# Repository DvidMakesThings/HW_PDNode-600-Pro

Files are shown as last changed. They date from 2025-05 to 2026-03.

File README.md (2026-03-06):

# PDNode-600 Pro  
## High-Performance USB PD Power Distribution Unit – 10" Rackmount



## Description  
[ENERGIS](https://github.com/DvidMakesThings/HW_10-In-Rack_PDU) is the 230V managed PDU project. PDNode-600 Pro is the modular DC/USB-C sibling for setups
where mains switching is not desired, but controllable, rack-friendly power output is still needed.

The PDNode-600 is a professional-grade, 600W USB Power Delivery Unit designed specifically for compact 10-inch rack systems, targeting embedded developers, homelab enthusiasts, test benches, and smart infrastructure. It delivers regulated, high-current power across 8x independent USB-C PD outputs and 4x fixed 5V USB-A outputs.

At the core of the PDNode platform is a centralized industrial-grade 24V/25A power supply, distributing regulated DC to dedicated per-port buck or buck-boost converters. Each USB-C port is managed by an MPQ4242-AEC1 PD controller, enabling clean, autonomous negotiation of power profiles up to 20V @ 3A or 5A with eMarker cable support. All power conversion, protection, and monitoring are designed to meet high reliability and safety standards.

The PDNode-600 Pro, by contrast, is built for remote-managed racks and headless environments, featuring Ethernet connectivity, a clean web-based UI, SNMP integration, and firmware updates via USB-C. Doing this by using [BladeCore-M54E](https://github.com/DvidMakesThings/HW_BladeCore-M54E)

## Web UI sneak peek

Interactive playground (dummy UI):
- https://dvidmakesthings.github.io/HW_PDNode-600-Pro/playground/

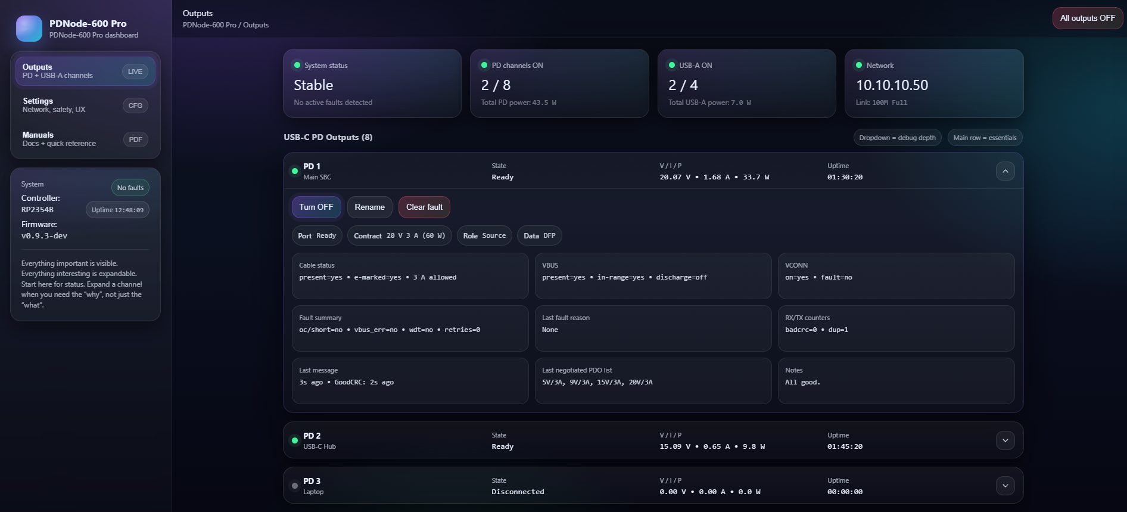
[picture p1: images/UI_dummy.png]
Try out the UI


## Project timeline estimation

Status legend: ✅ Completed · 🟠 Ongoing · 🔵 Planned

| #  | Milestone | Planned Start | Planned End | Status | Notes |
|:--:|---|---|---|---|---|
| 1  | Architecture definition | 12-2025 | 01-2026 | ✅ Completed | |
| 2  | Baseboard PCB design | 15-02-2026 | TBD | ✅ Completed | |
| 3  | PD card PCB design | 25-02-2026 | TBD | ✅ Completed | |
| 4  | Documentation | 12-2025 | 2026.12 | 🟠 Ongoing | |
| 5  | PCB ordering | 01-03-2026 | 31-03-2026  | ✅ Completed | Waiting for arrival |
| 6  | Prototyping and hardware bring-up | 03-2026 | 30-04-2026  | 🟠 Ongoing | |
| 7  | Firmware bring-up (slot scan, mux, PD iface) | 06-2026 | 11-2026 | 🔵 Planned | |
| 8  | Telemetry and status reporting | 06-2026 | 11-2026 | 🔵 Planned | |
| 9  | Validation (load, thermal, long-run) | 06-2026 | 11-2026 | 🔵 Planned | |
| 10 | Integration and polishing | 06-2026 | 11-2026 | 🔵 Planned | |
| 11 | Release package and final docs | 11-2026 | 12-2026 | 🔵 Planned | |

## Specifications 

### Input
- **Input voltage:** 230 VAC, max 4A 
- **System topology:** 24V distribution on the baseboard, per-slot conversion on PD cards

### Output (per PD card / per slot)
- **8x independent USB-C PD source**:
  - 5V 3A (5A only with 5A e-marked cable)
  - 9V 3A (5A only with 5A e-marked cable)
  - 12V 3A (5A only with 5A e-marked cable)
  - 15V 3A (5A only with 5A e-marked cable)
  - 20V 3A (5A only with 5A e-marked cable)
  - (Total power output cannot exceed 600W)
- **4x USB-A source** up to **5V / 1A** per port (depending on configuration and limits)

---

## Features
- **8x independent USB-C PD source ports** (modular PD cards, one port per slot)
- **Per-port PD profiles**
- **Total system capability: up to 600W** (shared input power budget)
- **4x USB-A auxiliary outputs** (5V, 1A per port) for low-power devices
- **Ethernet connectivity** for control / monitoring
- **USB service interface** (debug, configuration, firmware update, or log access depending on implementation)
- **Per-port power monitoring** (current/voltage telemetry via onboard sensing)
- **Per-port status reporting** (PGOOD / fault indication, and software-readable status)
- **Hot-swappable slot concept** (cards can be replaced without redesigning the baseboard)

---

## Hardware architecture

### Baseboard
- 24V DC input from industrial power supply
- Power distribution to all slots (high-current bus)
- Slot connectors + slot management (card detect, enable, status aggregation)
- I2C fanout per slot (mux) for monitoring and controlling devices
- Ethernet interface for user interaction
- USB/service interface for debug/config/updates
- 4x USB-A outputs
- 8x USB-C PD outputs

### [BladeCore-M54E](https://github.com/DvidMakesThings/HW_BladeCore-M54E)
- RP2354B microcontroller
- External QSPI flash memory
- External I²C EEPROM
- 100BASE Ethernet via W5500
- Dual‑path USB connectivity with automatic source selection
- Onboard power regulation and defined power‑up sequencing
- Compact M.2 M-key form factor

### PD Card
- 1x USB-C PD source port (one card = one port)
- Local power conversion to generate VBUS from the 24V bus
- PD controller + USB-C port control signals (enable, reset, IRQ)
- Per-port current/voltage measurement
- Per-port power good / fault status output
- Optional ID EEPROM footprint (DNI) for traceability/calibration

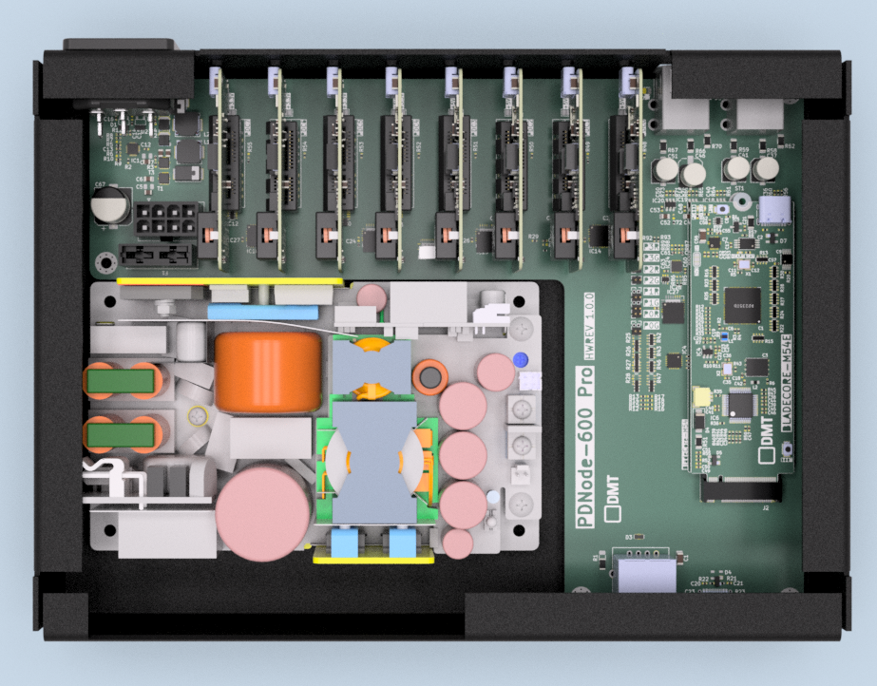
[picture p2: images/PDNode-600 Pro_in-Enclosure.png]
PDNode-600 Pro in Enclosure

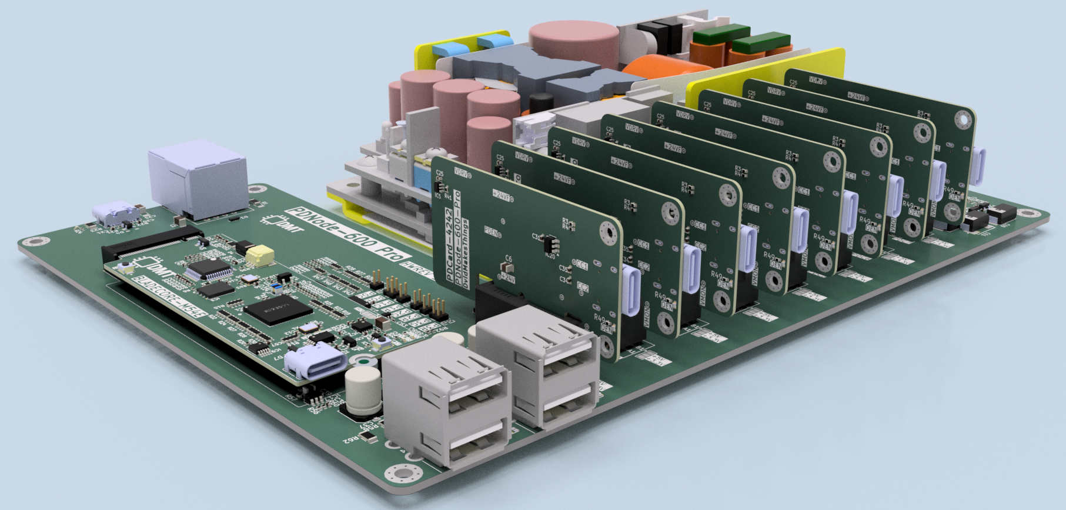
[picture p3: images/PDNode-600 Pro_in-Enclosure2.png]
PDNode-600 Pro in Enclosure


## Schematics
The full schematics are available:
- **[Baseboard Schematics](src/PDF/SCH_PDNode_Baseboard_100.pdf)** 
- **[PDCard-4242 Schematics](src/PDF/SCH_PDCard-4242_100.pdf)**
- **[BladeCore-M54E Schematics](src/PDF/SCH_BladeCore-M54_100.pdf)**

PCB Documentation:
- **[Baseboard PCB](src/PDF/PCB_PDNode_Baseboard_100.pdf)** 
- **[PDCard-4242 PCB](src/PDF/PCB_PDCard-4242_100.pdf)**
 **[]()**

---

## Development Phases (Hardware + Firmware)

| Hardware Phase | Status | Firmware Phase | Status |
| --- | --- | --- | --- |
| Architecture definition | ✅ Completed | Slot scan concept (TCA9548A) | 🔵 Planned |
| Baseboard PCB Design | ✅ Completed | I2C driver + mux control | 🔵 Planned |
| PD Card PCB Design | ✅ Completed | INA219 monitoring | 🔵 Planned |
| Documentation | 🟠 Ongoing | PD controller interface (SPI + GPIO) | 🔵 Planned |
| PCB ordering | ✅ Completed | Telemetry + status reporting | 🔵 Planned |
| Prototyping and Hardware Bring-up | 🟠 Ongoing | Bring-up scripts / debug tooling | 🔵 Planned |
| Validation (load, thermal, long-run) | 🔵 Planned | Error handling + fault reporting | 🔵 Planned |
| Production optimization | 🔵 Planned | Integration and polishing | 🔵 Planned |

---

## Changelog 
#### Rev0.1.0:
- Initial design
- STUSB4710 controller + TPS552882

#### Rev1.0.0:
- Full redesign. STUSB4710 became EOL, need to use different PD controller
- New concept: modular Baseboard + PDCard architecture
- PDCard power stage (MPQ4242-AEC1)
- Baseboard: Per-slot I2C muxing (TCA9548A)
- Optional per-card EEPROM (not used, but capable)

<table>
  <tr>
    <td align="center">
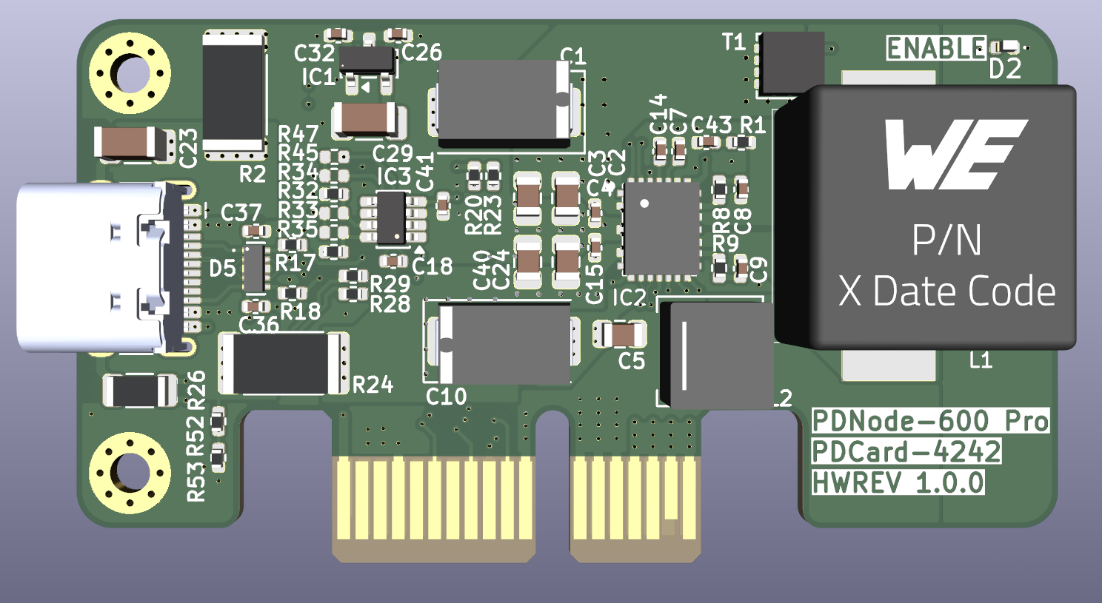
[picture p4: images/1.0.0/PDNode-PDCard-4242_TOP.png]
PDCard 3D Top View
      
      <br><b>PDCard Top</b>
    </td>
    <td align="center">
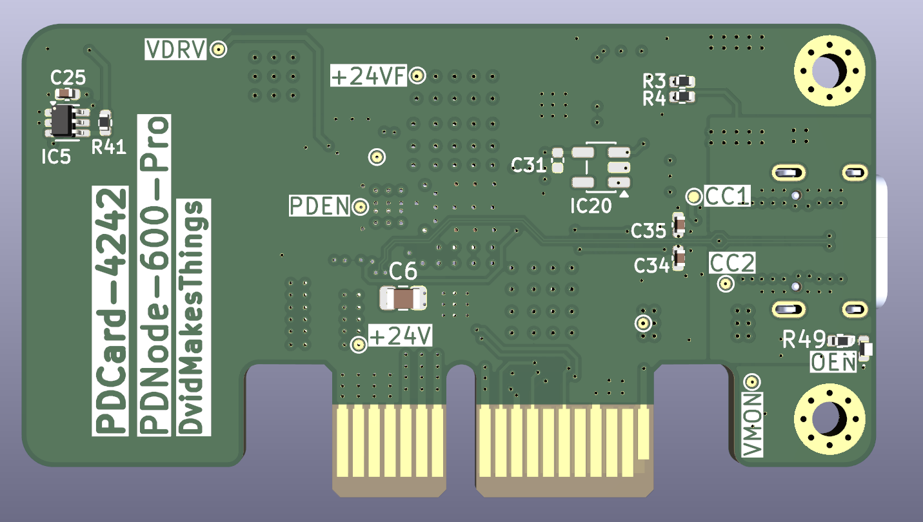
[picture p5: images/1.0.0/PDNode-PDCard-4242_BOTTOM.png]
PDCard 3D Bottom View
      
      <br><b>PDCard Bottom</b>
    </td>
  </tr>
  <tr>
    <td align="center" width="50%">
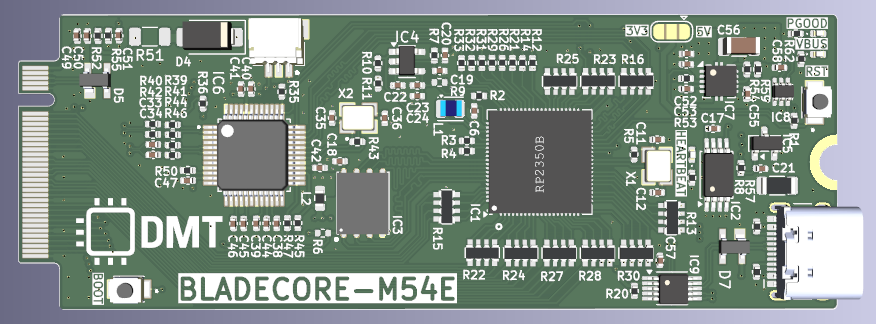
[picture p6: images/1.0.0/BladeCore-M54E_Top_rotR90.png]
BladeCore-M54E Top View
      
      <br><b>BladeCore-M54E Top</b>
    </td>
    <td align="center" width="50%">
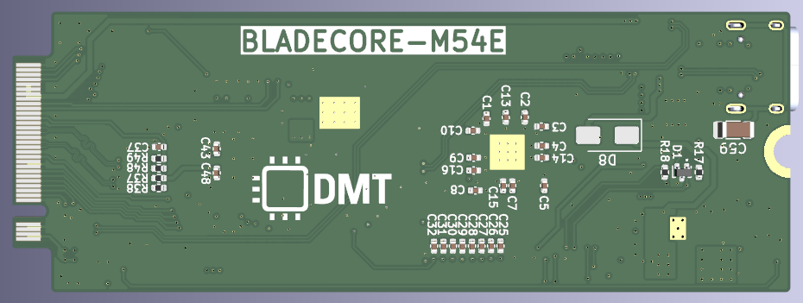
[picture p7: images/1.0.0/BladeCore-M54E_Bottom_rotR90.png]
BladeCore-M54E Bottom View
      
      <br><b>BladeCore-M54E Bottom</b>
    </td>
  </tr>
  <tr>
    <td align="center">
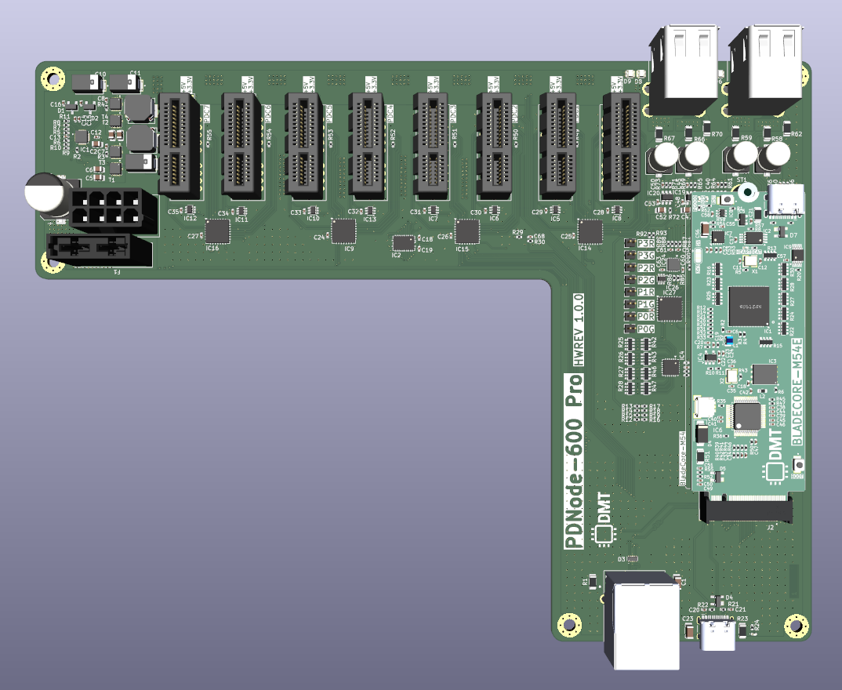
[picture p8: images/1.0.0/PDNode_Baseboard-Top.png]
BaseBoard 3D Top View
      
      <br><b>BladeCore-M54E Top</b>
    </td>
    <td align="center">
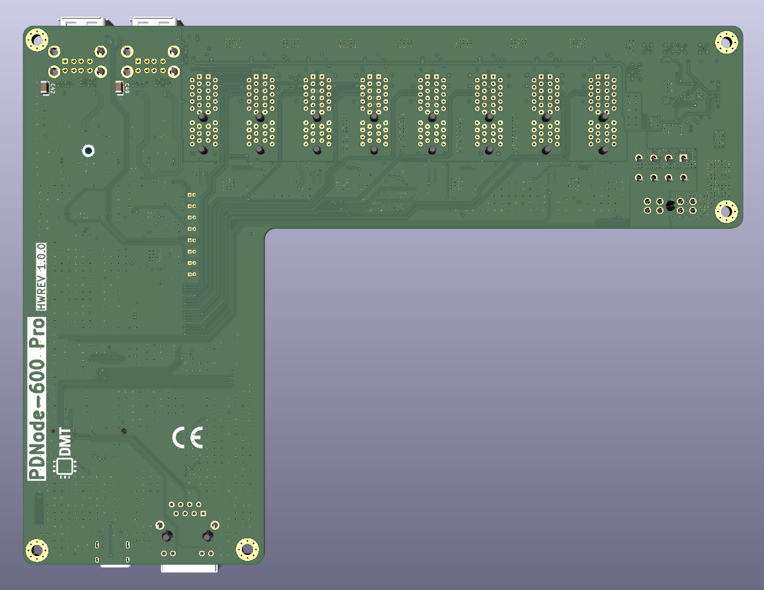
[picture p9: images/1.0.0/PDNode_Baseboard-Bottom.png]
BaseBoard 3D Bottom View
      
      <br><b>BladeCore-M54E Bottom</b>
    </td>
  </tr>
</table>

## License
### Software Components
This project's software is licensed under the **GNU Affero General Public License v3.0 (AGPL-3.0)**.
See the [Software License](LICENSE-AGPL) file for details.

#### What AGPL-3.0 means:

- ✅ **You can** freely use, modify, and distribute this software
- ✅ **You can** use this project for personal, educational, or internal purposes
- ✅ **You can** contribute improvements back to this project

- ⚠️ **You must** share any modifications you make if you distribute the software
- ⚠️ **You must** release the source code if you run a modified version on a server that others interact with
- ⚠️ **You must** keep all copyright notices intact

- ❌ **You cannot** incorporate this code into proprietary software without sharing your source code
- ❌ **You cannot** use this project in a commercial product without either complying with AGPL or obtaining a different license

### Hardware Components
Hardware designs, schematics, and related documentation are licensed under the **Creative Commons Attribution-NonCommercial-ShareAlike 4.0 International License (CC BY-NC-SA 4.0 International License)**. See the [Hardware License](LICENSE-CC-BY-NC-SA) file for details.

#### What CC BY-NC-SA 4.0 means:

- ✅ **You can** study, modify, and distribute the hardware designs
- ✅ **You can** create derivative works for personal, educational, or non-commercial use
- ✅ **You can** build this project for your own personal use

- ⚠️ **You must** give appropriate credit and indicate if changes were made
- ⚠️ **You must** share any modifications under the same license terms
- ⚠️ **You must** include the original license and copyright notices

- ❌ **You cannot** use the designs for commercial purposes without explicit permission
- ❌ **You cannot** manufacture and sell products based on these designs without a commercial license
- ❌ **You cannot** create closed-source derivatives for commercial purposes
- ❌ **You cannot** use the designer's trademarks without permission

### Commercial & Enterprise Use

Commercial use of this project is prohibited without obtaining a separate commercial license. If you are interested in:

- Manufacturing and selling products based on these designs
- Incorporating these designs into commercial products
- Any other commercial applications

Please contact me through any of the channels listed in the [Contact](#contact) section to discuss commercial licensing arrangements. Commercial licenses are available with reasonable terms to support ongoing development.

## Contact

For questions or feedback:
- **Email:** [dvidmakesthings@gmail.com](mailto:dvidmakesthings@gmail.com)
- **GitHub:** [DvidMakesThings](https://github.com/DvidMakesThings)

## Contributing

Contributions are welcome! As this is an early-stage project, please reach out before 
making substantial changes:

1. Fork the repository
2. Create a feature branch (`git checkout -b feature/concept`)
3. Commit your changes (`git commit -m 'Add concept'`)
4. Push to the branch (`git push origin feature/concept`)
5. Open a Pull Request with a detailed description

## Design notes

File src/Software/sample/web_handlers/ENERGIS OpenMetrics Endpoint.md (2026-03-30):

# ENERGIS OpenMetrics Endpoint

## Overview

The ENERGIS PDU exposes a `/metrics` HTTP endpoint that provides runtime telemetry in OpenMetrics/Prometheus text format (version 0.0.4). This plugs directly into Prometheus, Grafana, and similar tools.

## Configuration

### Accessing the Endpoint

```bash
curl.exe http://<pdu-ip-address>/metrics
```

### Example response

```
# HELP energis_up 1 if the metrics handler is healthy.
# TYPE energis_up gauge
energis_up 1
# HELP energis_build_info Build and device identifiers.
# TYPE energis_build_info gauge
energis_build_info{version="1.0.0",serial="SN-0167663"} 1
# HELP energis_uptime_seconds_total System uptime in seconds.
# TYPE energis_uptime_seconds_total counter
energis_uptime_seconds_total 27
# HELP energis_internal_temperature_celsius Internal temperature (calibrated).
# TYPE energis_internal_temperature_celsius gauge
energis_internal_temperature_celsius 30.668
# HELP energis_temp_calibrated 1 if temperature calibration is applied.
# TYPE energis_temp_calibrated gauge
energis_temp_calibrated 1
# HELP energis_temp_calibration_mode Calibration mode: 0=none, 1=1pt, 2=2pt.
# TYPE energis_temp_calibration_mode gauge
energis_temp_calibration_mode 1
# HELP energis_vusb_volts USB rail voltage.
# TYPE energis_vusb_volts gauge
energis_vusb_volts 5.332
# HELP energis_vsupply_volts 12V supply rail voltage.
# TYPE energis_vsupply_volts gauge
energis_vsupply_volts 12.093
# HELP energis_http_requests_total Total HTTP requests served.
# TYPE energis_http_requests_total counter
energis_http_requests_total 17
# HELP energis_channel_state Relay state (1=ON, 0=OFF).
# TYPE energis_channel_state gauge
energis_channel_state{ch="1"} 1
# HELP energis_channel_telemetry_valid 1 if cached telemetry for channel is fresh.
# TYPE energis_channel_telemetry_valid gauge
energis_channel_telemetry_valid{ch="1"} 1
# HELP energis_channel_voltage_volts Channel voltage.
# TYPE energis_channel_voltage_volts gauge
energis_channel_voltage_volts{ch="1"} 0.000
# HELP energis_channel_current_amps Channel current.
# TYPE energis_channel_current_amps gauge
energis_channel_current_amps{ch="1"} 0.000
# HELP energis_channel_power_watts Active power per channel.
# TYPE energis_channel_power_watts gauge
energis_channel_power_watts{ch="1"} 0.000
# HELP energis_channel_energy_watt_hours_total Accumulated energy per channel.
# TYPE energis_channel_energy_watt_hours_total counter
energis_channel_energy_watt_hours_total{ch="1"} 0.000
...
```

## Prometheus Integration

Add to `prometheus.yml`:

```yaml
scrape_configs:
  - job_name: 'energis-pdu'
    scrape_interval: 15s
    scrape_timeout: 10s
    metrics_path: /metrics
    static_configs:
      - targets: ['192.168.0.22:80']
        labels:
          location: 'rack-1'
          device: 'pdu-main'
```

## Available Metrics

### System

* `energis_up` - Health indicator (gauge; 1 if handler responds)
* `energis_build_info{version,serial}` - Build and device info (gauge; always 1)
* `energis_uptime_seconds_total` - Uptime since boot in seconds (counter)
* `energis_internal_temperature_celsius` - Internal MCU temperature, calibrated (gauge)
* `energis_temp_calibrated` - 1 if temperature calibration is applied (gauge)
* `energis_temp_calibration_mode` - Calibration mode (0=none, 1=1pt, 2=2pt) (gauge)
* `energis_vusb_volts` - USB rail voltage (gauge)
* `energis_vsupply_volts` - 12 V rail voltage (gauge)
* `energis_http_requests_total` - Total HTTP requests served (counter)

### Per-Channel (ch = "1" ... "8")

* `energis_channel_state{ch}` - Relay state: 1=ON, 0=OFF (gauge)
* `energis_channel_telemetry_valid{ch}` - 1 if cached telemetry for channel is fresh (gauge)
* `energis_channel_voltage_volts{ch}` - Channel voltage [V] (gauge)
* `energis_channel_current_amps{ch}` - Channel current [A] (gauge)
* `energis_channel_power_watts{ch}` - Active power [W] (gauge)
* `energis_channel_energy_watt_hours_total{ch}` - Accumulated energy in watt-hours (counter)

## Notes and Behavior

* Values are served from cached snapshots owned by `MeterTask`. No direct sensor I/O in the handler.
* Temperature uses the active calibration. If no calibration is stored, defaults are used.

## Handy PromQL

* MCU temperature:
  `energis_internal_temperature_celsius`
* Rails:
  `energis_vusb_volts`, `energis_vsupply_volts`
* Total active power across all channels:
  `sum(energis_channel_power_watts)`
* Telemetry freshness check:
  `sum(energis_channel_telemetry_valid) == 8`

## Example Alerts

```yaml
groups:
- name: energis
  rules:
  - alert: EnergisHighTemp
    expr: energis_internal_temperature_celsius > 70
    for: 2m
    labels: {severity: warning}
    annotations:
      summary: "ENERGIS MCU hot >70C"

  - alert: EnergisVsupplyLow
    expr: energis_vsupply_volts < 10.8
    for: 1m
    labels: {severity: critical}
    annotations:
      summary: "ENERGIS 12V rail low"

  - alert: EnergisNoTelemetry
    expr: sum(energis_channel_telemetry_valid) < 8
    for: 2m
    labels: {severity: warning}
    annotations:
      summary: "ENERGIS channel telemetry not fully valid"
```

## Performance

* Static buffer ~4 KB. No heap allocations.
* Non-blocking, minimal CPU load.
* Typical response time < 50 ms.
* If the output would overflow the buffer, the handler returns **503** to encourage a retry instead of serving a partial payload.

## Implementation Notes

* Reads from `MeterTask_GetTelemetry()` and `MeterTask_GetSystemTelemetry()`.
* Uses atomic counters for request accounting.
* OpenMetrics text format compatible with Prometheus 0.0.4.

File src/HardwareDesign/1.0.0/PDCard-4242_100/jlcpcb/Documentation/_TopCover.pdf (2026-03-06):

## PDCard-4242 Schematic Documentation

| Top Preview | Bottom Preview |

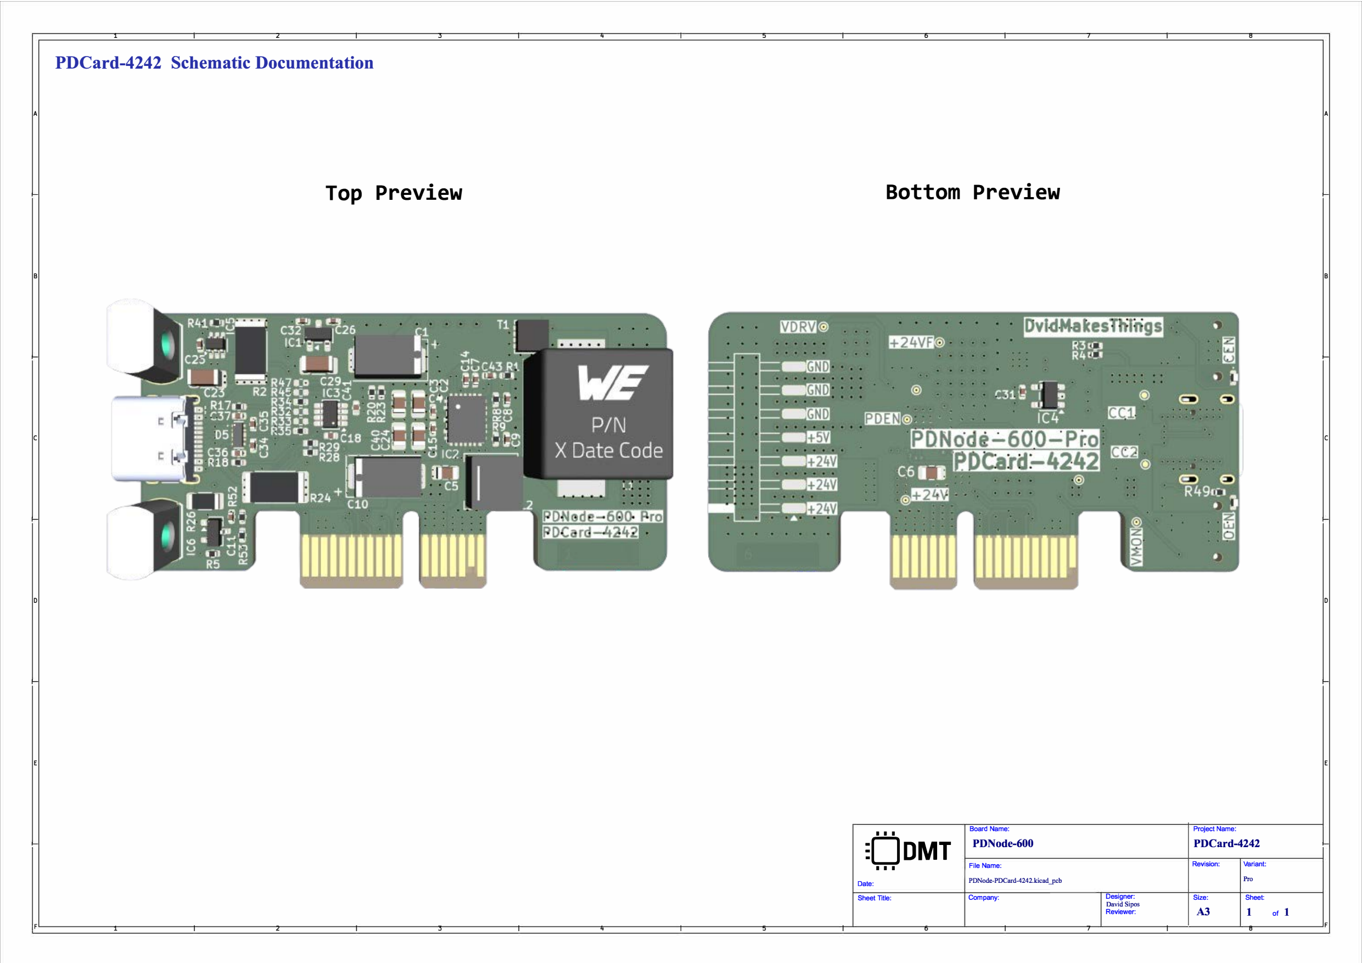
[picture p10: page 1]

1 | I | 2 | I | 3 | I | 4 | I | 5 | I | 6 | I | 7 | I | B
A | A
B | B
C | C
>- | >-
D | D
>- | >-
E | E
I I I | Board Name: | Project Name:
| :ODMT PDNode-600 | PDCard-4242 |
File Name: | Revision: | Variant:

I I I
Date: | PDNode-PDCard-4242.kicad_pcb | Pro
Sheet Title: | Company: | Designer: | Size: | Sheet:
David Sipos
Reviewer: | A3 | 1 | of 1
1 | I | 2 | I | 3 | I | 4 | I | 5 | I | 6 | I | 7 | I | B

F

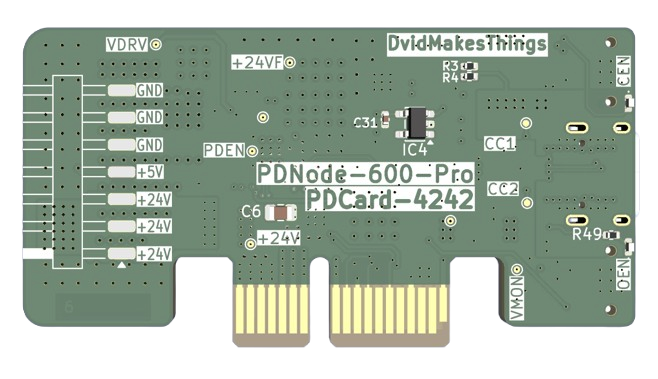
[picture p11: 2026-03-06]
src/HardwareDesign/1.0.0/PDCard-4242_100/Images/PDNode-PDCard-4242_BOTTOM-removebg-preview.png

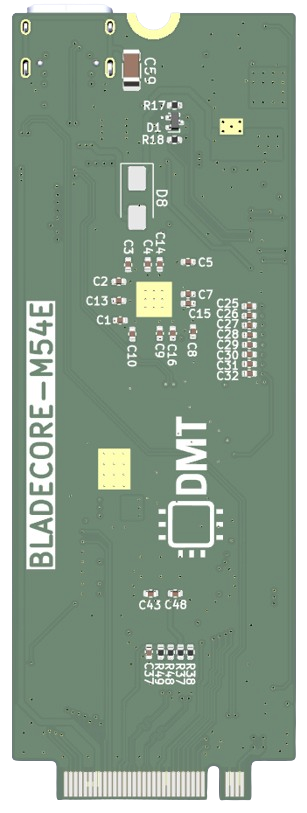
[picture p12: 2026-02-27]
src/HardwareDesign/1.0.0/BladeCore-M54_100/Images/BladeCore-M54E_Bottom-removebg.png

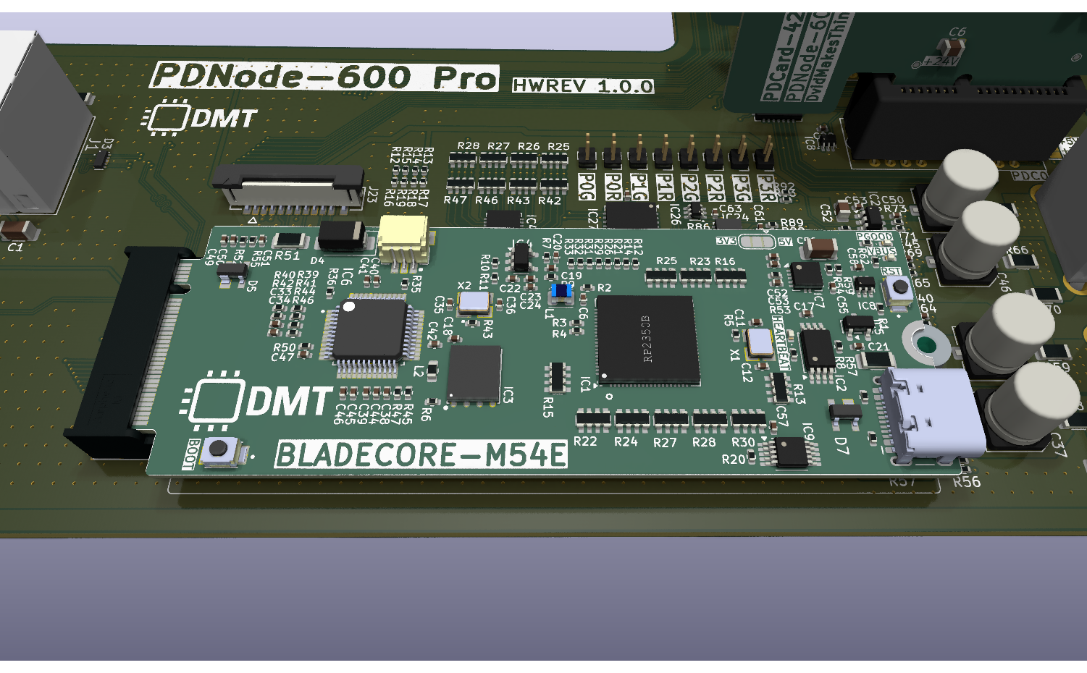
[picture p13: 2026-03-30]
src/HardwareDesign/1.0.0/PDNode-600_Pro_Baseboard_100/Images/PDNode_Baseboard2.png

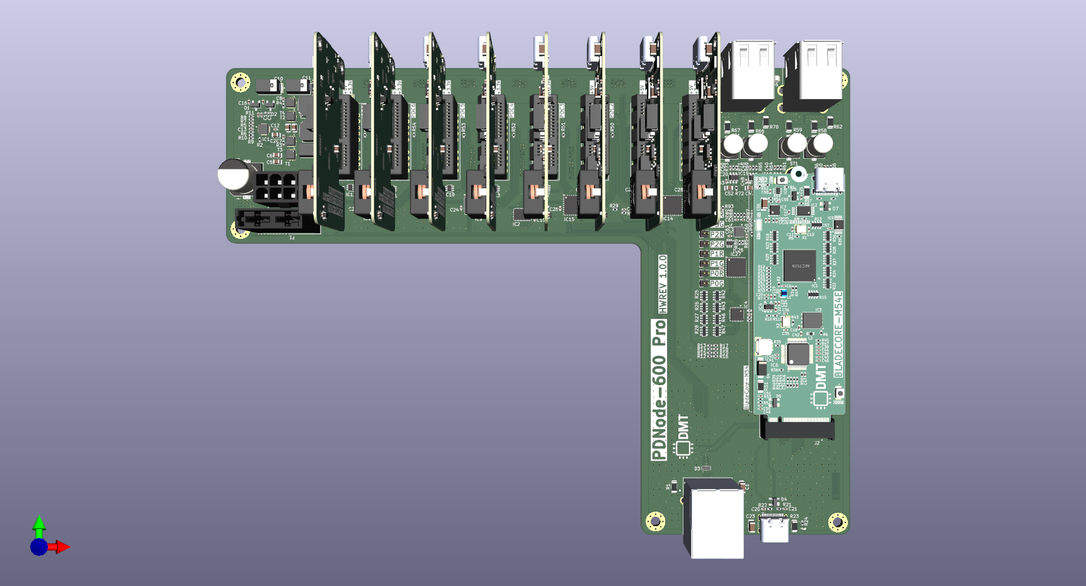
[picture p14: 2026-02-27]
src/HardwareDesign/1.0.0/PDNode-600_Pro_Baseboard_100/Images/PDNode_Baseboard-With_PDCard.png

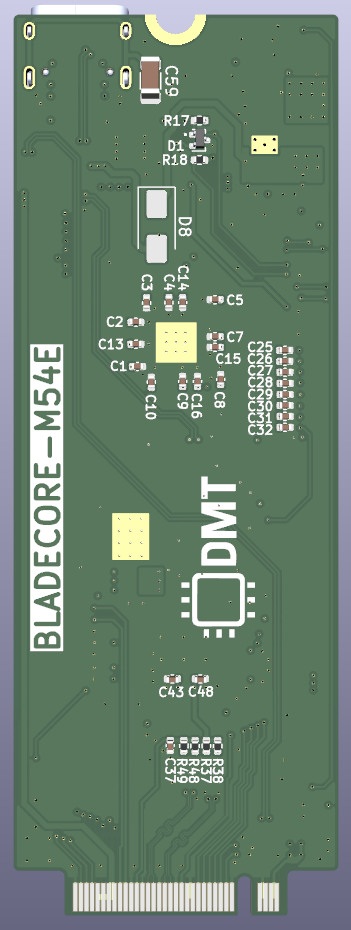
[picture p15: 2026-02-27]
src/HardwareDesign/1.0.0/BladeCore-M54_100/Images/BladeCore-M54E_Bottom.png

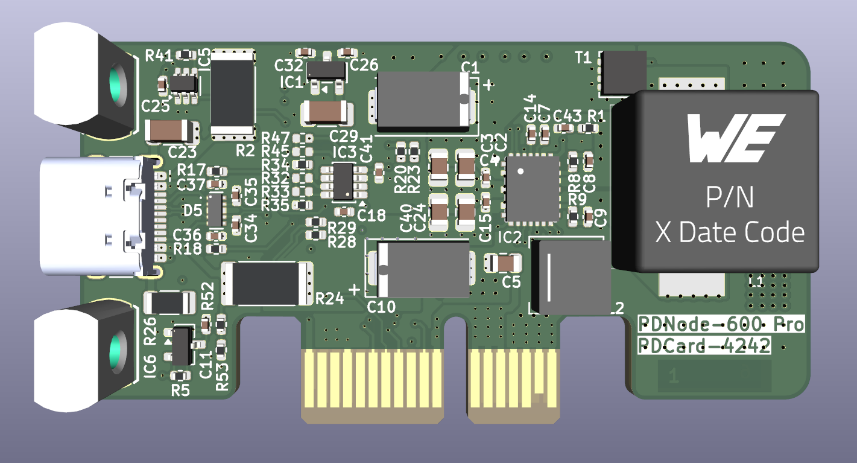
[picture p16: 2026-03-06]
src/HardwareDesign/1.0.0/PDCard-4242_100/Images/PDNode-PDCard-4242_TOP.png

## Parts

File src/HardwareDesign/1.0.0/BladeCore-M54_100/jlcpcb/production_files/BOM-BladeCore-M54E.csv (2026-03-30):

Comment | Designator | Footprint | LCSC | Quantity
0R 1% | R40,R42 | R_0402_1005Metric | C17168 | 2
0R 1% | R51 | R_1206_3216Metric | C205296 | 1
1.5K/100MHz 0.5R | L2 | R_0603_1608Metric | C82155 | 1
100R 1% | R13,R15,R16,R22,R23,R24,R25,R27,R28,R30 | R_Array_Convex_4x0603 | C136838 | 10
100R 1% | R12,R14,R21,R26,R29,R31,R32,R33 | R_0402_1005Metric | C25076 | 8
100nF 50V | C1,C10,C13,C14,C15,C17,C18,C19,C2,C21,C23,C3,C37,C38,C4,C40,C41,C42,C43,C44,C45,C46,C47,C48,C5,C51,C52,C57,C58,C60,C7,C8,C9 | C_0402_1005Metric | C307331 | 33
10K 1% | R10,R11,R53 | R_0402_1005Metric | C25744 | 3
10pF 50V | C11,C12 | C_0402_1005Metric | C466222 | 2
10uF 50V | C56 | C_1206_3216Metric | C13585 | 1
12.4K 1% | R50 | R_0402_1005Metric | C490814 | 1
12MHz 10pF | X1 | X3225 | C20625731 | 1
15pF 50V | C35,C36 | C_0402_1005Metric | C1548 | 2
1K 1% | R34,R5,R58,R60,R61 | R_0402_1005Metric | C11702 | 5
1M 1% | R57 | R_1206_3216Metric | C17927 | 1
1M 1% | R43 | R_0402_1005Metric | C26083 | 1
1nF 2kV | C59 | C_1206_3216Metric | C173242 | 1
1nF 50V | C25,C26,C27,C28,C29,C30,C31,C32 | C_0402_1005Metric | C14442 | 8
1uF 50V | C53 | C_0402_1005Metric | C1518208 | 1
2.2K 1% | R17,R18 | R_0402_1005Metric | C25879 | 2
2.2nF 50V | C55 | C_0402_1005Metric | C106861 | 1
2.4K 1% | R59 | R_0402_1005Metric | C25882 | 1
25MHz 12pF | X2 | X3225 | C9006 | 1
27R 1% | R7 | R_0402_1005Metric | C138021 | 1
3.3R 1% | R39,R41,R44,R46 | R_0402_1005Metric | C270612 | 4
3.3uH 2.8A | L1 | 0805 | C42411119 | 1
33R 1% | R2,R3,R4 | R_0402_1005Metric | C25105 | 3
4.7K 1% | R1,R35,R8 | R_0402_1005Metric | C25900 | 3
4.7uF 10V | C20,C22,C24 | C_0402_1005Metric | C368809 | 3
4.7uF 25V | C16,C39,C49,C50,C54,C6 | C_0402_1005Metric | C22367824 | 6
470R 1% | R36,R45,R47 | R_0402_1005Metric | C25117 | 3
49.9R 1% | R37,R38,R48,R49 | R_0402_1005Metric | C25120 | 4
5.1K 1% | R19,R20,R52,R55,R56 | R_0402_1005Metric | C25905 | 5
6.8nF 50V | C33,C34 | C_0402_1005Metric | C1542 | 2
7.5K 1% | R54 | R_0402_1005Metric | C25918 | 1
AT24C256C-XHL-T | IC2 | TSSOP-8 | C33035 | 1
B3U-1000P | SW1,SW2 | SW_B3U-1000P | C231329 | 2
Blue | D3 | LED_0402_1005Metric | C22355736 | 1
FSUSB42MUX | IC9 | MSOP-10_3x3mm_P0.5mm | C11355 | 1
Green | D10,D11,D6 | LED_0402_1005Metric | C965793 | 3
LM4040B30FTA | IC5 | SOT-23 | C460604 | 1
MCP6001RT | IC4 | SOT-23-5 | C154973 | 1
RCLAMP0582BQTCT | D1 | SOT-416 | C841193 | 1
RP2354B | IC1 | QFN80_10x10 | C39843328 | 1
SM03B-SRSS-TB | J2 | JST_SM03B-SRSS-TB_LF__SN_ | C160403 | 1
SN74LVC1G97QDCKRQ1 | IC10,IC8 | SOT-363_SC-70-6 | C179911 | 2
SP0503BAHTG | D5,D7 | SOT143 | C3040626 | 2
TPS74801DRCT | IC7 | VSON-10-1EP_3x3mm_P0.5mm_EP1.65x2.4mm_ThermalVias | C882845 | 1
USB-TYPE-C-018 | J3 | USB_C_Receptacle_HCTL_HC-TYPE-C-16P-01A | C2927038 | 1
W25Q128JVPIQ | IC3 | WSON8_6x5 | C190862 | 1
W5500 | IC6 | LQFP48_7x7 | C32843 | 1

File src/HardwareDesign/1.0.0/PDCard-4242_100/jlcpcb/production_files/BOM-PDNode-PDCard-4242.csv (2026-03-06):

Comment | Designator | Footprint | LCSC | Quantity
0.005R 1% 2W | R24 | R_2512_6332Metric | C108931 | 1
0.010R 1% | R2 | R_2512_6332Metric | C127692 | 1
0R 1% | R8,R9 | R_0402_1005Metric | C17168 | 2
100K 1% | R20,R23 | R_0402_1005Metric | C25741 | 2
100nF 50V | C11,C15,C18,C25,C31,C32,C4,C41 | C_0402_1005Metric | C307331 | 8
100uF 25V | C1,C10 | CP_EIA-7343-30_AVX-N | C696814 | 2
10K 1% | R34,R35,R5,R53 | R_0402_1005Metric | C25744 | 4
10uF 50V | C29 | C_1206_3216Metric | C13585 | 1
10uF 50V | C24,C40 | C_0805_2012Metric | C440198 | 2
1K 1% | R41,R49 | R_0402_1005Metric | C11702 | 2
1M 1% | R26 | R_1206_3216Metric | C17927 | 1
1R 1% | R1,R28,R29,R3,R4 | R_0402_1005Metric | C185446 | 5
1nF 2kV | C23 | C_1206_3216Metric | C173242 | 1
1nF 50V | C34,C35,C43 | C_0402_1005Metric | C14442 | 3
1uF 50V | C26 | C_0402_1005Metric | C1518208 | 1
2.2R 1% | R17,R18 | R_0402_1005Metric | C2909330 | 2
2.2uF 25V | C7 | C_0402_1005Metric | C385032 | 1
2.2uH 9.7A | L2 | 5.5x5.3mm_XAL5030-222MEC | C920280 | 1
220nF 50V | C8,C9 | C_0402_1005Metric | C5159775 | 2
390pF 50V | C36,C37 | C_0402_1005Metric | C107050 | 2
4.7uF 50V | C2,C3,C5,C6 | C_0805_2012Metric | C98192 | 4
4.7uH 13A | L1 | 7443551470 | C1331156 | 1
470pF 50V | C14 | C_0402_1005Metric | C106207 | 1
90.9K 1% | R52 | R_0402_1005Metric | C163452 | 1
Blue | D2 | LED_0402_1005Metric | C22355736 | 1
DMN4008LFG-7 | T1 | Diodes_PowerDI3333-8 | C6601822 | 1
Green | D1 | LED_0402_1005Metric | C965793 | 1
INA219BIDCNT | IC3 | SOT-23-8 | C2653868 | 1
M3 | ST1,ST2 | WP-SMRA_7466313 | C6467859 | 2
MCP1702T-3302E/CB | IC1 | SOT-23 | C33844 | 1
MPQ4242GVE-0001-AEC1-P | IC2 | QFN-22_4X5mm | C37449370 | 1
SN74LVC1G97QDCKRQ1 | IC5 | SOT-363_SC-70-6 | C179911 | 1
STM809TWX6F | IC6 | SOT-23 | C118271 | 1
TPD4EUSB30DQAR | D5 | USON10_2.5x1 | C5199222 | 1
USB-TYPE-C-018 | J1 | USB_C_Receptacle_HCTL_HC-TYPE-C-16P-01A | C2927038 | 1

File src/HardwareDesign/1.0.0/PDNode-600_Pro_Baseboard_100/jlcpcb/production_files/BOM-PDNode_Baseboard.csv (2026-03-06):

Comment | Designator | Footprint | LCSC | Quantity
0.02R 1% | R58,R59,R66,R67 | R_1206_3216Metric | C844895 | 4
0525592052 | J23 | CON_525592052_MOL | C588204 | 1
0ATO030.VP | F1 | 178.6165.0001-Littelfuse | C207060 | 1
10018784-10200TLF | J10,J11,J4,J5,J6,J7,J8,J9 | AMPHENOL_10018784-10210TLF | C5437695 | 8
100R 1% | R42,R43,R46,R47 | R_Array_Convex_4x0603 | C136838 | 4
100R 1% | R75,R79,R80,R81,R84,R87,R88,R89 | R_0402_1005Metric | C25076 | 8
100nF 50V | C14,C15,C16,C17,C19,C24,C25,C26,C27,C28,C29,C30,C31,C32,C33,C34,C35,C36,C39,C40,C44,C45,C48,C50,C53,C55,C56,C58,C60,C62,C63,C64,C65,C68,C7,C8 | C_0402_1005Metric | C307331 | 36
100uF 25V | C37,C41,C46,C51 | C_Elec_6.3x7.7 | C72477 | 4
10K 1% | R10,R11,R12,R13,R14,R15,R16,R17,R18,R19,R2,R48,R49,R50,R51,R52,R53,R54,R55,R7 | R_0402_1005Metric | C25744 | 20
10nF 50V | C54,C57,C59,C61 | C_0402_1005Metric | C60133 | 4
10uF 50V | C2,C3,C38,C4,C43,C47,C5,C52,C6 | C_0805_2012Metric | C440198 | 9
15.4K 1% | R5 | R_0402_1005Metric | C22369478 | 1
1724470208 | J22 | MOLEX_1724470208 | C17445611 | 1
1K 1% | R24,R74,R77,R82,R83,R90,R91,R92,R93 | R_0402_1005Metric | C11702 | 9
1M 1% | R1,R23,R62,R70 | R_1206_3216Metric | C17927 | 4
1nF 2kV | C1,C23,C42,C49 | C_1206_3216Metric | C173242 | 4
1nF 50V | C12,C13 | C_0402_1005Metric | C14442 | 2
2.2K 5% | R25,R26,R27,R28 | R_Array_Convex_4x0603 | C12001 | 4
2.2R 1% | R3,R4 | R_0402_1005Metric | C2909330 | 2
2.2uH 9.5A | L1 | 7x6.6mm | C167218 | 1
3.3uH 13A | L2 | 7x6.6mm | C41413136 | 1
33.2K 1% | R60,R64,R69,R73 | R_0402_1005Metric | C324836 | 4
330uF 50V | C67 | CP_Elec_10x10.5 | C178596 | 1
330uF 6.3V | C10,C11 | 2917 | C134173 | 2
33R 1% | R44,R45,R76,R78,R85,R86 | R_0402_1005Metric | C25105 | 6
4.7K 1% | R56,R57,R61,R63,R65,R68,R71,R72 | R_0402_1005Metric | C25900 | 8
4.7uF 25V | C18,C20,C21 | C_0402_1005Metric | C22367824 | 3
470uF 4V | C9 | 2917 | C542275 | 1
47K 1% | R9 | R_0402_1005Metric | C25792 | 1
5.1K 1% | R21,R22,R30 | R_0402_1005Metric | C25905 | 3
51K 1% | R29,R8 | R_0402_1005Metric | C25794 | 2
6.57K 0.1% | R6 | R_0402_1005Metric | C852899 | 1
AF SS-JB17.6 | J12,J13 | USB_A_Horizontal_Stacked | C456021 | 2
AP22653W6-7 | IC17,IC18,IC19,IC20 | SOT-23-6 | C2158037 | 4
BAT54S | D1,D2 | SOT23-3 | C7420333 | 2
Blue | D5 | LED_0402_1005Metric | C22355736 | 1
CD74HC4067QRGYRQ1 | IC2 | Texas_RGY_R-PVQFN-N24_EP2.05x3.1mm_ThermalVias | C48731605 | 1
FDMC7672 | T3,T4 | DFN8_3x3 | C890946 | 2
FDMC7692 | T1,T2 | DFN8_3x3 | C241798 | 2
J1B1211CCD | J1 | J1B1211CCD | C910371 | 1
M2.5 | ST1 | Round Standoff Threaded M2.5 Steel | C7435234 | 1
MCP23017T-E/ML | IC14,IC15,IC16,IC27,IC9 | QFN-28-1EP_6x6mm_P0.65mm_EP4.25x4.25mm_ThermalVias | C629439 | 5
MDT580M01001 | J2 | BladeCore-M54E-5.8mm | C5177196 | 1
PAC1720-1-AIA-TR | IC22,IC24 | DFN-10-1EP_3x3mm_P0.5mm_EP1.58x2.35mm_ThermalVias | C622574 | 2
Red-Green | D6,D7,D8,D9 | LED_0605-1613 | C965839 | 4
SN74LVC1G97QDCKRQ1 | IC10,IC11,IC12,IC13,IC21,IC23,IC25,IC26,IC5,IC6,IC7,IC8 | SOT-363_SC-70-6 | C179911 | 12
SP0503BAHTG | D4 | SOT143 | C3040626 | 1
TCA9548ARGER | IC4 | Texas_RGE0024C_VQFN-24-1EP_4x4mm_P0.5mm_EP2.1x2.1mm | C555456 | 1
TPD4EUSB30DQAR | D3 | USON10_2.5x1 | C5199222 | 1
TPS51225CRUKR | IC1 | QFN20-3x3 | C131684 | 1
USB-TYPE-C-018 | J3 | USB_C_Receptacle_HCTL_HC-TYPE-C-16P-01A | C2927038 | 1

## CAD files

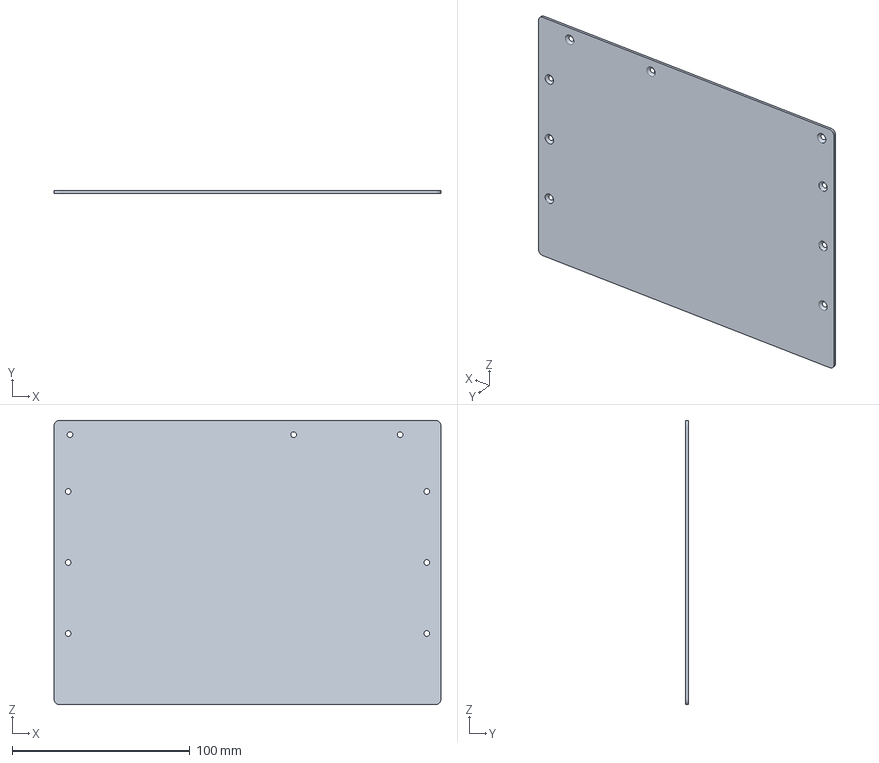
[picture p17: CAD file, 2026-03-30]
images/Top Lid.3mf
218.0 x 1.50 x 160.0 mm

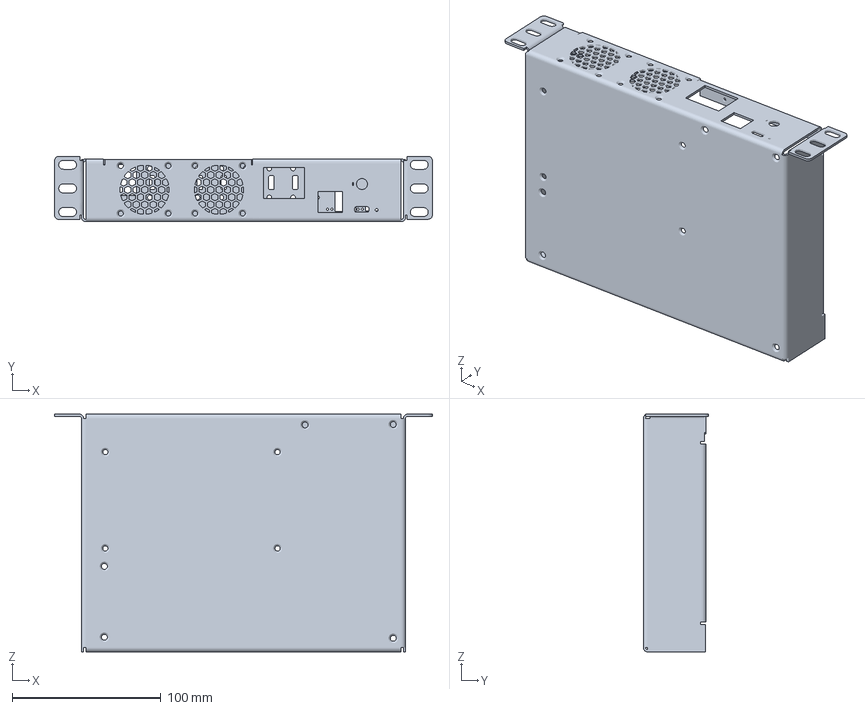
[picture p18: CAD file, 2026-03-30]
images/Enclosure.3mf
254.2 x 44.0 x 160.0 mm

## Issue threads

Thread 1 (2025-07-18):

Possible to add higher voltages to support other equipment?

techrivertree, 2025-07-18:
I ask because the 0.5U network POE network switch I have for my mini rack has a gigantic power brick. The listed output is 48v at 2 amps (96 watts).

I asked Anker and their USB C chargers only go up to 20v.

techrivertree, 2025-07-19:
Yesterday I found a large USB C charger (500w) from UGreen and in the specs it listed "48.0V=5.0A 240W Max". Cold link: https://www.ugreen.com/products/ugreen-500w-usbc-desktop-charger.

If they can do it I guess it is possible.

CZEMacLeod, 2025-07-19:
The Framework 16 laptop uses some shenanigans to support 180W and 240W USB PD, one of which is 36V and I think the 240W is 48V x 5A.
https://frame.work/gb/en/blog/framework-laptop-16-deep-dive---180w-power-adapter
There are some PD chips mentioned here which might shed some light on the matter.
I agree though - there won't be a magic cable with a 48V requester like https://www.adafruit.com/product/5450
What I'd really like to see is a UPS in 10" rack format with USB-C PD and a POE injector that could be used to power a POE network switch (like the mikrotik routers https://mikrotik.com/product/rb5009upr_s_in).
There are some devices available on aliexpress which meet some of the requirements (although none that are rack mountable).
I have been considering if I could build something myself, but like you, there are financial limits on what I could prototype.

CZEMacLeod, 2025-07-19:
While this is going off topic - a device I am looking at is this: https://www.aliexpress.com/item/1005006750121581.html
It is a LiFePo 5000mAh device with 48V POE output, but also available in 12V, 9V, and 5V. There are other similar devices with a USB-A and/or USB-C port but none of them in a 1U 10" form factor, although I guess I could 3D Print something.
There is also the Eaton 3S Mini UPS - https://www.amazon.co.uk/gp/aw/d/B092TG9M7C - again not the right form factor but not far off in terms of physical volume/size.
I agree that this is a different problem than the one you are trying to solve here - but for my minirack, supplying my router, vdsl modem, and some rpis with UPS (and hopefully some kind of serial monitor compatible with NUT) would be my ultimate device.

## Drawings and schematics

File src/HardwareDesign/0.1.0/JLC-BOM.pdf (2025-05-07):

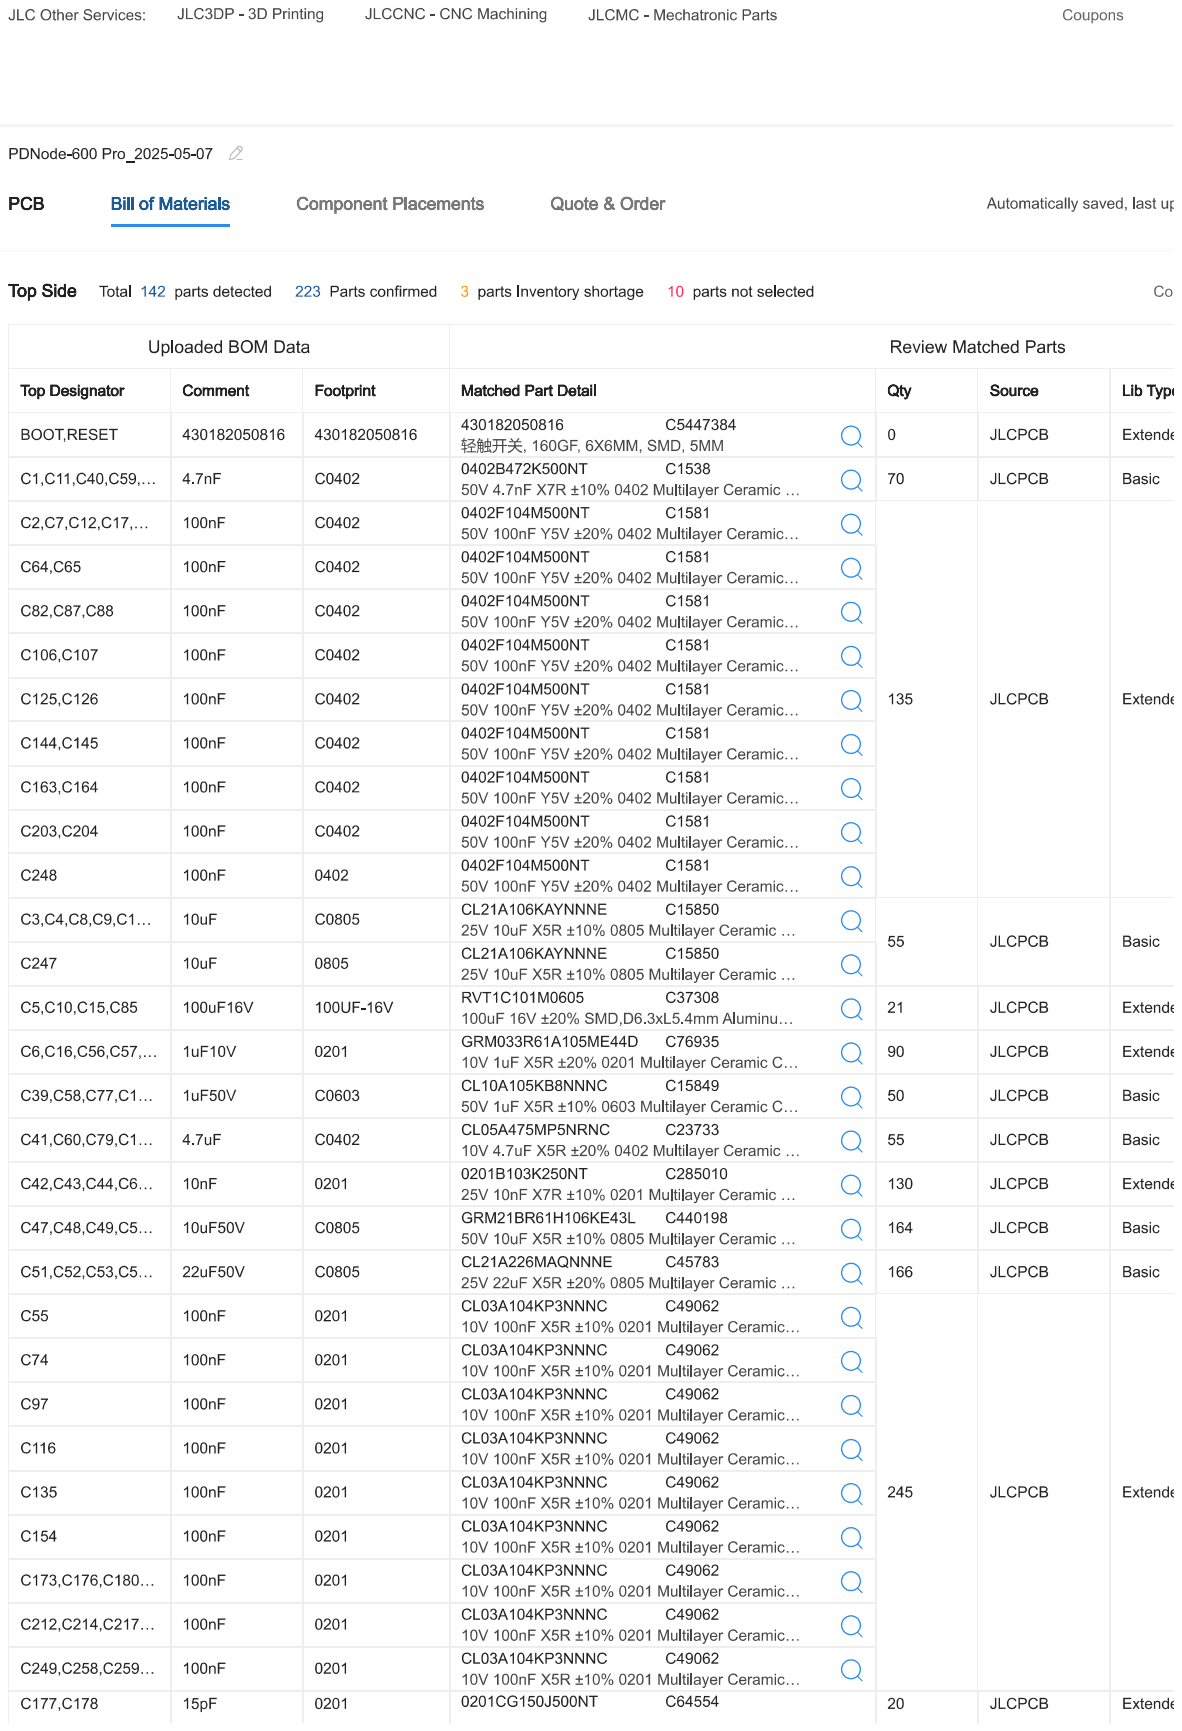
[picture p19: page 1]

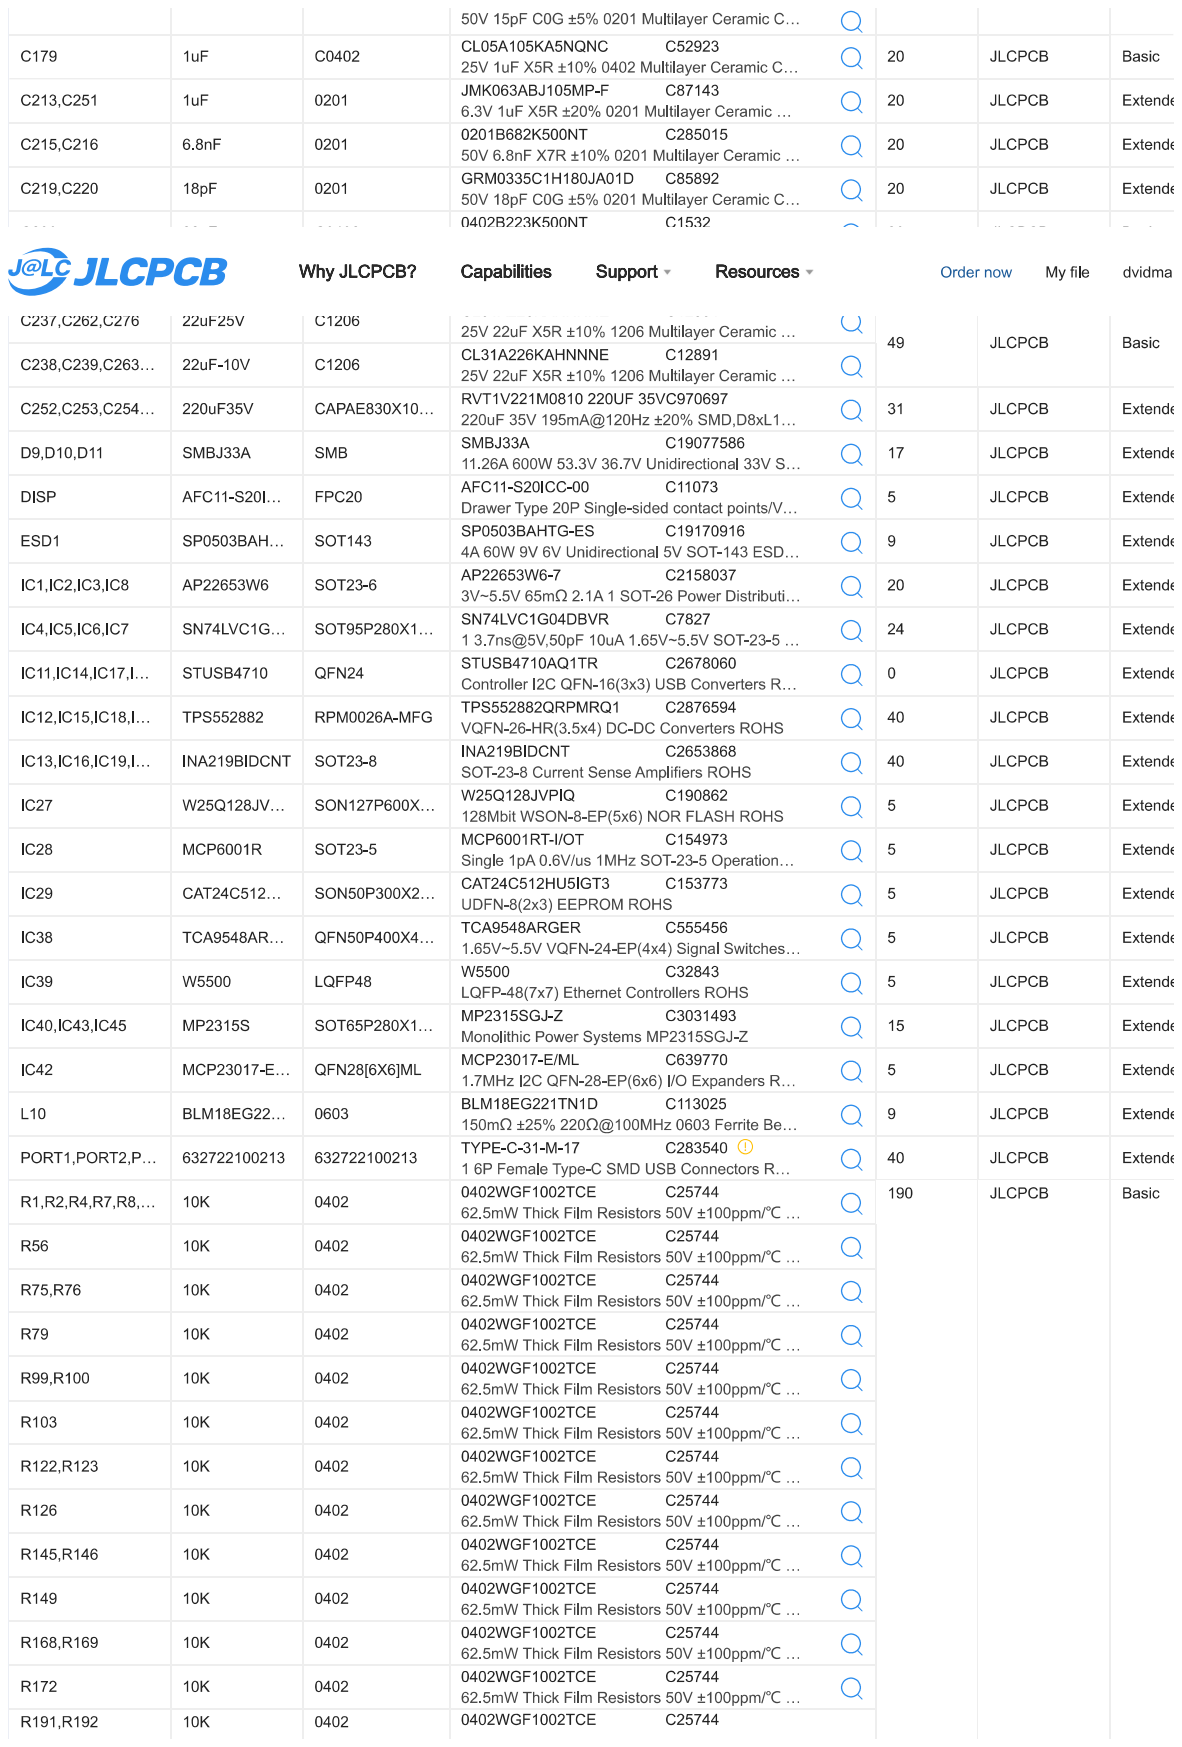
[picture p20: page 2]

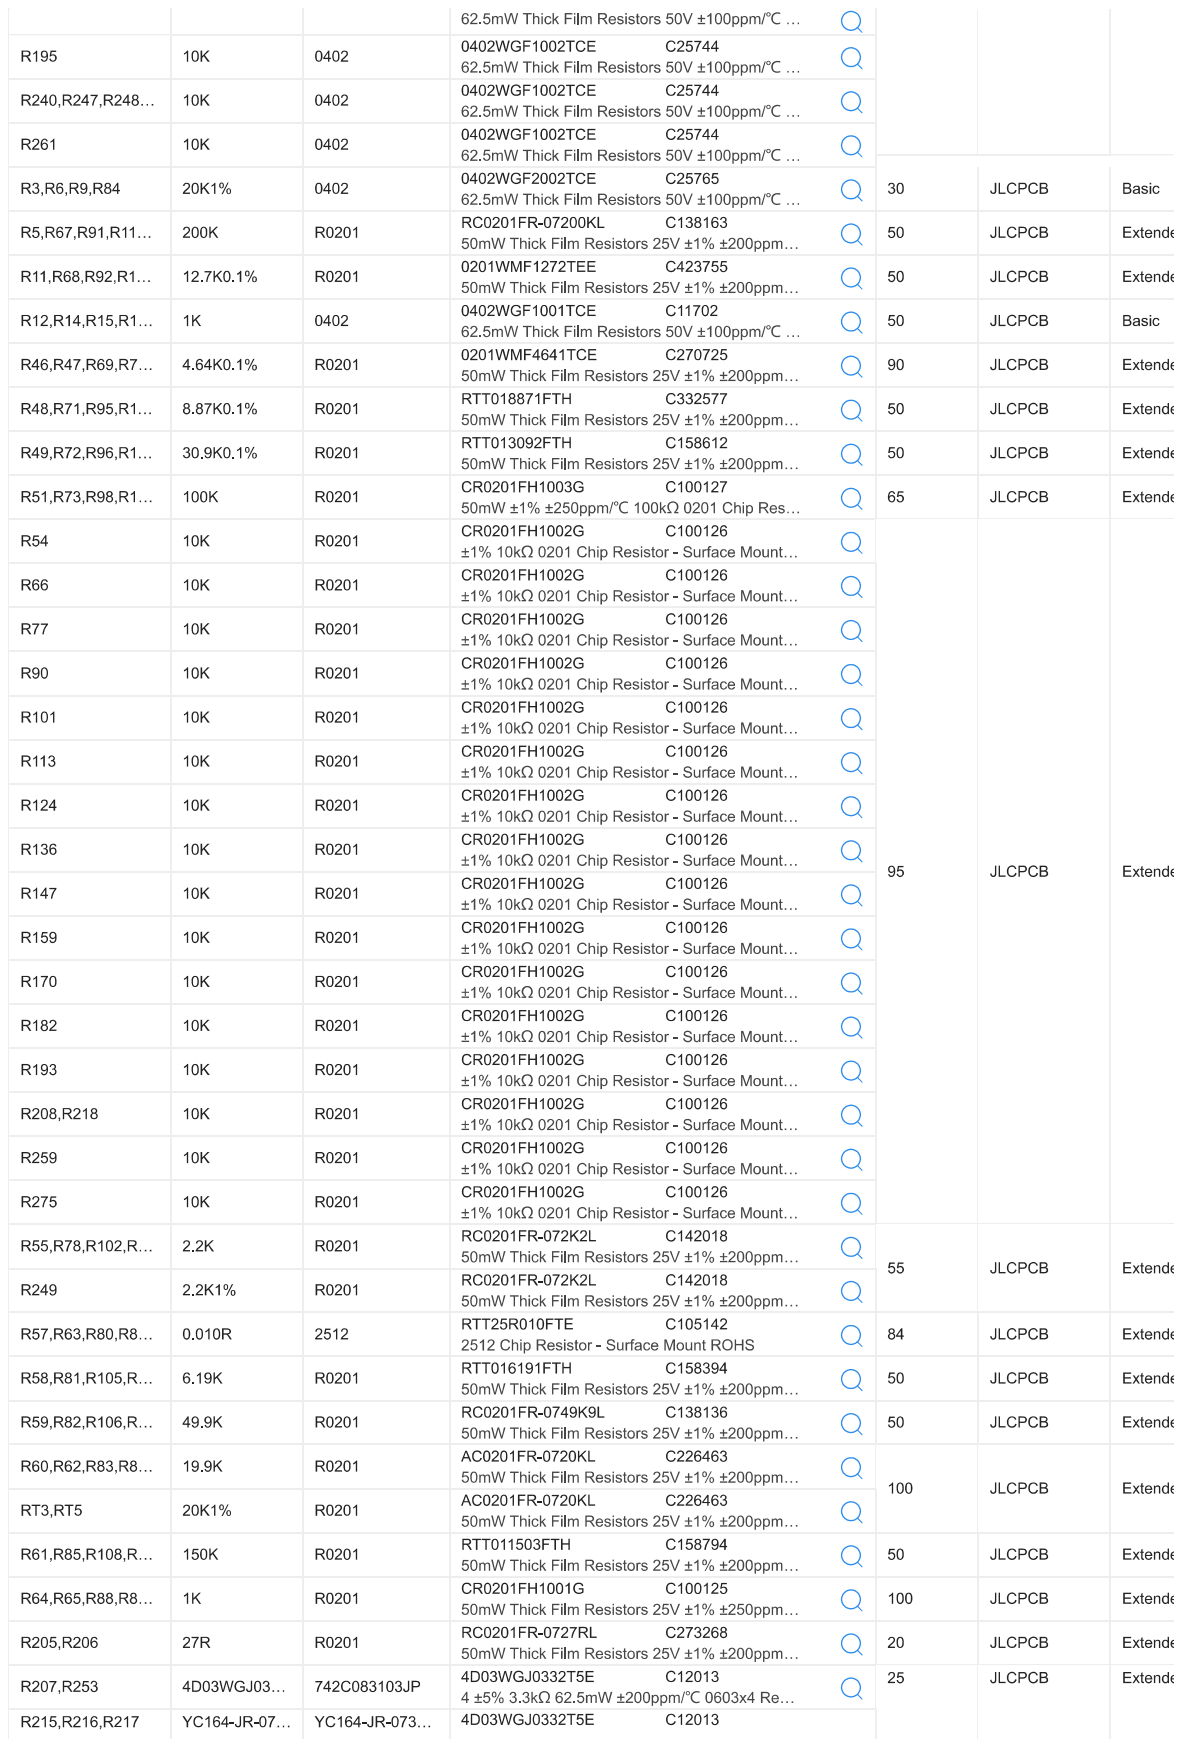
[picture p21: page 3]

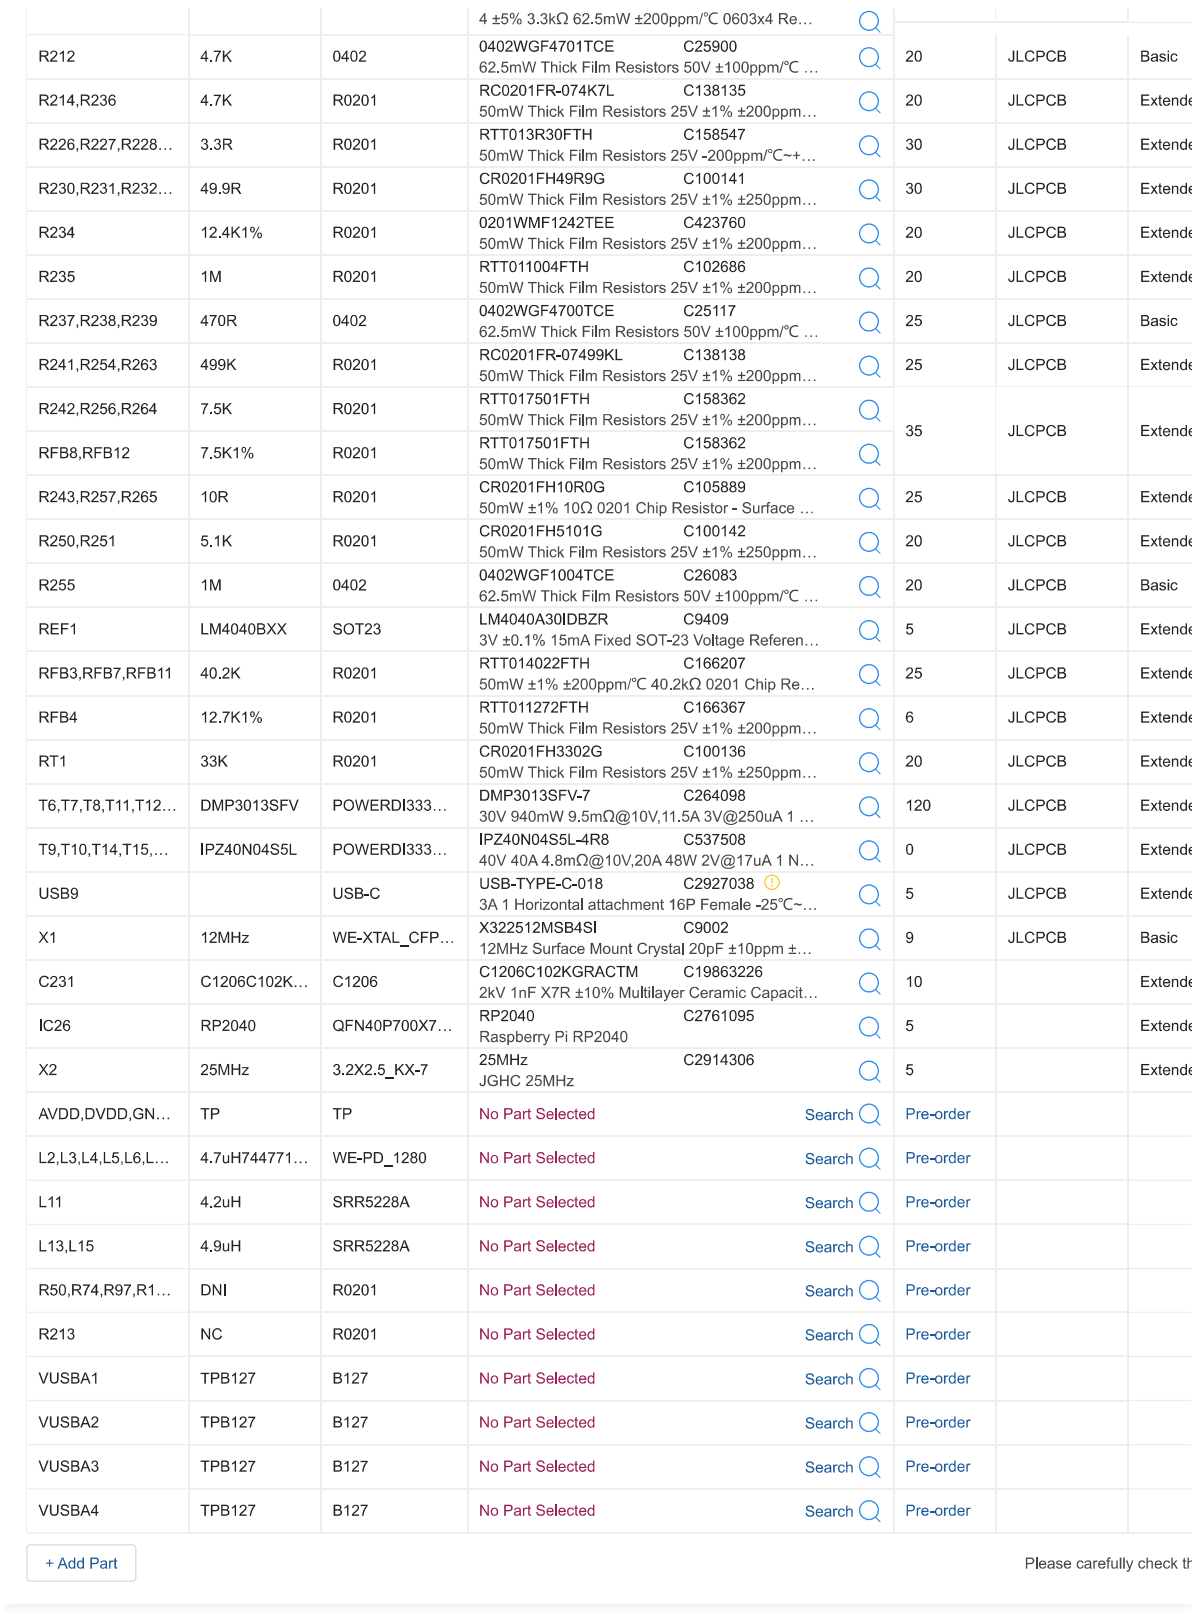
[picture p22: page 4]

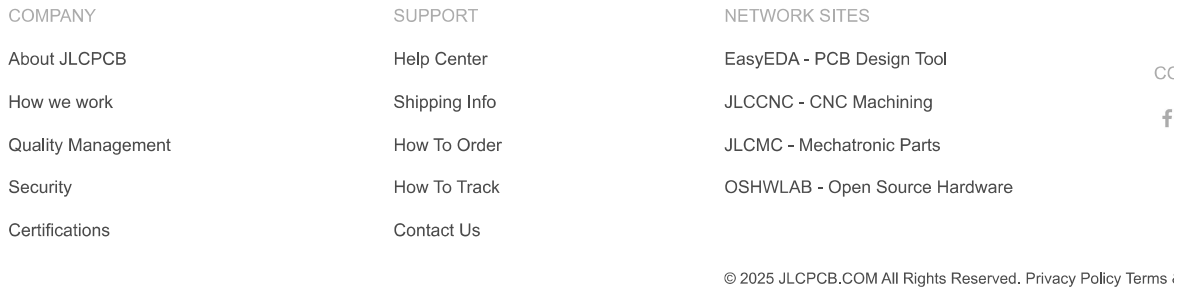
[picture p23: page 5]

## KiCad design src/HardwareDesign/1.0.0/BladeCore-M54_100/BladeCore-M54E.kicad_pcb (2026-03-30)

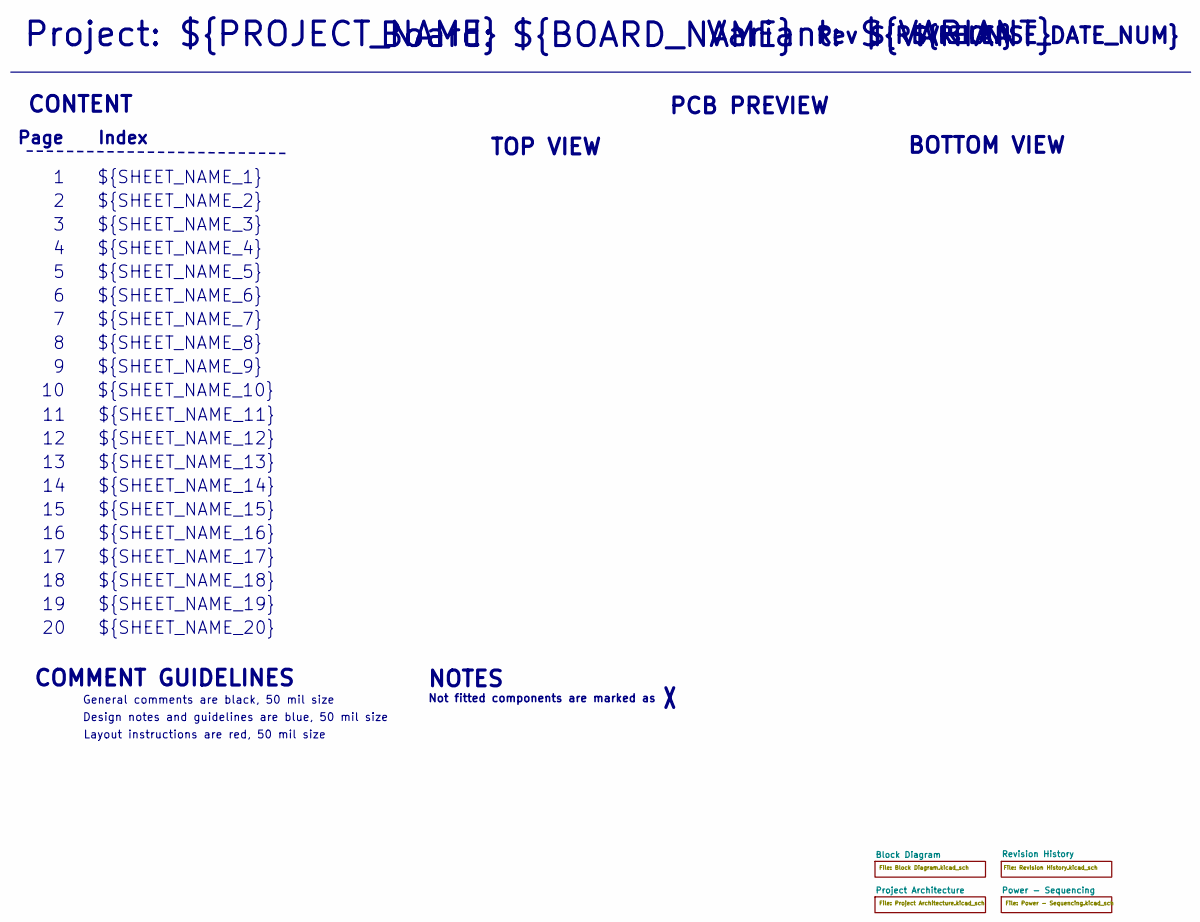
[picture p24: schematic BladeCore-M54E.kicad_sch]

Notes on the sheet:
${SHEET_NAME_12}
${SHEET_NAME_8}
${SHEET_NAME_2}
${SHEET_NAME_5}
${SHEET_NAME_20}
Page
PCB PREVIEW
${RELEASE_DATE_NUM}
CONTENT
${SHEET_NAME_11}
${SHEET_NAME_6}
Rev ${REVISION}
${SHEET_NAME_15}
BOTTOM VIEW
${SHEET_NAME_14}
${SHEET_NAME_17}
${SHEET_NAME_18}
${SHEET_NAME_7}
Not fitted components are marked as
Project: ${PROJECT_NAME}
NOTES
Design notes and guidelines are blue, 50 mil size
${SHEET_NAME_1}
${SHEET_NAME_9}
Board: ${BOARD_NAME}
General comments are black, 50 mil size
${SHEET_NAME_16}
${SHEET_NAME_3}
Variant: ${VARIANT}
${SHEET_NAME_19}
TOP VIEW
${SHEET_NAME_10}
Index
${SHEET_NAME_13}
${SHEET_NAME_4}
COMMENT GUIDELINES
Layout instructions are red, 50 mil size

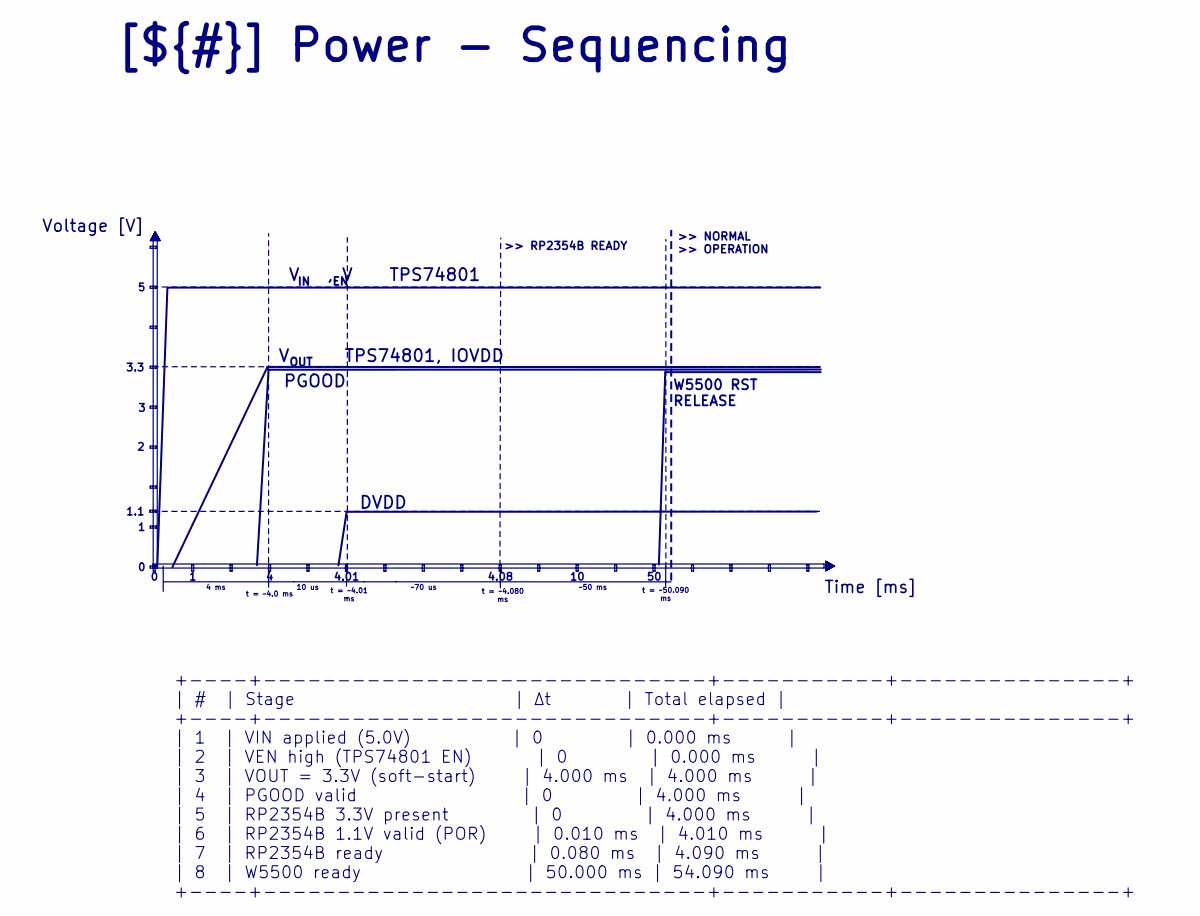
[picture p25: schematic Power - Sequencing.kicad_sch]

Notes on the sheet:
>> RP2354B READY
Voltage [V]
+----+------------------------------+-----------+---------------+ | # | Stage | Δt | Total elapsed | +----+------------------------------+-----------+---------------+ | 1 | VIN applied (5.0V) | 0 | 0.000 ms | | 2 | VEN high (TPS74801 EN) | 0 | 0.000 ms | | 3 | VOUT = 3.3V (soft-start) | 4.000 ms | 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
>> NORMAL >> OPERATION
Time [ms]
10 us
4.08
~70 us
4.01
DVDD
t = ~4.01 ms
3.3
W5500 RST RELEASE
~50 ms
t = ~50.090 ms
t = ~4.080 ms
V , V TPS74801
t = ~4.0 ms
PGOOD
1.1
4 ms
OUT
V TPS74801, IOVDD
[${#}] ${TITLE}

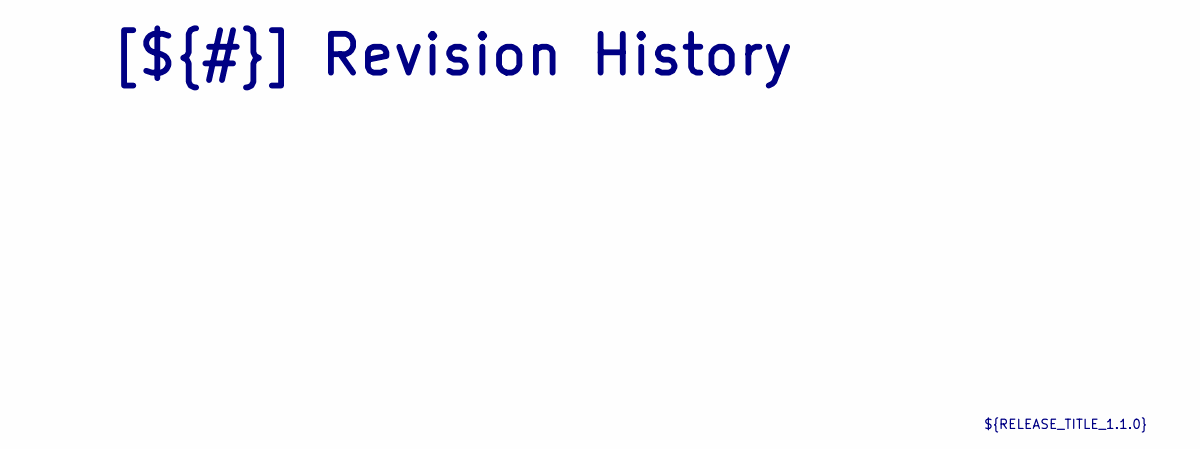
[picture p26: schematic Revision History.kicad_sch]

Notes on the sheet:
[${#}] ${TITLE}
${RELEASE_TITLE_1.1.0}

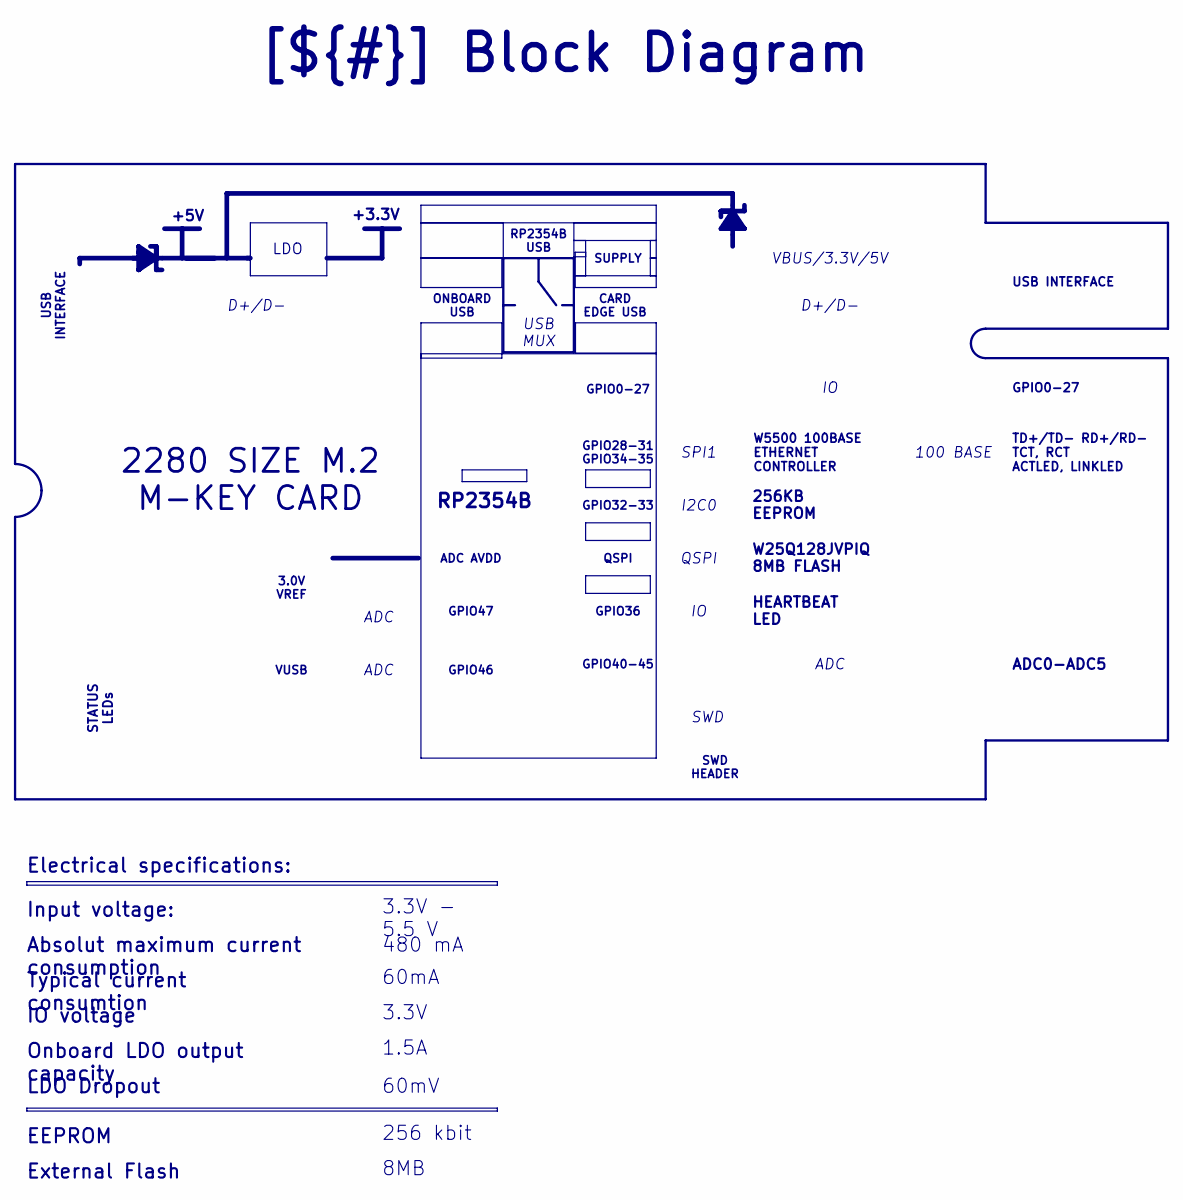
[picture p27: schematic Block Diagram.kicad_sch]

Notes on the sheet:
+3.3V
RP2354B
2280 SIZE M.2 M-KEY CARD
+5V
USB INTERFACE
LDO Dropout
IO voltage
256KB EEPROM
VBUS/3.3V/5V
1.5A
CARD EDGE USB
W25Q128JVPIQ 8MB FLASH
3.3V - 5.5 V
ADC0-ADC5
SWD HEADER
LDO
3.3V
GPIO0-27
TD+/TD- RD+/RD- TCT, RCT ACTLED, LINKLED
SPI1
W5500 100BASE ETHERNET CONTROLLER
GPIO40-45
ADC
QSPI
3.0V VREF
RP2354B USB
GPIO32-33
[${#}] ${TITLE}
480 mA
Input voltage:
STATUS LEDs
EEPROM
GPIO46
256 kbit
Electrical specifications:
SWD
GPIO47
GPIO36
GPIO28-31 GPIO34-35
ONBOARD USB

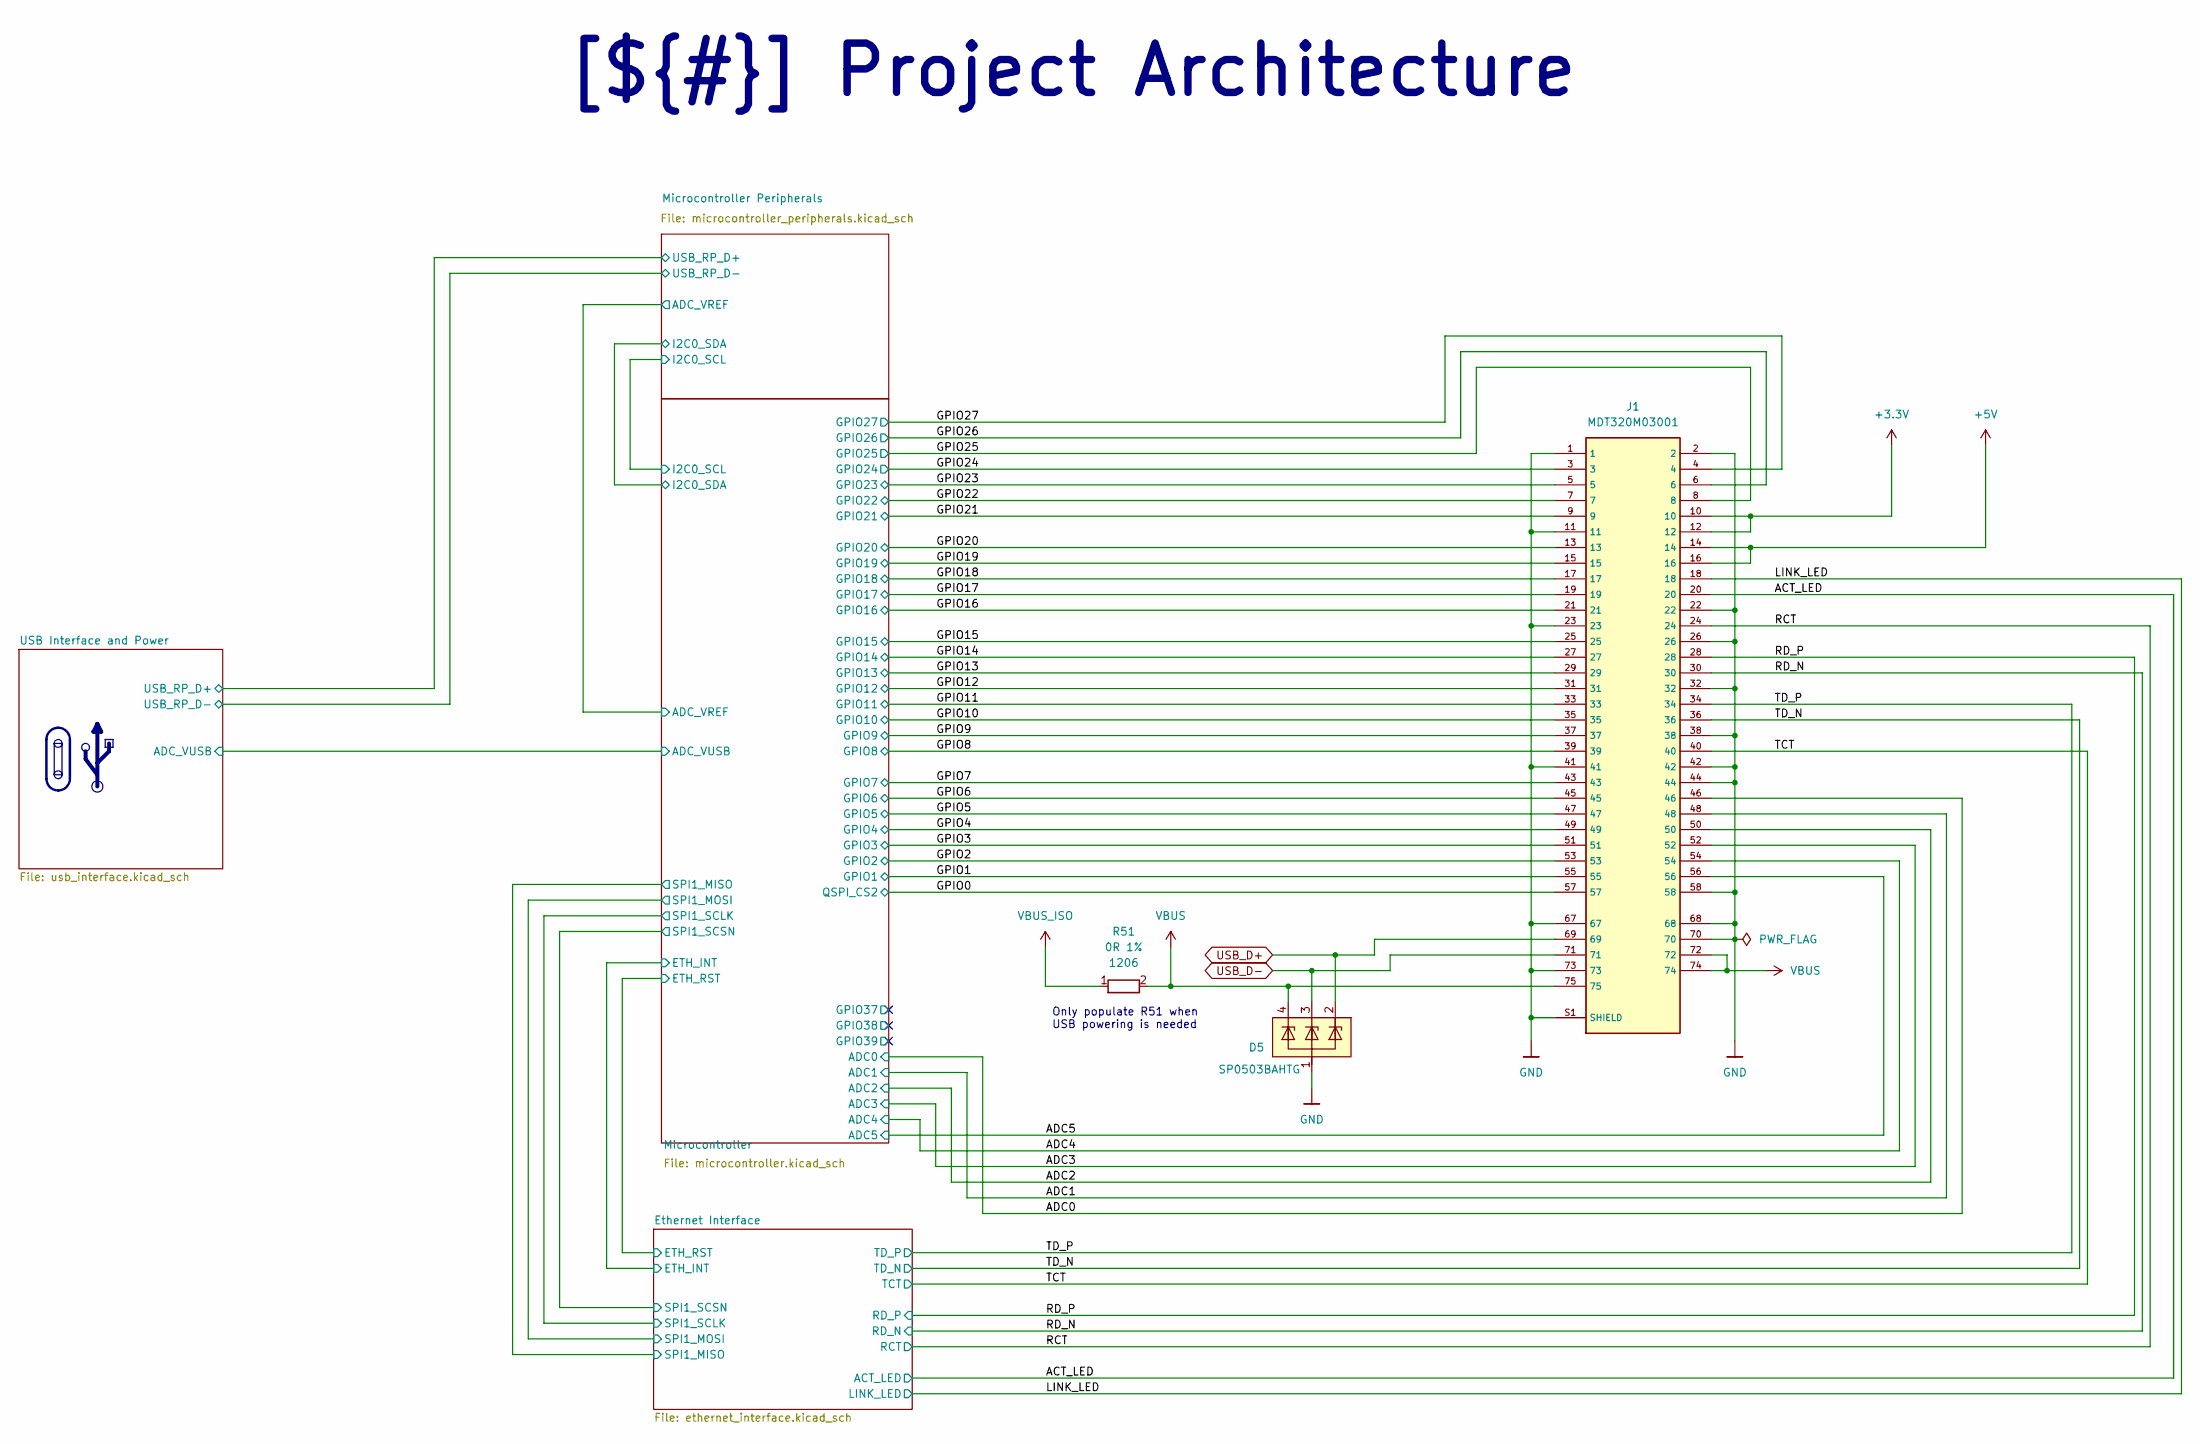
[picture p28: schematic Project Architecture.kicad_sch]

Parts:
D5: SP0503BAHTG; SOT143; MPN SP0503BAHTG; LCSC_PART C3040626
J1: MDT320M03001; M.2-M-KEY_Card_2280
R51: 0R 1%; R_1206_3216Metric; LCSC_PART C205296

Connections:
+3.3V: J1.10, J1.12; also elsewhere on the board
+5V: J1.14, J1.16; also elsewhere on the board
/Project Architecture/ACT_LED: J1.20; also elsewhere on the board
/Project Architecture/ADC0: J1.46; also elsewhere on the board
/Project Architecture/ADC1: J1.48; also elsewhere on the board
/Project Architecture/ADC2: J1.50; also elsewhere on the board
/Project Architecture/ADC3: J1.52; also elsewhere on the board
/Project Architecture/ADC4: J1.54; also elsewhere on the board
/Project Architecture/ADC5: J1.56; also elsewhere on the board
/Project Architecture/GPIO0: J1.57; also elsewhere on the board
/Project Architecture/GPIO1: J1.55; also elsewhere on the board
/Project Architecture/GPIO2: J1.53; also elsewhere on the board
/Project Architecture/GPIO3: J1.51; also elsewhere on the board
/Project Architecture/GPIO4: J1.49; also elsewhere on the board
/Project Architecture/GPIO5: J1.47; also elsewhere on the board
/Project Architecture/GPIO6: J1.45; also elsewhere on the board
/Project Architecture/GPIO7: J1.43; also elsewhere on the board
/Project Architecture/GPIO8: J1.39; also elsewhere on the board
/Project Architecture/GPIO9: J1.37; also elsewhere on the board
/Project Architecture/GPIO10: J1.35; also elsewhere on the board
/Project Architecture/GPIO11: J1.33; also elsewhere on the board
/Project Architecture/GPIO12: J1.31; also elsewhere on the board
/Project Architecture/GPIO13: J1.29; also elsewhere on the board
/Project Architecture/GPIO14: J1.27; also elsewhere on the board
/Project Architecture/GPIO15: J1.25; also elsewhere on the board
/Project Architecture/GPIO16: J1.21; also elsewhere on the board
/Project Architecture/GPIO17: J1.19; also elsewhere on the board
/Project Architecture/GPIO18: J1.17; also elsewhere on the board
/Project Architecture/GPIO19: J1.15; also elsewhere on the board
/Project Architecture/GPIO20: J1.13; also elsewhere on the board
/Project Architecture/GPIO21: J1.9; also elsewhere on the board
/Project Architecture/GPIO22: J1.7; also elsewhere on the board
/Project Architecture/GPIO23: J1.5; also elsewhere on the board
/Project Architecture/GPIO24: J1.3; also elsewhere on the board
/Project Architecture/GPIO25: J1.8; also elsewhere on the board
/Project Architecture/GPIO26: J1.6; also elsewhere on the board
/Project Architecture/GPIO27: J1.4; also elsewhere on the board
/Project Architecture/LINK_LED: J1.18; also elsewhere on the board
/Project Architecture/RCT: J1.24; also elsewhere on the board
/Project Architecture/RD_N: J1.30; also elsewhere on the board
/Project Architecture/RD_P: J1.28; also elsewhere on the board
/Project Architecture/TCT: J1.40; also elsewhere on the board
/Project Architecture/TD_N: J1.36; also elsewhere on the board
/Project Architecture/TD_P: J1.34; also elsewhere on the board
GND: D5.1, J1.1, J1.2, J1.11, J1.22, J1.23, J1.26, J1.32, J1.38, J1.41, J1.42, J1.44, J1.58, J1.67, J1.68, J1.70, J1.73, J1.S1 (SHIELD), J1.S2 (SHIELD); also elsewhere on the board
USB_D+: D5.2, J1.69; also elsewhere on the board
USB_D-: D5.3, J1.71; also elsewhere on the board
VBUS: D5.4, J1.72, J1.74, J1.75, R51.2; also elsewhere on the board
VBUS_ISO: R51.1; also elsewhere on the board

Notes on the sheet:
Only populate R51 when USB powering is needed
[${#}] ${TITLE}

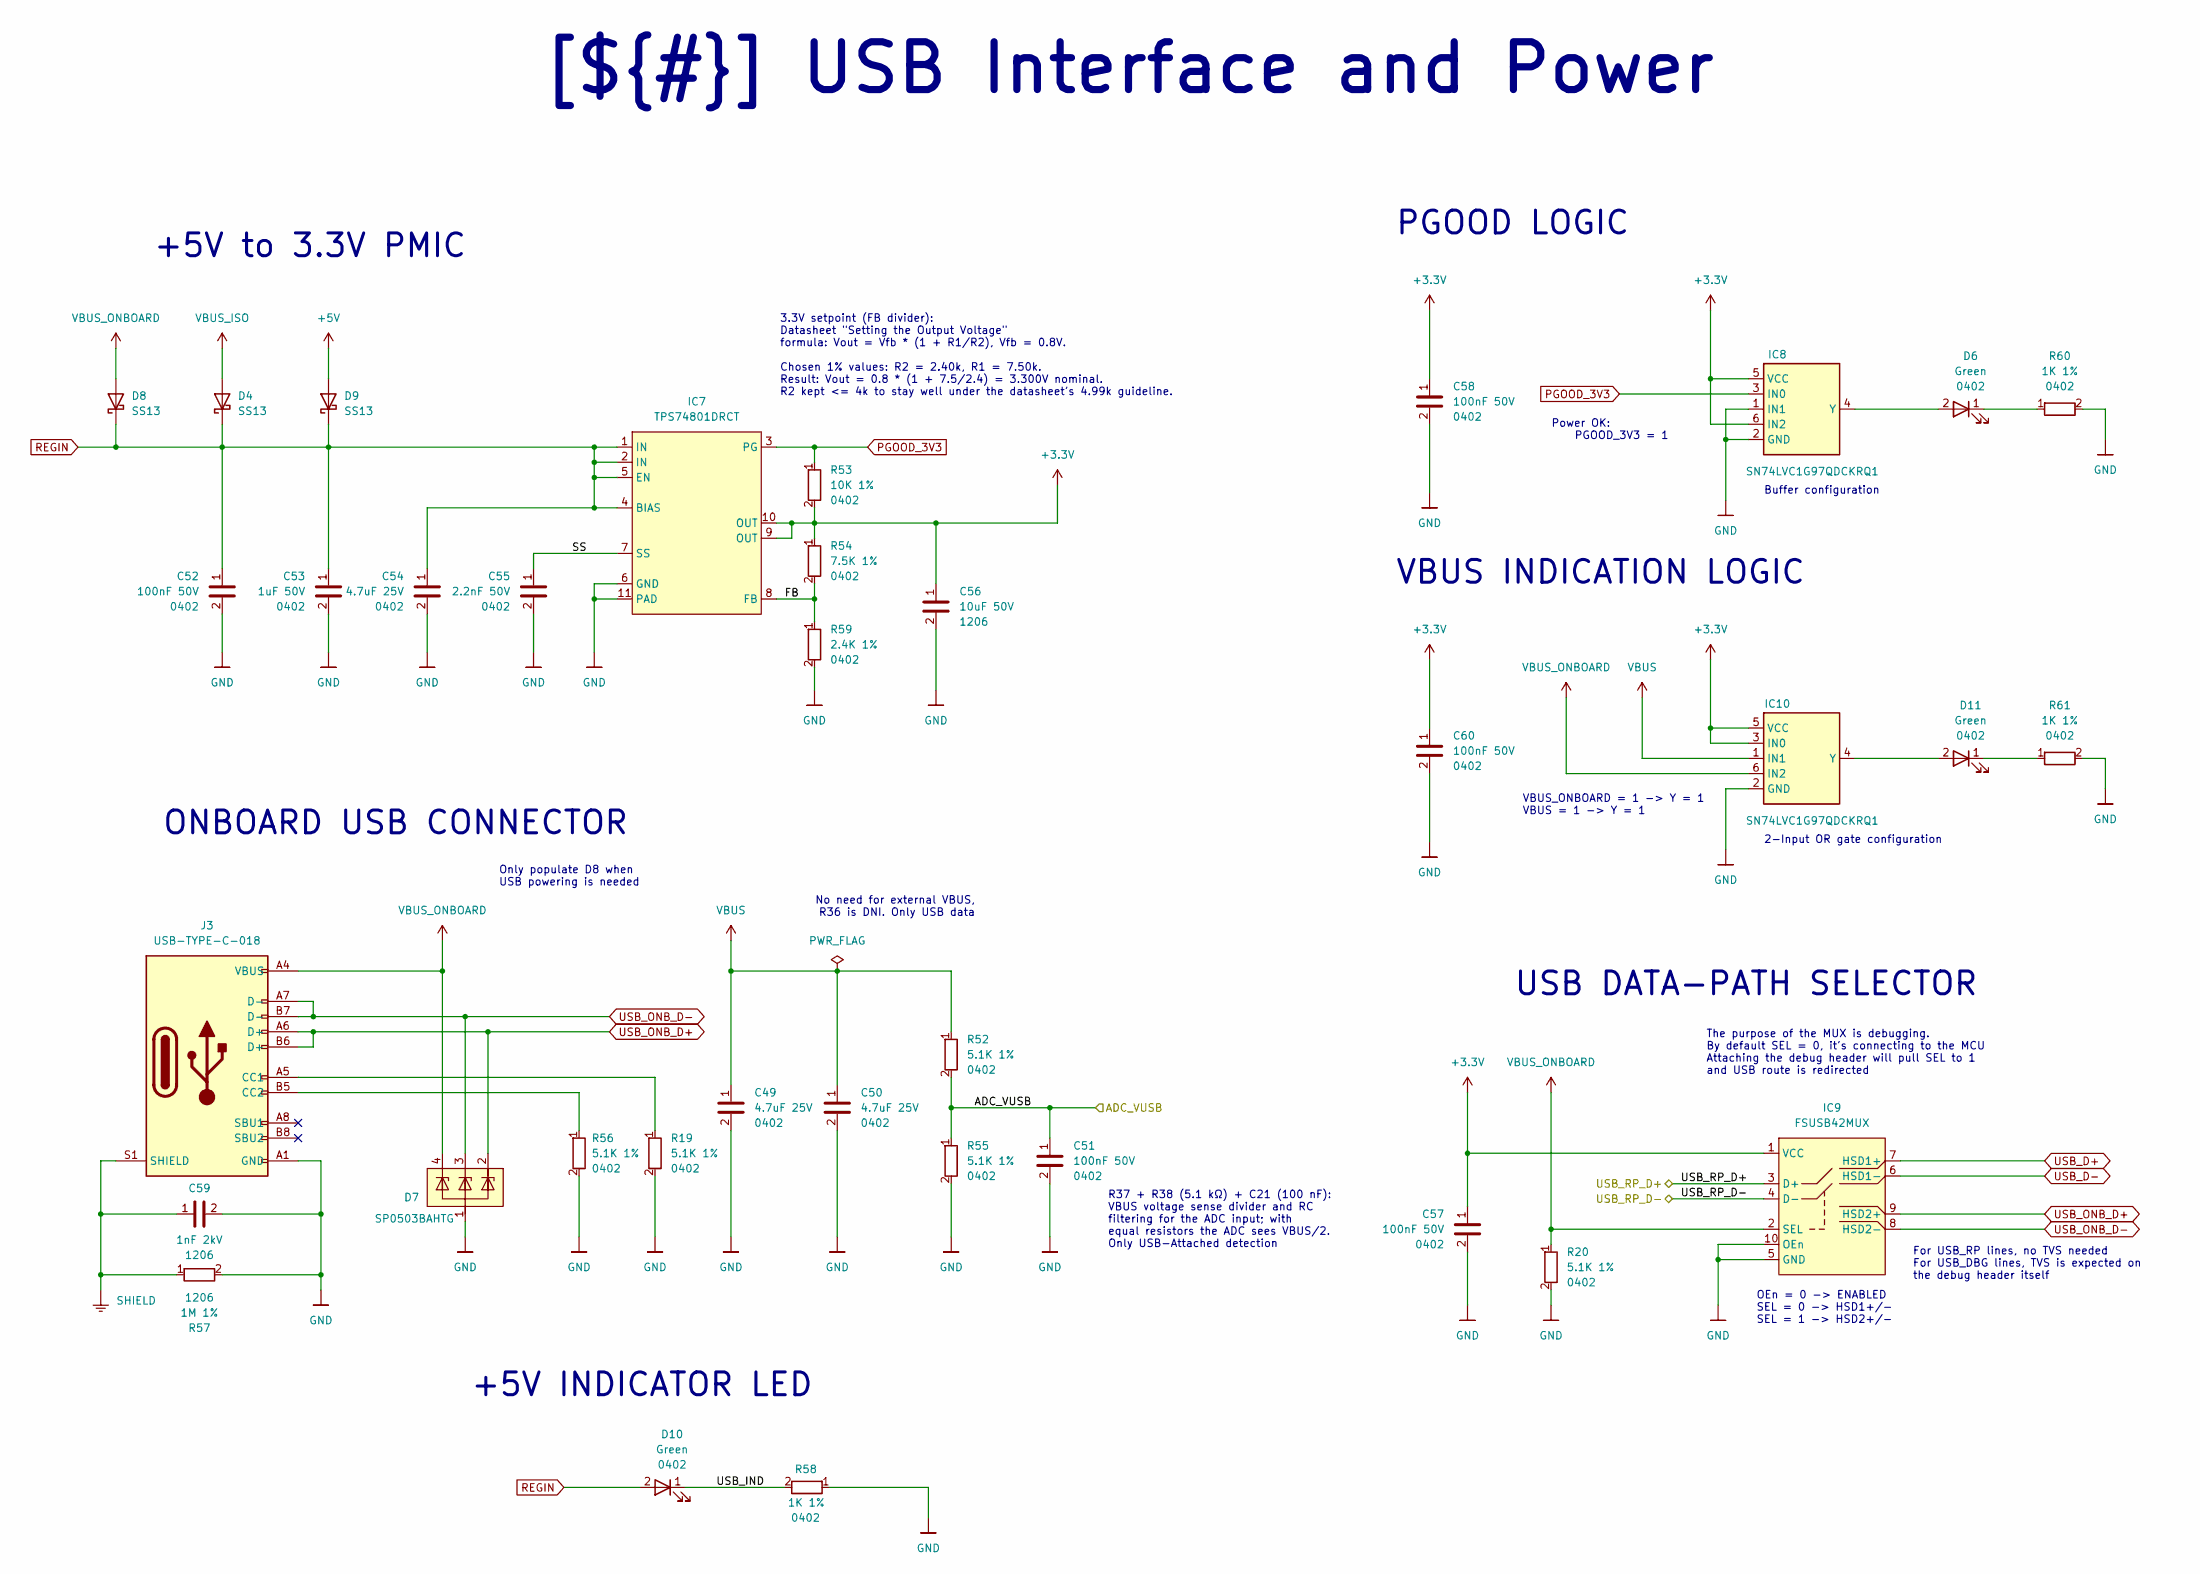
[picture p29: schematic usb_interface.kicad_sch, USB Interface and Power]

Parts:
C49, C50, C54: 4.7uF 25V; C_0402_1005Metric; LCSC_PART C22367824
C51, C52, C57, C58, C60: 100nF 50V; C_0402_1005Metric; LCSC_PART C307331
C53: 1uF 50V; C_0402_1005Metric; LCSC_PART C1518208
C55: 2.2nF 50V; C_0402_1005Metric; MPN CC0402KRX7R9BB222; LCSC_PART C106861
C56: 10uF 50V; C_1206_3216Metric; MPN CL31A106KBHNNNE; LCSC_PART C13585
C59: 1nF 2kV; C_1206_3216Metric; LCSC_PART C173242
D4, D8, D9: SS13; D_SMA
D6, D10, D11: Green; LED_0402_1005Metric; MPN XL-1005UGC; LCSC_PART C965793
D7: SP0503BAHTG; SOT143; MPN SP0503BAHTG; LCSC_PART C3040626
IC7: TPS74801DRCT; VSON-10-1EP_3x3mm_P0.5mm_EP1.65x2.4mm_ThermalVias; MPN TPS74801DRCT; LCSC_PART C882845
IC8, IC10: SN74LVC1G97QDCKRQ1; SOT-363_SC-70-6; MPN SN74LVC1G97QDCKRQ1; LCSC_PART C179911
IC9: FSUSB42MUX; MSOP-10_3x3mm_P0.5mm; MPN FSUSB42MUX; LCSC_PART C11355
J3: USB-TYPE-C-018; USB_C_Receptacle_HCTL_HC-TYPE-C-16P-01A; MPN USB-TYPE-C-018; LCSC_PART C2927038
R19, R20, R52, R55, R56: 5.1K 1%; R_0402_1005Metric; LCSC_PART C25905
R53: 10K 1%; R_0402_1005Metric; LCSC_PART C25744
R54: 7.5K 1%; R_0402_1005Metric; LCSC_PART C25918
R57: 1M 1%; R_1206_3216Metric; LCSC_PART C17927
R58, R60, R61: 1K 1%; R_0402_1005Metric; LCSC_PART C11702
R59: 2.4K 1%; R_0402_1005Metric; LCSC_PART C25882

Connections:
+3.3V: C56.1, C57.1, C58.1, C60.1, IC7.9 (OUT), IC7.10 (OUT), IC8.5 (VCC), IC8.6 (IN2), IC9.1 (VCC), IC10.3 (IN0), IC10.5 (VCC), R53.2, R54.1; also elsewhere on the board
+5V: D9.2 (A); also elsewhere on the board
/Project Architecture/Microcontroller/ADC_VUSB: C51.1, R52.2, R55.1; also elsewhere on the board
/Project Architecture/USB Interface and Power/FB: IC7.8 (FB), R54.2, R59.1
/Project Architecture/USB Interface and Power/SS: C55.1, IC7.7 (SS)
/Project Architecture/USB Interface and Power/USB_IND: D10.1, R58.2
/Project Architecture/USB Interface and Power/USB_RP_D+: IC9.3 (D+); also elsewhere on the board
/Project Architecture/USB Interface and Power/USB_RP_D-: IC9.4 (D-); also elsewhere on the board
GND: C49.2, C50.2, C51.2, C52.2, C53.2, C54.2, C55.2, C56.2, C57.2, C58.2, C59.2, C60.2, D7.1, IC7.6 (GND), IC7.11 (PAD), IC8.1 (IN1), IC8.2 (GND), IC9.5 (GND), IC9.10 (OEn), IC10.2 (GND), J3.A1 (GND), J3.A12 (GND), J3.B1 (GND), J3.B12 (GND), R19.2, R20.2, R55.2, R56.2, R57.2, R58.1, R59.2, R60.2, R61.2; also elsewhere on the board
unnamed: D6.1, R60.1
unnamed: D11.1, R61.1
unnamed: D6.2, IC8.4 (Y)
unnamed: D11.2, IC10.4 (Y)
unnamed: J3.A5 (CC1), R19.1
unnamed: J3.B5 (CC2), R56.1
PGOOD_3V3: IC7.3 (PG), IC8.3 (IN0), R53.1
REGIN: C52.1, C53.1, C54.1, D4.1 (K), D8.1 (K), D9.1 (K), D10.2, IC7.1 (IN), IC7.2 (IN), IC7.4 (BIAS), IC7.5 (EN)
SHIELD: C59.1, J3.S1 (SHIELD), R57.1
USB_D+: IC9.7 (HSD1+); also elsewhere on the board
USB_D-: IC9.6 (HSD1-); also elsewhere on the board
USB_ONB_D+: D7.2, IC9.9 (HSD2+), J3.A6 (D+), J3.B6 (D+)
USB_ONB_D-: D7.3, IC9.8 (HSD2-), J3.A7 (D-), J3.B7 (D-)
VBUS: C49.1, C50.1, IC10.1 (IN1), R52.1; also elsewhere on the board
VBUS_ISO: D4.2 (A); also elsewhere on the board
VBUS_ONBOARD: D7.4, D8.2 (A), IC9.2 (SEL), IC10.6 (IN2), J3.A4 (VBUS), J3.A9 (VBUS), J3.B4 (VBUS), J3.B9 (VBUS), R20.1

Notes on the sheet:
VBUS INDICATION LOGIC
OEn = 0 -> ENABLED SEL = 0 -> HSD1+/- SEL = 1 -> HSD2+/-
USB DATA-PATH SELECTOR
No need for external VBUS, R36 is DNI. Only USB data
2-Input OR gate configuration
+5V to 3.3V PMIC
+5V INDICATOR LED
3.3V setpoint (FB divider): Datasheet "Setting the Output Voltage" formula: Vout = Vfb * (1 + R1/R2), Vfb = 0.8V. Chosen 1% values: R2 = 2.40k, R1 = 7.50k. Result: Vout = 0.8 * (1 + 7.5/2.4) = 3.300V nominal. R2 kept <= 4k to stay well under the datasheet's 4.99k guideline.
ONBOARD USB CONNECTOR
For USB_RP lines, no TVS needed For USB_DBG lines, TVS is expected on the debug header itself
R37 + R38 (5.1 kΩ) + C21 (100 nF): VBUS voltage sense divider and RC filtering for the ADC input; with equal resistors the ADC sees VBUS/2. Only USB-Attached detection
VBUS_ONBOARD = 1 -> Y = 1 VBUS = 1 -> Y = 1
Power OK: PGOOD_3V3 = 1
Buffer configuration
PGOOD LOGIC
Only populate D8 when USB powering is needed
The purpose of the MUX is debugging. By default SEL = 0, it's connecting to the MCU Attaching the debug header will pull SEL to 1 and USB route is redirected
[${#}] ${TITLE}

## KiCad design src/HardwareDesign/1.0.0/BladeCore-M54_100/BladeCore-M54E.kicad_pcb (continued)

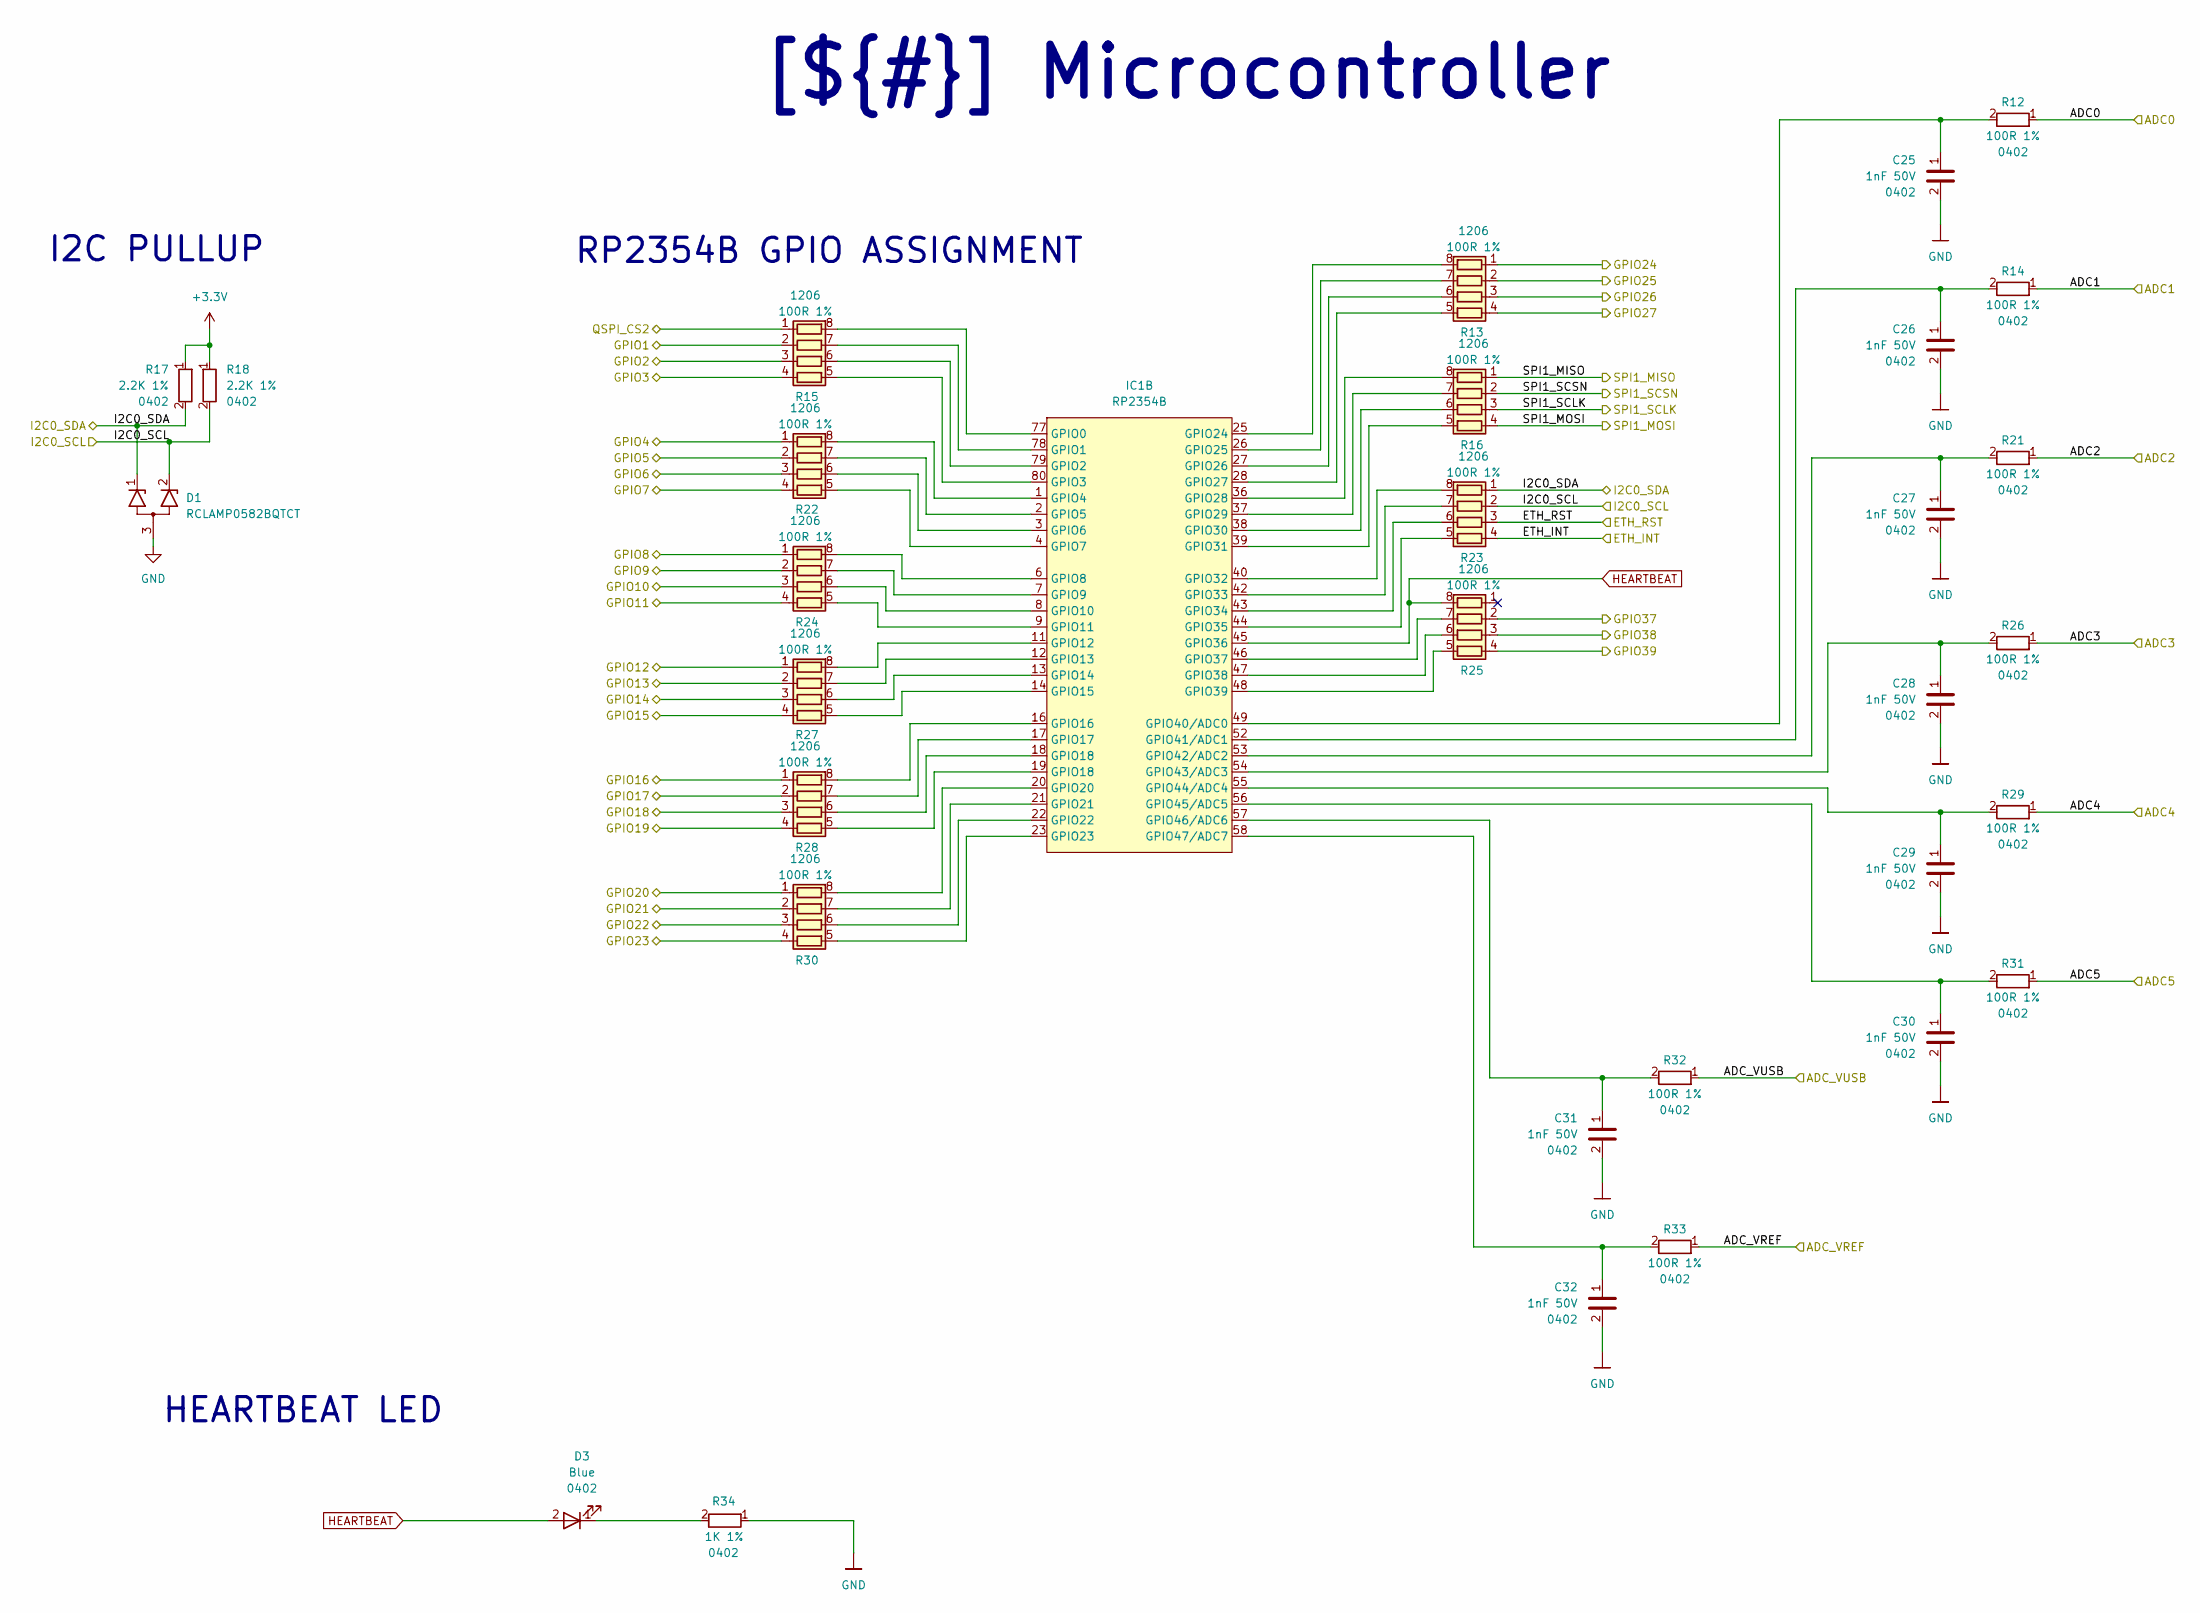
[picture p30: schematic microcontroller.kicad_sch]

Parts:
C25, C26, C27, C28, C29, C30, C31, C32: 1nF 50V; C_0402_1005Metric; LCSC_PART C14442
D1: RCLAMP0582BQTCT; SOT-416; MPN RCLAMP0582BQTCT; LCSC_PART C841193
D3: Blue; LED_0402_1005Metric; MPN XL-1005UBC; LCSC_PART C22355736
IC1: RP2354B; QFN80_10x10; MPN RP2354B; LCSC_PART C39843328
R12, R14, R21, R26, R29, R31, R32, R33: 100R 1%; R_0402_1005Metric; LCSC_PART C25076
R13, R15, R16, R22, R23, R24, R25, R27, R28, R30: 100R 1%; R_Array_Convex_4x0603; MPN YC164-FR-07100RL; LCSC_PART C136838
R17, R18: 2.2K 1%; R_0402_1005Metric; LCSC_PART C25879
R34: 1K 1%; R_0402_1005Metric; LCSC_PART C11702

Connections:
+3.3V: R17.1, R18.1; also elsewhere on the board
/Project Architecture/ADC0: R12.1; also elsewhere on the board
/Project Architecture/ADC1: R14.1; also elsewhere on the board
/Project Architecture/ADC2: R21.1; also elsewhere on the board
/Project Architecture/ADC3: R26.1; also elsewhere on the board
/Project Architecture/ADC4: R29.1; also elsewhere on the board
/Project Architecture/ADC5: R31.1; also elsewhere on the board
/Project Architecture/Ethernet Interface/ETH_INT: R23.4 (R14); also elsewhere on the board
/Project Architecture/Ethernet Interface/ETH_RST: R23.3 (R13); also elsewhere on the board
/Project Architecture/Ethernet Interface/SPI1_MISO: R16.1 (R11); also elsewhere on the board
/Project Architecture/Ethernet Interface/SPI1_MOSI: R16.4 (R14); also elsewhere on the board
/Project Architecture/Ethernet Interface/SPI1_SCLK: R16.3 (R13); also elsewhere on the board
/Project Architecture/Ethernet Interface/SPI1_SCSN: R16.2 (R12); also elsewhere on the board
/Project Architecture/GPIO0: R15.1 (R11); also elsewhere on the board
/Project Architecture/GPIO1: R15.2 (R12); also elsewhere on the board
/Project Architecture/GPIO2: R15.3 (R13); also elsewhere on the board
/Project Architecture/GPIO3: R15.4 (R14); also elsewhere on the board
/Project Architecture/GPIO4: R22.1 (R11); also elsewhere on the board
/Project Architecture/GPIO5: R22.2 (R12); also elsewhere on the board
/Project Architecture/GPIO6: R22.3 (R13); also elsewhere on the board
/Project Architecture/GPIO7: R22.4 (R14); also elsewhere on the board
/Project Architecture/GPIO8: R24.1 (R11); also elsewhere on the board
/Project Architecture/GPIO9: R24.2 (R12); also elsewhere on the board
/Project Architecture/GPIO10: R24.3 (R13); also elsewhere on the board
/Project Architecture/GPIO11: R24.4 (R14); also elsewhere on the board
/Project Architecture/GPIO12: R27.1 (R11); also elsewhere on the board
/Project Architecture/GPIO13: R27.2 (R12); also elsewhere on the board
/Project Architecture/GPIO14: R27.3 (R13); also elsewhere on the board
/Project Architecture/GPIO15: R27.4 (R14); also elsewhere on the board
/Project Architecture/GPIO16: R28.1 (R11); also elsewhere on the board
/Project Architecture/GPIO17: R28.2 (R12); also elsewhere on the board
/Project Architecture/GPIO18: R28.3 (R13); also elsewhere on the board
/Project Architecture/GPIO19: R28.4 (R14); also elsewhere on the board
/Project Architecture/GPIO20: R30.1 (R11); also elsewhere on the board
/Project Architecture/GPIO21: R30.2 (R12); also elsewhere on the board
/Project Architecture/GPIO22: R30.3 (R13); also elsewhere on the board
/Project Architecture/GPIO23: R30.4 (R14); also elsewhere on the board
/Project Architecture/GPIO24: R13.1 (R11); also elsewhere on the board
/Project Architecture/GPIO25: R13.2 (R12); also elsewhere on the board
/Project Architecture/GPIO26: R13.3 (R13); also elsewhere on the board
/Project Architecture/GPIO27: R13.4 (R14); also elsewhere on the board
/Project Architecture/Microcontroller Peripherals/ADC_VREF: R33.1; also elsewhere on the board
/Project Architecture/Microcontroller Peripherals/I2C0_SCL: D1.2 (K2), R18.2, R23.2 (R12); also elsewhere on the board
/Project Architecture/Microcontroller Peripherals/I2C0_SDA: D1.1 (K1), R17.2, R23.1 (R11); also elsewhere on the board
/Project Architecture/Microcontroller/ADC_VUSB: R32.1; also elsewhere on the board
/Project Architecture/Microcontroller/GPIO37: R25.2 (R12)
/Project Architecture/Microcontroller/GPIO38: R25.3 (R13)
/Project Architecture/Microcontroller/GPIO39: R25.4 (R14)
GND: C25.2, C26.2, C27.2, C28.2, C29.2, C30.2, C31.2, C32.2, D1.3 (A), R34.1; also elsewhere on the board
HEARTBEAT: D3.2, IC1.45 (GPIO36), R25.8 (R12)
unnamed: D3.1, R34.2
unnamed: IC1.77 (GPIO0), R15.8 (R12)
unnamed: IC1.78 (GPIO1), R15.7 (R22)
unnamed: IC1.79 (GPIO2), R15.6 (R23)
unnamed: IC1.80 (GPIO3), R15.5 (R24)
unnamed: IC1.1 (GPIO4), R22.8 (R12)
unnamed: IC1.2 (GPIO5), R22.7 (R22)
unnamed: IC1.3 (GPIO6), R22.6 (R23)
unnamed: IC1.4 (GPIO7), R22.5 (R24)
unnamed: IC1.6 (GPIO8), R24.8 (R12)
unnamed: IC1.7 (GPIO9), R24.7 (R22)
unnamed: IC1.8 (GPIO10), R24.6 (R23)
unnamed: IC1.9 (GPIO11), R24.5 (R24)
unnamed: IC1.11 (GPIO12), R27.8 (R12)
unnamed: IC1.12 (GPIO13), R27.7 (R22)
unnamed: IC1.13 (GPIO14), R27.6 (R23)
unnamed: IC1.14 (GPIO15), R27.5 (R24)
unnamed: IC1.16 (GPIO16), R28.8 (R12)
unnamed: IC1.17 (GPIO17), R28.7 (R22)
unnamed: IC1.20 (GPIO20), R30.8 (R12)
unnamed: IC1.21 (GPIO21), R30.7 (R22)
unnamed: IC1.22 (GPIO22), R30.6 (R23)
unnamed: IC1.23 (GPIO23), R30.5 (R24)
unnamed: IC1.25 (GPIO24), R13.8 (R12)
unnamed: IC1.26 (GPIO25), R13.7 (R22)
unnamed: IC1.27 (GPIO26), R13.6 (R23)
unnamed: IC1.28 (GPIO27), R13.5 (R24)
unnamed: IC1.36 (GPIO28), R16.8 (R12)
unnamed: IC1.37 (GPIO29), R16.7 (R22)
unnamed: IC1.38 (GPIO30), R16.6 (R23)
unnamed: IC1.39 (GPIO31), R16.5 (R24)
unnamed: IC1.40 (GPIO32), R23.8 (R12)
unnamed: IC1.42 (GPIO33), R23.7 (R22)
unnamed: IC1.43 (GPIO34), R23.6 (R23)
unnamed: IC1.44 (GPIO35), R23.5 (R24)
unnamed: IC1.46 (GPIO37), R25.7 (R22)
unnamed: IC1.47 (GPIO38), R25.6 (R23)
unnamed: IC1.48 (GPIO39), R25.5 (R24)
unnamed: C25.1, IC1.49 (GPIO40/ADC0), R12.2
unnamed: C26.1, IC1.52 (GPIO41/ADC1), R14.2
unnamed: C27.1, IC1.53 (GPIO42/ADC2), R21.2
unnamed: C28.1, IC1.54 (GPIO43/ADC3), R26.2
unnamed: C29.1, IC1.55 (GPIO44/ADC4), R29.2
unnamed: C30.1, IC1.56 (GPIO45/ADC5), R31.2
unnamed: C31.1, IC1.57 (GPIO46/ADC6), R32.2
unnamed: C32.1, IC1.58 (GPIO47/ADC7), R33.2
unnamed: IC1.18 (GPIO18), R28.6 (R23)
unnamed: IC1.19 (GPIO18), R28.5 (R24)

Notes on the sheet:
I2C PULLUP
HEARTBEAT LED
RP2354B GPIO ASSIGNMENT
[${#}] ${TITLE}

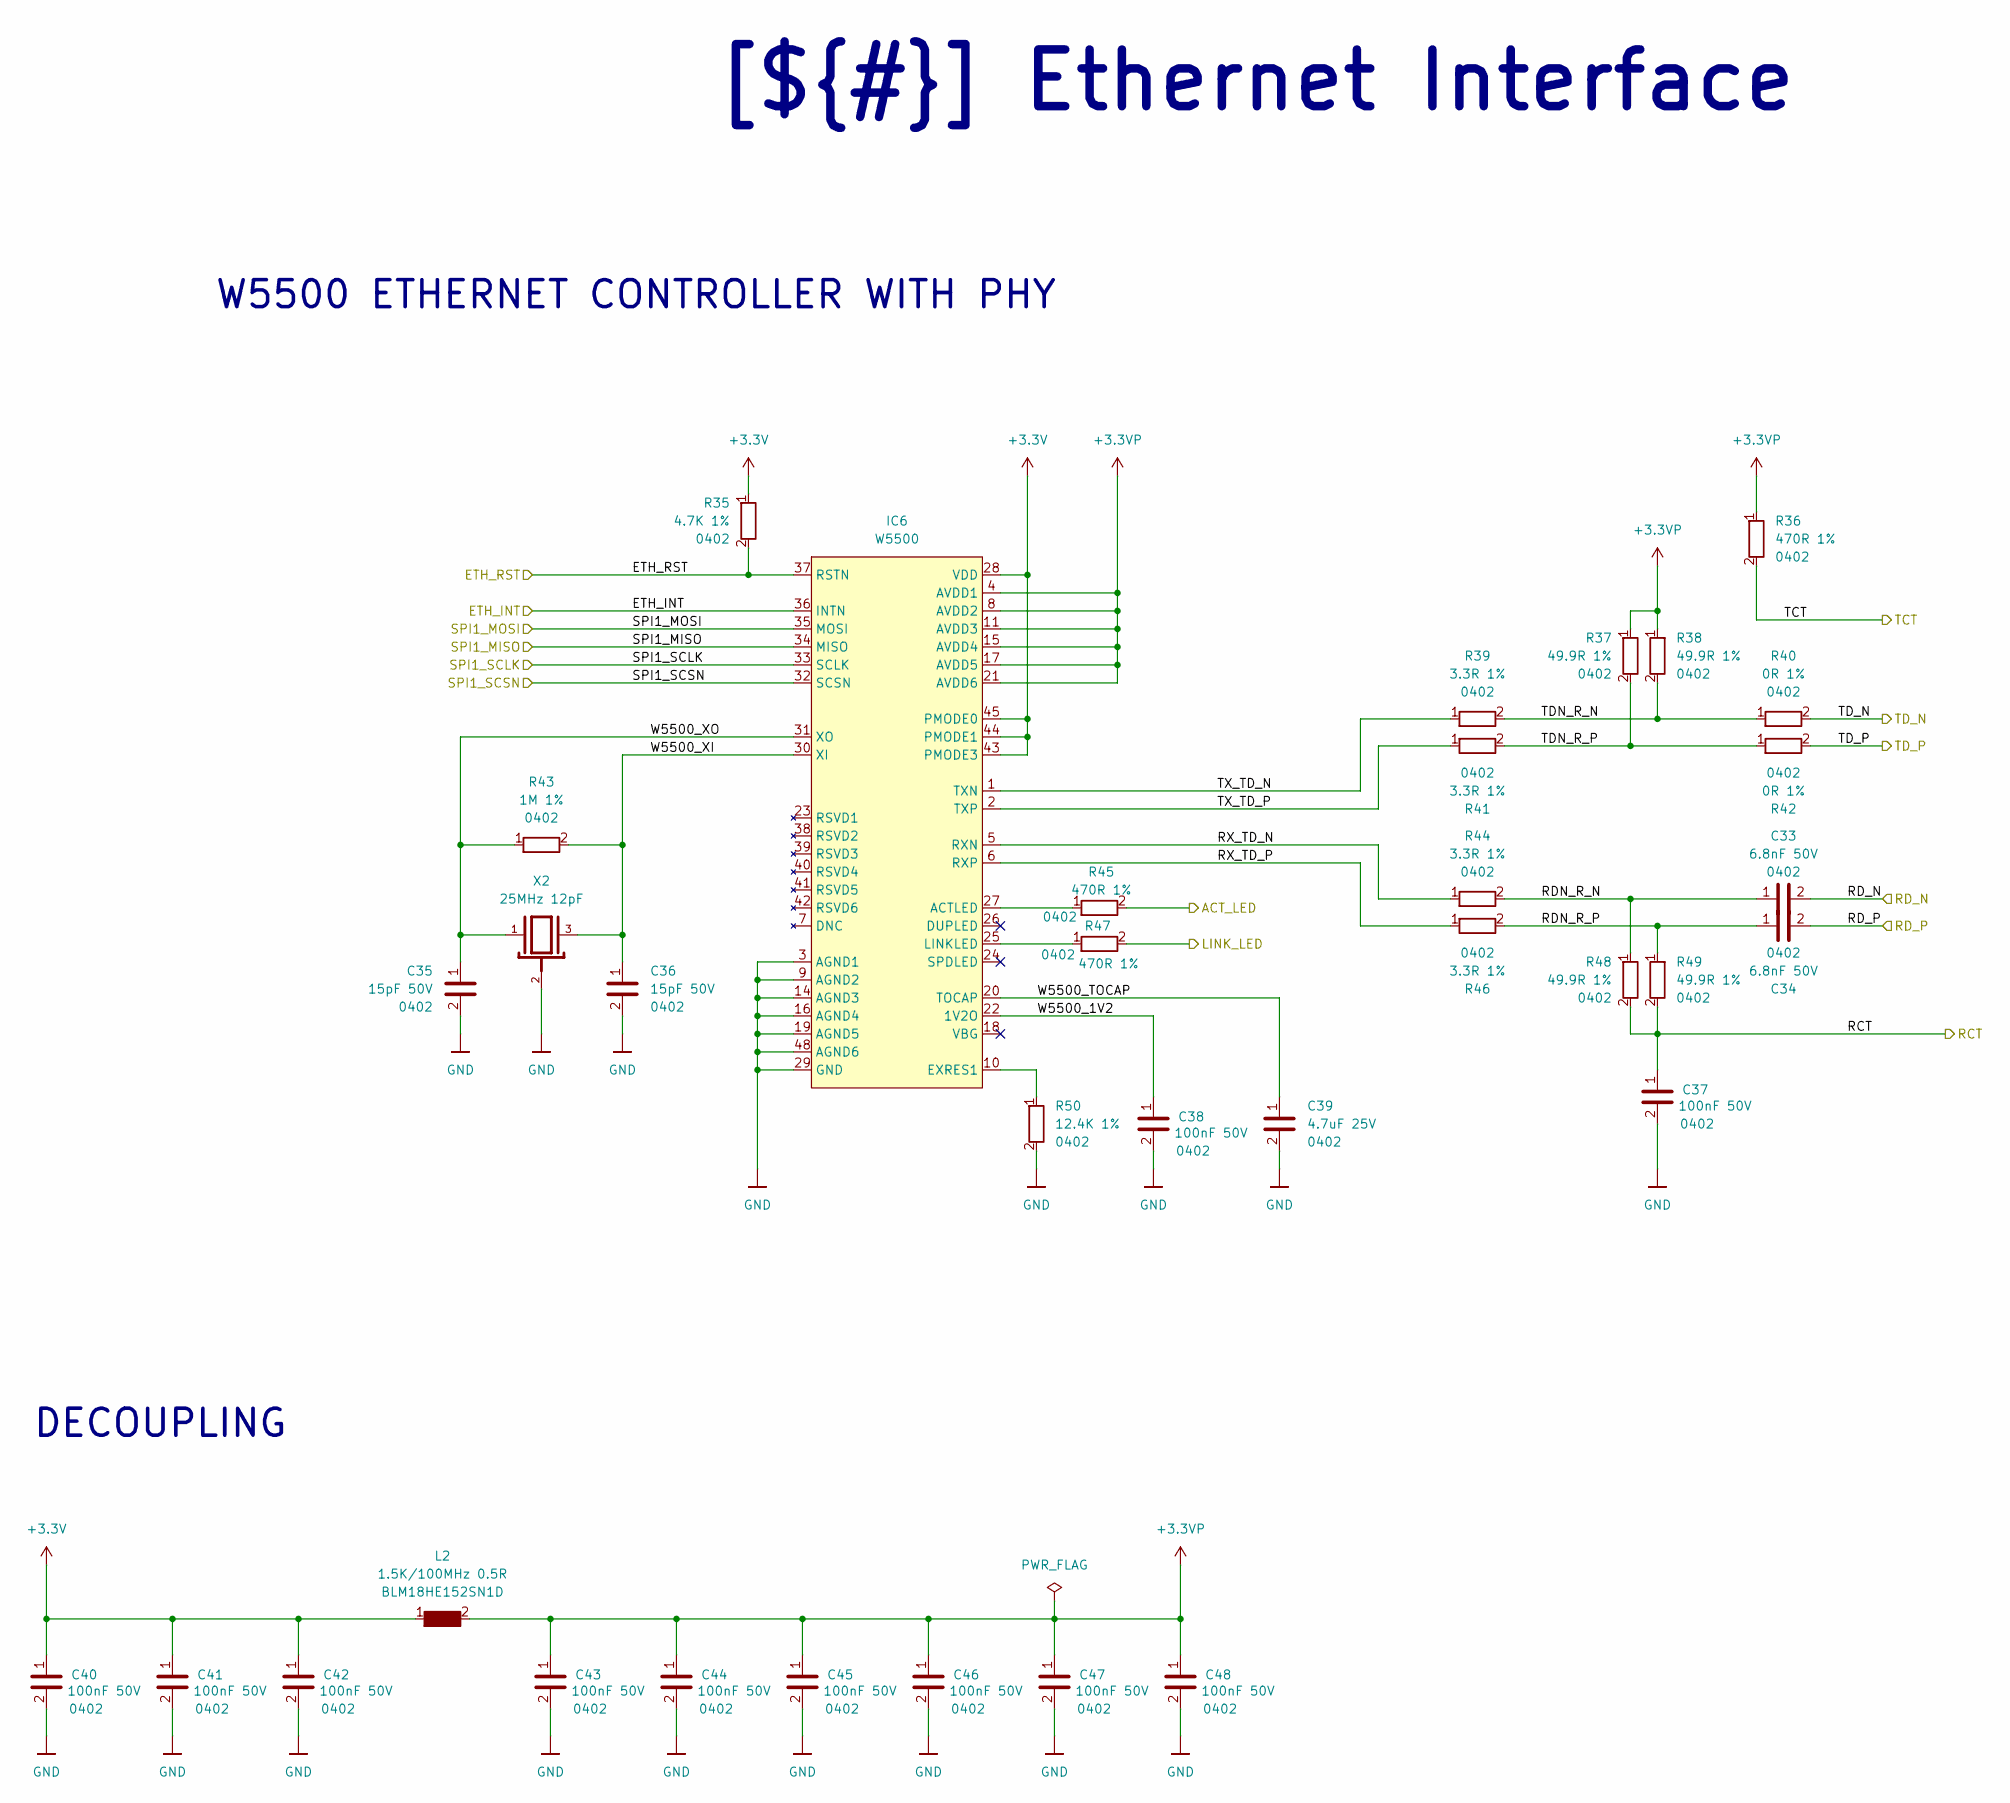
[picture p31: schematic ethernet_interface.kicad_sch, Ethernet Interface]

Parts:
C33, C34: 6.8nF 50V; C_0402_1005Metric; LCSC_PART C1542
C35, C36: 15pF 50V; C_0402_1005Metric; LCSC_PART C1548
C37, C38, C40, C41, C42, C43, C44, C45, C46, C47, C48: 100nF 50V; C_0402_1005Metric; LCSC_PART C307331
C39: 4.7uF 25V; C_0402_1005Metric; LCSC_PART C22367824
IC6: W5500; LQFP48_7x7; MPN W5500; LCSC_PART C32843
L2: 1.5K/100MHz 0.5R; R_0603_1608Metric; MPN BLM18HE152SN1D; LCSC_PART C82155
R35: 4.7K 1%; R_0402_1005Metric; LCSC_PART C25900
R36, R45, R47: 470R 1%; R_0402_1005Metric; LCSC_PART C25117
R37, R38, R48, R49: 49.9R 1%; R_0402_1005Metric; LCSC_PART C25120
R39, R41, R44, R46: 3.3R 1%; R_0402_1005Metric; LCSC_PART C270612
R40, R42: 0R 1%; R_0402_1005Metric; LCSC_PART C17168
R43: 1M 1%; R_0402_1005Metric; LCSC_PART C26083
R50: 12.4K 1%; R_0402_1005Metric; LCSC_PART C490814
X2: 25MHz 12pF; X3225; MPN X322525MOB4SI; LCSC_PART C9006

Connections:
+3.3V: C40.1, C41.1, C42.1, IC6.28 (VDD), IC6.43 (PMODE3), IC6.44 (PMODE1), IC6.45 (PMODE0), L2.1, R35.1; also elsewhere on the board
+3.3VP: C43.1, C44.1, C45.1, C46.1, C47.1, C48.1, IC6.4 (AVDD1), IC6.8 (AVDD2), IC6.11 (AVDD3), IC6.15 (AVDD4), IC6.17 (AVDD5), IC6.21 (AVDD6), L2.2, R36.1, R37.1, R38.1
/Project Architecture/ACT_LED: R45.2; also elsewhere on the board
/Project Architecture/Ethernet Interface/ETH_INT: IC6.36 (INTN); also elsewhere on the board
/Project Architecture/Ethernet Interface/ETH_RST: IC6.37 (RSTN), R35.2; also elsewhere on the board
/Project Architecture/Ethernet Interface/RDN_R_N: C33.1, R44.2, R48.1
/Project Architecture/Ethernet Interface/RDN_R_P: C34.1, R46.2, R49.1
/Project Architecture/Ethernet Interface/RX_TD_N: IC6.5 (RXN), R44.1
/Project Architecture/Ethernet Interface/RX_TD_P: IC6.6 (RXP), R46.1
/Project Architecture/Ethernet Interface/SPI1_MISO: IC6.34 (MISO); also elsewhere on the board
/Project Architecture/Ethernet Interface/SPI1_MOSI: IC6.35 (MOSI); also elsewhere on the board
/Project Architecture/Ethernet Interface/SPI1_SCLK: IC6.33 (SCLK); also elsewhere on the board
/Project Architecture/Ethernet Interface/SPI1_SCSN: IC6.32 (SCSN); also elsewhere on the board
/Project Architecture/Ethernet Interface/TDN_R_N: R38.2, R39.2, R40.1
/Project Architecture/Ethernet Interface/TDN_R_P: R37.2, R41.2, R42.1
/Project Architecture/Ethernet Interface/TX_TD_N: IC6.1 (TXN), R39.1
/Project Architecture/Ethernet Interface/TX_TD_P: IC6.2 (TXP), R41.1
/Project Architecture/Ethernet Interface/W5500_1V2: C38.1, IC6.22 (1V2O)
/Project Architecture/Ethernet Interface/W5500_TOCAP: C39.1, IC6.20 (TOCAP)
/Project Architecture/Ethernet Interface/W5500_XI: C36.1, IC6.30 (XI), R43.2, X2.3
/Project Architecture/Ethernet Interface/W5500_XO: C35.1, IC6.31 (XO), R43.1, X2.1
/Project Architecture/LINK_LED: R47.2; also elsewhere on the board
/Project Architecture/RCT: C37.1, R48.2, R49.2; also elsewhere on the board
/Project Architecture/RD_N: C33.2; also elsewhere on the board
/Project Architecture/RD_P: C34.2; also elsewhere on the board
/Project Architecture/TCT: R36.2; also elsewhere on the board
/Project Architecture/TD_N: R40.2; also elsewhere on the board
/Project Architecture/TD_P: R42.2; also elsewhere on the board
GND: C35.2, C36.2, C37.2, C38.2, C39.2, C40.2, C41.2, C42.2, C43.2, C44.2, C45.2, C46.2, C47.2, C48.2, IC6.3 (AGND1), IC6.9 (AGND2), IC6.14 (AGND3), IC6.16 (AGND4), IC6.19 (AGND5), IC6.29 (GND), IC6.48 (AGND6), R50.2, X2.2; also elsewhere on the board
unnamed: IC6.27 (ACTLED), R45.1
unnamed: IC6.10 (EXRES1), R50.1
unnamed: IC6.25 (LINKLED), R47.1

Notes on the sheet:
DECOUPLING
W5500 ETHERNET CONTROLLER WITH PHY
[${#}] ${TITLE}

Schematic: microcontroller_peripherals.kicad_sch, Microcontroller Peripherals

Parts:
C1, C2, C3, C4, C5, C7, C8, C9, C10, C13, C14, C15, C17, C18, C19, C21, C23: 100nF 50V; C_0402_1005Metric; LCSC_PART C307331
C6, C16: 4.7uF 25V; C_0402_1005Metric; LCSC_PART C22367824
C11, C12: 10pF 50V; C_0402_1005Metric; LCSC_PART C466222
C20, C22, C24: 4.7uF 10V; C_0402_1005Metric; LCSC_PART C368809
IC1: RP2354B; QFN80_10x10; MPN RP2354B; LCSC_PART C39843328
IC2: AT24C256C-XHL-T; TSSOP-8; MPN AT24C256C-XHL-T; LCSC_PART C33035
IC3: W25Q128JVPIQ; WSON8_6x5; MPN W25Q128JVPIQ; LCSC_PART C190862
IC4: MCP6001RT; SOT-23-5; MPN MCP6001RT-I/OT; LCSC_PART C154973
IC5: LM4040B30FTA; SOT-23; MPN LM4040B30FTA; LCSC_PART C460604
J2: SM03B-SRSS-TB; JST_SM03B-SRSS-TB_LF__SN_; MPN SM03B-SRSS-TB; LCSC_PART C160403
L1: 3.3uH 2.8A; 0805; MPN AOTA-B201610S3R3-101-T; LCSC_PART C42411119
R1, R8: 4.7K 1%; R_0402_1005Metric; LCSC_PART C25900
R2, R3, R4: 33R 1%; R_0402_1005Metric; LCSC_PART C25105
R5: 1K 1%; R_0402_1005Metric; LCSC_PART C11702
R6: 1K 1%; R_0402_1005Metric; LCSC_PART C11702; not fitted
R7: 27R 1%; R_0402_1005Metric; LCSC_PART C138021
R9: 27R 1%; R_0402_1005Metric; LCSC_PART C138021; not fitted
R10, R11: 10K 1%; R_0402_1005Metric; LCSC_PART C25744
SW1, SW2: B3U-1000P; SW_B3U-1000P; MPN B3U-1000P; LCSC_PART C231329
X1: 12MHz 10pF; X3225; MPN ABM8-272-T3; LCSC_PART C20625731

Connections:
+1V1: C13.1, C14.1, C15.1, C16.1, IC1.10 (DVDD1), IC1.32 (DVDD2), IC1.51 (DVDD3), IC1.65 (VREF_FB), L1.1
+3.3V: C1.1, C2.1, C3.1, C4.1, C5.1, C7.1, C8.1, C9.1, C10.1, C17.1, C18.1, C20.1, IC1.5 (IOVDD1), IC1.15 (IOVDD2), IC1.24 (IOVDD3), IC1.29 (IOVDD4), IC1.41 (IOVDD5), IC1.50 (IOVDD6), IC1.60 (IOVDD7), IC1.64 (VREG_IN), IC1.68 (USB_OTP_VDD), IC1.69 (QSPI_IOVDD), IC1.76 (IOVDD8), IC2.8 (VCC), IC3.8 (VCC), R1.1, R2.1, R6.1, R7.2, R8.1, R9.2; also elsewhere on the board
/Project Architecture/Microcontroller Peripherals/ADC_VREF: R10.2, R11.1; also elsewhere on the board
/Project Architecture/Microcontroller Peripherals/I2C0_SCL: IC2.6 (SCL); also elsewhere on the board
/Project Architecture/Microcontroller Peripherals/I2C0_SDA: IC2.5 (SDA); also elsewhere on the board
/Project Architecture/Microcontroller Peripherals/RP_D+: IC1.67 (USB_DP), R4.2
/Project Architecture/Microcontroller Peripherals/RP_D-: IC1.66 (USB_DM), R3.1
/Project Architecture/Microcontroller Peripherals/SWCLK: IC1.33 (SWCLK), J2.3 (SWDAT)
/Project Architecture/Microcontroller Peripherals/SWDIO: IC1.34 (SWDIO), J2.1 (SWCLK)
/Project Architecture/Microcontroller Peripherals/VREF_IN: C21.1, C22.1, IC4.3 (+), IC5.1 (K), R8.2
/Project Architecture/Microcontroller Peripherals/VREG_AVDD: C6.1, IC1.61 (VREG_AVDD), R2.2
/Project Architecture/Microcontroller Peripherals/VREG_LX: IC1.63 (VREG_LC), L1.2
/Project Architecture/Microcontroller Peripherals/XIN: C12.1, IC1.30 (XIN), X1.3
/Project Architecture/Microcontroller Peripherals/XO: C11.1, R5.2, X1.1
/Project Architecture/Microcontroller Peripherals/XOUT: IC1.31 (XOUT), R5.1
/Project Architecture/USB Interface and Power/USB_RP_D+: R4.1; also elsewhere on the board
/Project Architecture/USB Interface and Power/USB_RP_D-: R3.2; also elsewhere on the board
GND: C1.2, C2.2, C3.2, C4.2, C5.2, C6.2, C7.2, C8.2, C9.2, C10.2, C11.2, C12.2, C13.2, C14.2, C15.2, C16.2, C17.2, C18.2, C19.2, C20.2, C21.2, C22.2, C23.2, C24.2, IC1.62 (VREG_PGND), IC1.81 (GND), IC2.1 (A0), IC2.2 (A1), IC2.3 (A2), IC2.4 (GND), IC2.7 (WP), IC3.4 (GND), IC3.9 (PAD), IC4.5 (V-), IC5.2 (A), J2.2 (GND), J2.S1 (SHIELD), J2.S2 (SHIELD), R11.2, SW1.2, SW2.2, X1.2; also elsewhere on the board
unnamed: C19.1, IC4.2 (V+), R7.1
QSPI_SCLK: IC1.71 (QSPI_SCLK), IC3.6 (CLK)
QSPI_SD0: IC1.72 (QSPI_SD0), IC3.5 (DI(IO0))
QSPI_SD1: IC1.74 (QSPI_SD1), IC3.2 (DO(IO1))
QSPI_SD2: IC1.73 (QSPI_SD2), IC3.3 (nWP(IO2))
QSPI_SD3: IC1.70 (QSPI_SD3), IC3.7 (nRST(IO3))
QSPI_SS: IC1.75 (QSPI_SS), IC3.1 (nCS), R6.2, SW1.1
RESET: IC1.35 (RUN), R1.2, SW2.1
VREF_OUT: C23.1, C24.1, IC1.59 (ADC_AVDD), IC4.1, IC4.4 (-), R9.1, R10.1

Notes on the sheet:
EXTERNAL EEPROM
PUSHBUTTONS
EXTERNAL FLASH
RP2354B MICROCONTROLLER
HW Design Guide: RC filter of 33Ω and 4.7μF is adequate
HW Design Guide: recommended to use 100nF capacitor per power pin
3.0V ADC VOLTAGE REFERENCE
12MHz 10pF -> Assuming 5pF parasitics Csum = 10pF - 5pF = 5pF C1 = C2 = 5pF x 2 = 10pF
[${#}] ${TITLE}

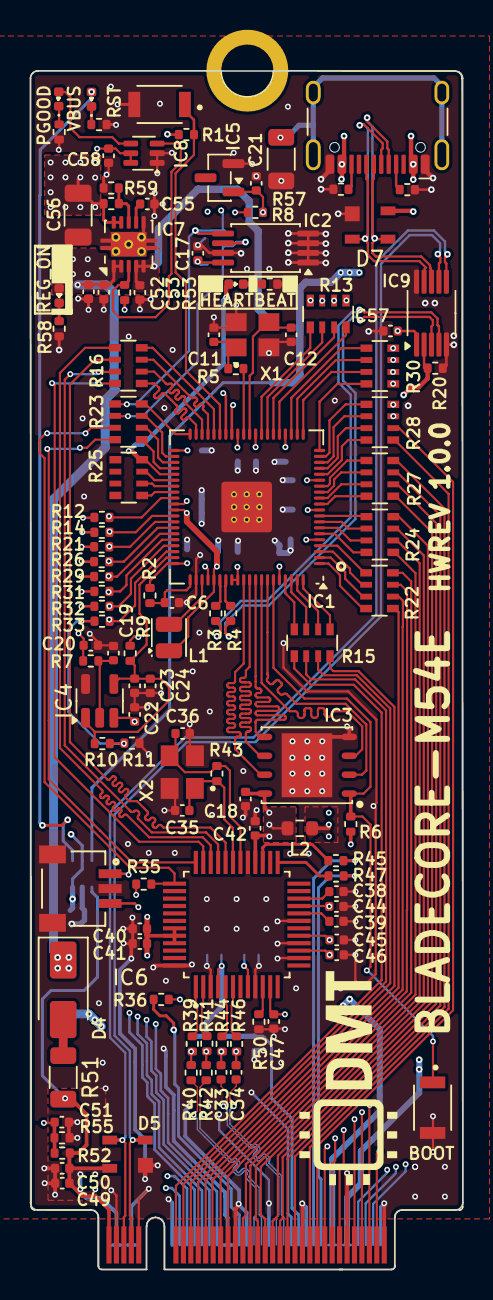
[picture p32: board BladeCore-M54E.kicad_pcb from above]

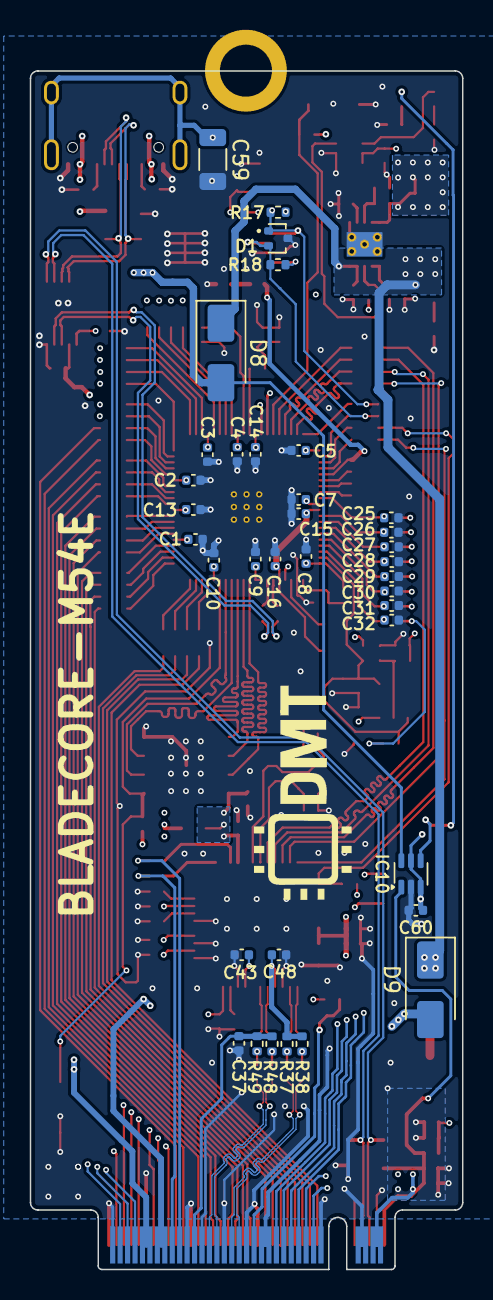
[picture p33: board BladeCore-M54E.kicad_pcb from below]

Board: 6 copper layers, 29.0 x 80.6 mm, 150 parts (36 on the bottom side), 161 nets.

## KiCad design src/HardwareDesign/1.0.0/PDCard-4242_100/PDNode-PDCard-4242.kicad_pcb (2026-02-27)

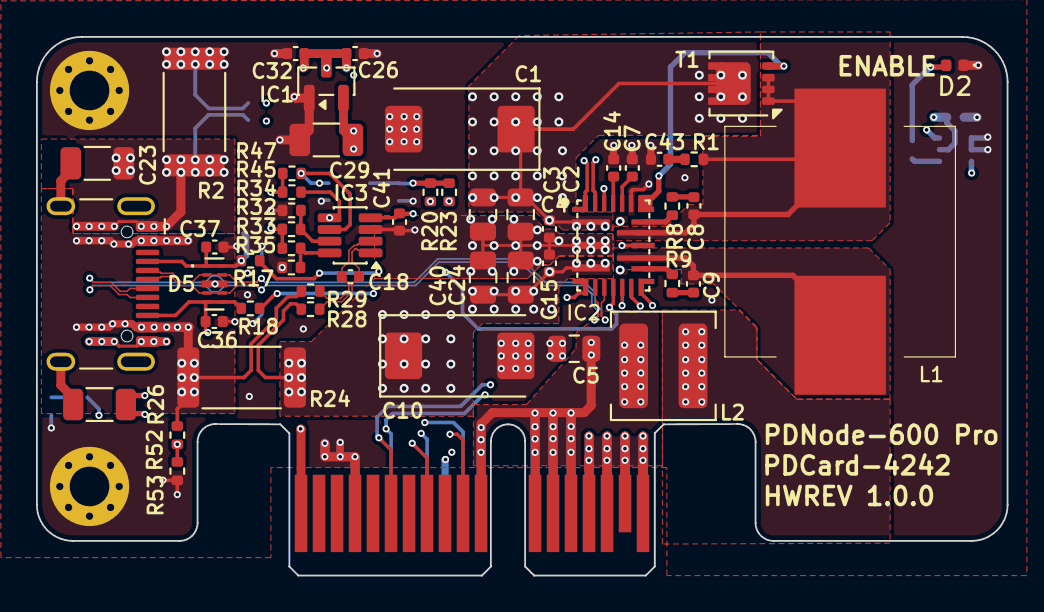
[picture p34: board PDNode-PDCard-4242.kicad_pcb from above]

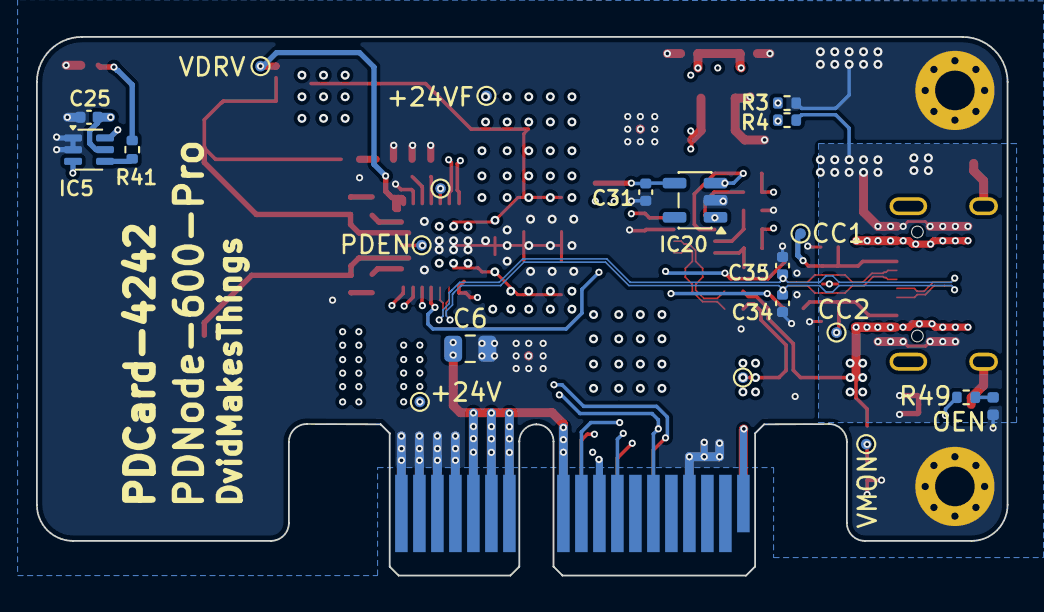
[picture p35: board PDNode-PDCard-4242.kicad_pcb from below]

Board: 6 copper layers, 53.9 x 29.9 mm, 75 parts (21 on the bottom side), 40 nets.

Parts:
C1, C10: 100uF 25V; CP_EIA-7343-30_AVX-N
C2, C3, C5, C6: 4.7uF 50V; C_0805_2012Metric
C4, C15, C18, C25, C31, C32, C41: 100nF 50V; C_0402_1005Metric
C7: 2.2uF 25V; C_0402_1005Metric
C8, C9: 220nF 50V; C_0402_1005Metric
C14: 470pF 50V; C_0402_1005Metric
C23: 1nF 2kV; C_1206_3216Metric
C24, C40: 10uF 50V; C_0805_2012Metric
C26: 1uF 50V; C_0402_1005Metric
C29: 10uF 50V; C_1206_3216Metric
C34, C35, C43: 1nF 50V; C_0402_1005Metric
C36, C37: 390pF 50V; C_0402_1005Metric
CC1, CC2: TestPoint_0.6mm
D1: Green; LED_0402_1005Metric
D2: Blue; LED_0402_1005Metric
D5: TPD4EUSB30DQAR; USON10_2.5x1
H1, H2: MountingHole_Pad; MountingHole_2.2mm_M2_Pad_Via
IC1: MCP1702T-3302E/CB; SOT-23
IC2: MPQ4242GVE-0001-AEC1-P; QFN-22_4X5mm
IC3: INA219BIDCNT; SOT-23-8
IC5: SN74LVC1G97QDCKRQ1; SOT-363_SC-70-6
IC20: 24AA02E-OT; SOT-23-5
J1: USB-TYPE-C-018; USB_C_Receptacle_HCTL_HC-TYPE-C-16P-01A
J2: PCIE EDGE CONNECTOR; BUS_PCIexpress_x1
L1: 4.7uH 13A; 7443551470
L2: 2.2uH 9.7A; 5.5x5.3mm_XAL5030-222MEC
PDAT1: TestPoint_0.6mm
PDEN1: TestPoint_0.6mm
PDOUT1: TestPoint_0.6mm
R1, R3, R4, R28, R29: 1R 1%; R_0402_1005Metric
R2: 0.010R 1%; R_2512_6332Metric
R8, R9: 0R 1%; R_0402_1005Metric
R17, R18: 2.2R 1%; R_0402_1005Metric
R20, R23: 100K 1%; R_0402_1005Metric
R24: 0.005R 1% 2W; R_2512_6332Metric
R26: 1M 1%; R_1206_3216Metric
R32, R33, R34, R35, R53: 10K 1%; R_0402_1005Metric
R41, R49: 1K 1%; R_0402_1005Metric
R45, R47: 2.4K 1%; R_0402_1005Metric
R52: 90.9K 1%; R_0402_1005Metric
T1: DMN4008LFG-7; Diodes_PowerDI3333-8
V24, V24F1: TestPoint_0.6mm
VDRV1: TestPoint_0.6mm
VMON1: TestPoint_0.6mm

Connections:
+3.3V: C25.1, C29.1, C31.1, C41.1, IC1.2 (VOUT), IC3.4 (VS), IC5.5 (VCC), IC20.4 (V_{CC}), R20.1, R23.1, R32.1, R33.1, R45.1, R47.1
+5V: C26.1, C32.1, IC1.3 (VIN), IC2.8 (GPIO2), J2.A1, J2.A9, J2.B1
+24V: C5.1, C6.1, J2.A11, J2.A12, J2.A13, J2.A14, J2.B11, J2.B12, J2.B13, J2.B14 (B13), L2.1, V24.1
+24V_FILTERED: C1.1, C2.1, C3.1, C4.1, IC2.1 (VIN), L2.2, T1.5 (D), T1.6 (D), T1.7 (D), T1.8 (D), V24F1.1
/Project Architecture/Board Connector and Supplies/PORT_EN: IC5.6 (IN2), J2.B8, R49.2
/Project Architecture/Board Connector and Supplies/VBUS_VMON_PORT0: J2.B10, R52.2, R53.1, VMON1.1
/Project Architecture/USB-PD Source Controller/CC1: C37.1, CC1.1, D5.1, J1.A5 (CC1), R17.2
/Project Architecture/USB-PD Source Controller/CC2: C36.1, CC2.1, D5.5, J1.B5 (CC2), R18.2
/Project Architecture/USB-PD Source Controller/I2C_SCL: IC2.10 (SCL), IC3.5 (SCL), IC20.1 (SCL), J2.A6, R45.2
/Project Architecture/USB-PD Source Controller/I2C_SDA: IC2.9 (SDA), IC3.6 (SDA), IC20.3 (SDA), J2.B6, R47.2
/Project Architecture/USB-PD Source Controller/ISEN+: IC2.22 (ISENS+), R4.2
/Project Architecture/USB-PD Source Controller/ISEN-: IC2.21 (ISENS-), R3.2
/Project Architecture/USB-PD Source Controller/PD_ATTACH: IC2.20 (GPIO1), J2.A10, PDAT1.1, R23.2
/Project Architecture/USB-PD Source Controller/PD_CC1: IC2.7 (CC1), R17.1
/Project Architecture/USB-PD Source Controller/PD_CC2: IC2.4 (CC2), R18.1
/Project Architecture/USB-PD Source Controller/PD_ENABLE: IC2.13 (EN), IC5.3 (IN0), J2.A8, PDEN1.1, R20.2
/Project Architecture/USB-PD Source Controller/PD_OUT: C10.1, C15.1, C24.1, C40.1, IC2.3 (OUT), PDOUT1.1, R24.1, R28.1
/Project Architecture/USB-PD Source Controller/SW1: C8.1, IC2.14 (SW1), L1.1, R1.1, T1.1 (S), T1.2 (S), T1.3 (S)
/Project Architecture/USB-PD Source Controller/SW2: C9.1, IC2.12 (SW2), L1.2
/Project Architecture/USB-PD Source Controller/USB_D+: C34.1, D5.4, IC2.5 (DP), J1.A6 (D+), J1.B6 (D+)
/Project Architecture/USB-PD Source Controller/USB_D-: C35.1, D5.2, IC2.6 (DM), J1.A7 (D-), J1.B7 (D-)
/Project Architecture/USB-PD Source Controller/VBUS: J1.A4 (VBUS), J1.A9 (VBUS), J1.B4 (VBUS), J1.B9 (VBUS), R24.2, R29.1, R52.1
/Project Architecture/USB-PD Source Controller/VBUS_MEA_N: C18.2, IC3.2 (IN-), R29.2
/Project Architecture/USB-PD Source Controller/VBUS_MEA_P: C18.1, IC3.1 (IN+), R28.2
/Project Architecture/USB-PD Source Controller/VDRV: IC2.16 (HS_G), T1.4 (S), VDRV1.1
GND: C1.2, C2.2, C3.2, C4.2, C5.2, C6.2, C7.2, C10.2, C14.2, C15.2, C24.2, C25.2, C26.2, C29.2, C31.2, C32.2, C34.2, C35.2, C36.2, C37.2, C40.2, C41.2, C43.2, D1.1, D2.1, D5.3, H1.1, H2.1, IC1.1 (GND), IC2.2 (PGND), IC2.17 (AGND), IC3.3 (GND), IC5.1 (IN1), IC5.2 (GND), IC20.2 (V_{SS}), J2.A4, J2.A15, J2.A16, J2.A17, J2.A18, J2.B4, J2.B15, J2.B16, J2.B17, J2.B18, R2.2, R3.1, R34.2, R35.2, R53.2
GND_USB: C23.1, J1.A1 (GND), J1.A12 (GND), J1.B1 (GND), J1.B12 (GND), R2.1, R4.1, R26.1
unnamed: C8.2, R8.2
unnamed: C9.2, R9.2
unnamed: C43.1, R1.2
unnamed: D1.2, R49.1
unnamed: D2.2, R41.2
unnamed: IC2.15 (BST1), R8.1
unnamed: IC2.11 (BST2), R9.1
unnamed: C14.1, IC2.19 (ICOMP)
unnamed: C7.1, IC2.18 (VCC)
unnamed: IC3.7 (A0), R32.2, R34.1
unnamed: IC3.8 (A1), R33.2, R35.1
unnamed: IC5.4 (Y), R41.1
SHIELD: C23.2, J1.S1 (SHIELD), R26.2

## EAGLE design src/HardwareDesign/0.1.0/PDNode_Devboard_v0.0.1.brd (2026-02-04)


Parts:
AVDD: DNI; TP-ROUND
C1, C7, C8, C9, C10, C12, C13, C14, C15, C19, C20, C23, C24, C25, C27, C56, C57, C58, C59, C60, C61: 100nF 25V; 0201
C21, C22, C26, C64: 4.7uF 25V; 0402
C62, C63: 15pF 50V; 0201
IC26: RP2354B; QFN80-10X10
IC27, IC39: W25Q128JVPIQ; SON127P600X500X75-8N
IC28: MCP6001RT-I/OT; SOT23-5
L1: 3.3uH; 0805
R6, R7: 1K 1%; 0201
R8, R209, R278: DNI; R0201
R24: 10K 1%; 0201
R25, R26: 27R 1%; 0201
R27: 33R 1%; 0402
R28, R29: 0R 1%; 0402
R212: 4.7K 1%; 0201
REF1: LM4040x30; SOT23
SW1, SW2: B3U-1000P
VREF: DNI; TP-ROUND
X1: 12MHz; WE-XTAL_CFPX-180

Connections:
!QSPI_SS: IC26.75 (QSPI_SS), IC27.1 (!CS), R6.2, R209.1
+1V1: C26.1, C58.1, C59.1, C60.1, C61.1, IC26.10 (DVDD1), IC26.32 (DVDD2), IC26.51 (DVDD3), IC26.65 (VREG_FB), IC26.68 (USB_OTP_VDD), IC26.69 (QSPI_IOVDD), L1.2
+3V3: C1.1, C9.1, C10.1, C13.1, C14.1, C15.1, C19.1, C20.1, C22.1, C23.1, C24.1, C25.1, C27.1, C56.1, C57.1, IC26.5 (IOVDD1), IC26.15 (IOVDD2), IC26.24 (IOVDD3), IC26.29 (IOVDD4), IC26.41 (IOVDD5), IC26.50 (IOVDD6), IC26.60 (IOVDD7), IC26.64 (VREG_IN), IC26.76 (IOVDD8), IC27.8 (VCC), IC28.2 (V+), IC39.8 (VCC), R8.2, R24.1, R27.1, R29.1, R209.2, R212.2, R278.2; also elsewhere on the board
ADC_AVDD: C12.1, IC26.59 (ADC_AVDD), R28.1, R29.2
AVDD: AVDD.TP, C8.1, IC28.1 (OUT), IC28.4 (-IN), R8.1, R28.2
GND: C1.2, C7.2, C8.2, C9.2, C10.2, C12.2, C13.2, C14.2, C15.2, C19.2, C20.2, C21.2, C22.2, C23.2, C24.2, C25.2, C26.2, C27.2, C56.2, C57.2, C58.2, C59.2, C60.2, C61.2, C62.2, C63.2, C64.2, IC26.62 (VREG_PGND), IC26.81 (GND), IC27.4 (GND), IC27.PAD (GND), IC28.5 (V-), IC39.4 (GND), IC39.PAD (GND), REF1.2 (A), REF1.3 (A), SW1.1, SW2.2, X1.2 (GND), X1.4 (GND); also elsewhere on the board
unnamed: C21.1, IC26.61 (VREG_AVDD), R27.2
unnamed: IC26.63 (VREG_LX), L1.1
unnamed: C62.1, R7.1, X1.3 (2)
QMI_CS1: IC39.1 (!CS), R278.1; also elsewhere on the board
QSPI_SCLK: IC26.71 (QSPI_SCLK), IC27.6 (CLK), IC39.6 (CLK)
QSPI_SD0: IC26.72 (QSPI_SD0), IC27.5 (DI/IO0), IC39.5 (DI/IO0)
QSPI_SD1: IC26.74 (QSPI_SD1), IC27.2 (DO/IO1), IC39.2 (DO/IO1)
QSPI_SD2: IC26.73 (QSPI_SD2), IC27.3 (!WP!/IO2), IC39.3 (!WP!/IO2)
QSPI_SD3: IC26.70 (QSPI_SD3), IC27.7 (!HOLD!/IO3), IC39.7 (!HOLD!/IO3)
RP_XI: C63.1, IC26.30 (XIN), X1.1
RP_XO: IC26.31 (XOUT), R7.2
RUN: IC26.35 (RUN), R24.2, SW1.2; also elsewhere on the board
SWCLK: IC26.33 (SWCLK); also elsewhere on the board
SWDIO: IC26.34 (SWDIO); also elsewhere on the board
USB_BOOT: R6.1, SW2.1; also elsewhere on the board
USB_RPR_DP_N: IC26.66 (USB_DM), R25.2
USB_RPR_DP_P: IC26.67 (USB_DP), R26.2
USB_RP_DP_N: R25.1; also elsewhere on the board
USB_RP_DP_P: R26.1; also elsewhere on the board
VREF: C7.1, C64.1, IC28.3 (+IN), R212.1, REF1.1 (C), VREF.TP

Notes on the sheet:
RP2040 MCU
MCU FLASH
ADC VREF
MICROCONTROLLER - POWER
MCU 2ND FLASH


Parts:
C65: 100nF 25V; 0201
D12: HDMIULC6-4SC6Y; SOT23-6
IC26: RP2354B; QFN80-10X10
IC29: CAT24C256HU4IGT3; SON50P300X200X50-9T130X140N
JTAG: 3220_10_0300_00
R9: 4.7K 1%; 0201
R213: NC; R0201
RN1: 3.3K 1%; _0603X4-1206
TCC0, TCC1, TCC2, TCC3, TCC4, TCC5, TCC6, TCC7: DNI; TP-ROUND
TCD0, TCD1, TCD2, TCD3, TCD4, TCD5, TCD6, TCD7: DNI; TP-ROUND

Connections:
!DUP: IC26.22 (GPIO22); also elsewhere on the board
!SPD: IC26.23 (GPIO23); also elsewhere on the board
!TCA_RST: IC26.80 (GPIO3); also elsewhere on the board
!W5500_CS: IC26.17 (GPIO17); also elsewhere on the board
!W5500_INT: IC26.21 (GPIO21); also elsewhere on the board
!W5500_RST: IC26.20 (GPIO20); also elsewhere on the board
+3V3: C65.1, D12.5, IC29.8 (VCC), JTAG.1, R213.2, RN1.A2 (8), RN1.B2 (7), RN1.C2 (6), RN1.D2 (5); also elsewhere on the board
ADC_3VA: IC26.52 (GPIO41_ADC1)
ADC_24VA: IC26.53 (GPIO42_ADC2); also elsewhere on the board
ADC_24VB: IC26.54 (GPIO43_ADC3); also elsewhere on the board
ADC_24VC: IC26.55 (GPIO44_ADC4); also elsewhere on the board
ADC_VUSB: IC26.49 (GPIO40_ADC0); also elsewhere on the board
EN_PORT1: IC26.25 (GPIO24); also elsewhere on the board
EN_PORT2: IC26.26 (GPIO25)
EN_PORT3: IC26.27 (GPIO26)
EN_PORT4: IC26.28 (GPIO27)
EN_PORT5: IC26.36 (GPIO28)
EN_PORT6: IC26.37 (GPIO29)
EN_PORT7: IC26.38 (GPIO30)
EN_PORT8: IC26.39 (GPIO31)
GND: C65.2, D12.2, IC29.2 (A1), IC29.3 (A2), IC29.4 (GND), IC29.7 (WP), IC29.9 (GND), JTAG.3, JTAG.5, JTAG.9, R9.2; also elsewhere on the board
I2C0_SCL: D12.3, IC26.2 (GPIO5), RN1.B1 (2); also elsewhere on the board
I2C0_SDA: D12.1, IC26.1 (GPIO4), RN1.D1 (4); also elsewhere on the board
I2C1_SCL: D12.6, IC26.4 (GPIO7), IC29.6 (SCL), RN1.C1 (3); also elsewhere on the board
I2C1_SDA: D12.4, IC26.3 (GPIO6), IC29.5 (SDA), RN1.A1 (1); also elsewhere on the board
KEY_0: IC26.11 (GPIO12); also elsewhere on the board
KEY_1: IC26.12 (GPIO13); also elsewhere on the board
KEY_2: IC26.13 (GPIO14); also elsewhere on the board
KEY_3: IC26.14 (GPIO15); also elsewhere on the board
unnamed: IC29.1 (A0), R9.1, R213.1
OCP1: IC26.45 (GPIO36); also elsewhere on the board
OCP2: IC26.46 (GPIO37); also elsewhere on the board
OCP3: IC26.47 (GPIO38)
OCP4: IC26.48 (GPIO39)
QMI_CS1: IC26.6 (GPIO8); also elsewhere on the board
RUN: JTAG.10; also elsewhere on the board
SWCLK: JTAG.4; also elsewhere on the board
SWDIO: JTAG.2; also elsewhere on the board
TCA0_I2C_SCL: TCC0.TP; also elsewhere on the board
TCA0_I2C_SDA: TCD0.TP; also elsewhere on the board
TCA1_I2C_SCL: TCC1.TP; also elsewhere on the board
TCA1_I2C_SDA: TCD1.TP; also elsewhere on the board
TCA2_I2C_SCL: TCC2.TP; also elsewhere on the board
TCA2_I2C_SDA: TCD2.TP; also elsewhere on the board
TCA3_I2C_SCL: TCC3.TP; also elsewhere on the board
TCA3_I2C_SDA: TCD3.TP; also elsewhere on the board
TCA4_I2C_SCL: TCC4.TP; also elsewhere on the board
TCA4_I2C_SDA: TCD4.TP; also elsewhere on the board
TCA5_I2C_SCL: TCC5.TP; also elsewhere on the board
TCA5_I2C_SDA: TCD5.TP; also elsewhere on the board
TCA6_I2C_SCL: TCC6.TP; also elsewhere on the board
TCA6_I2C_SDA: TCD6.TP; also elsewhere on the board
TCA7_I2C_SCL: TCC7.TP; also elsewhere on the board
TCA7_I2C_SDA: TCD7.TP; also elsewhere on the board
UART0_RX: IC26.78 (GPIO1), JTAG.6
UART0_TX: IC26.77 (GPIO0), JTAG.8
USBA1_EN: IC26.40 (GPIO32); also elsewhere on the board
USBA2_EN: IC26.42 (GPIO33); also elsewhere on the board
USBA3_EN: IC26.43 (GPIO34)
USBA4_EN: IC26.44 (GPIO35)
USB_BOOT: JTAG.7; also elsewhere on the board
W5500_MISO: IC26.16 (GPIO16); also elsewhere on the board
W5500_MOSI: IC26.19 (GPIO19); also elsewhere on the board
W5500_SCK: IC26.18 (GPIO18); also elsewhere on the board

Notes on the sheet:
USB-C CONNECTOR
MCU I2C0 BUS MAP (via TCA9548A @ 0x70): Port 0: - 2× STUSB4710 @ 0x28, 0x29 Port 1: - 2× STUSB4710 @ 0x28, 0x29 Port 2: - 2× STUSB4710 @ 0x28, 0x29 Port 3: - 2× STUSB4710 @ 0x28, 0x29 Port 4: - 4× INA219 @ 0x40, 0x41, 0x42, 0x43 Port 5: - 4× INA219 @ 0x40, 0x41, 0x42, 0x43 Port 6–7: - UNUSED MCU I2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
USER MEMORY
MICROCONTROLLER - GPIO
DEBUG CONNECTOR
TESTPOINTS


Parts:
ADVB: DNI; TP-ROUND
C28: 1nF 2kV; 1206
C29, C66, C69: 100nF 25V; 0201
C67, C68, C70: 4.7uF 25V; 0402
D13: HDMIULC6-4SC6Y; SOT23-6
DISP: AFC11-S20ICC-00; FPC20
ESD1: SP0503BAHTG; SOT143
IC38: TCA9548ARGER; QFN50P400X400X100-25T210N
R10: 1M 1%; 1206
R18, R19: 5.1K 1%; 0201
R20: 2.2K 1%; 0201
R21: 10K 1%; 0201
R30: 0R 1%; 0805
R31, R32: 10K 1%; 0402
R35, R215, R216, R217: 3.3K 1%; _0603X4-1206
TP2: DNI; TP-ROUND
USB9: USB-TYPE-C-018; USB-C

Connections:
!TCA_RST: IC38.24 (RESET); also elsewhere on the board
+3V3: C69.1, C70.1, D13.5, DISP.1, DISP.2, IC38.21 (VCC), R21.1, R35.A2 (8), R35.B2 (7), R35.C2 (6), R35.D2 (5), R215.A2 (8), R215.B2 (7), R215.C2 (6), R215.D2 (5), R216.A2 (8), R216.B2 (7), R216.C2 (6), R216.D2 (5), R217.A2 (8), R217.B2 (7), R217.C2 (6), R217.D2 (5); also elsewhere on the board
+5V: DISP.3, DISP.4
ADC_VUSB: ADVB.TP, C29.1, R31.2, R32.1; also elsewhere on the board
CC1: R19.1, USB9.A5 (CC1)
CC2: R18.1, USB9.B5 (CC2)
GND: C28.2, C29.2, C66.2, C67.2, C68.2, C69.2, C70.2, D13.2, DISP.5, DISP.8, DISP.Z0 (Z1), DISP.Z1, DISP.Z2, DISP.Z3, DISP.Z4 (Z3), DISP.Z5 (Z4), ESD1.1 (A), IC38.9 (GND), IC38.18 (A2), IC38.22 (A0), IC38.23 (A1), IC38.25 (GND), R10.2, R18.2, R19.2, R20.2, R32.2, USB9.GND, USB9.GND2 (GND); also elsewhere on the board
I2C0_SCL: IC38.19 (SCL); also elsewhere on the board
I2C0_SDA: IC38.20 (SDA); also elsewhere on the board
I2C1_SCL: DISP.7; also elsewhere on the board
I2C1_SDA: DISP.6; also elsewhere on the board
KEY_0: D13.6, DISP.12; also elsewhere on the board
KEY_1: D13.4, DISP.11; also elsewhere on the board
KEY_2: D13.3, DISP.10; also elsewhere on the board
KEY_3: D13.1, DISP.9; also elsewhere on the board
MCP_DSP_RST: DISP.20, R21.2
SHIELD: C28.1, R10.1, USB9.SHLD1 (SHILED), USB9.SHLD2 (SHILED), USB9.SHLD3 (SHILED), USB9.SHLD4 (SHILED); also elsewhere on the board
TCA0_I2C_SCL: IC38.2 (SC0), R215.C1 (3); also elsewhere on the board
TCA0_I2C_SDA: IC38.1 (SD0), R215.D1 (4); also elsewhere on the board
TCA1_I2C_SCL: IC38.4 (SC1), R215.A1 (1); also elsewhere on the board
TCA1_I2C_SDA: IC38.3 (SD1), R215.B1 (2); also elsewhere on the board
TCA2_I2C_SCL: IC38.6 (SC2), R216.C1 (3); also elsewhere on the board
TCA2_I2C_SDA: IC38.5 (SD2), R216.D1 (4); also elsewhere on the board
TCA3_I2C_SCL: IC38.8 (SC3), R216.A1 (1); also elsewhere on the board
TCA3_I2C_SDA: IC38.7 (SD3), R216.B1 (2); also elsewhere on the board
TCA4_I2C_SCL: IC38.11 (SC4), R217.C1 (3); also elsewhere on the board
TCA4_I2C_SDA: IC38.10 (SD4), R217.D1 (4); also elsewhere on the board
TCA5_I2C_SCL: IC38.13 (SC5), R217.A1 (1); also elsewhere on the board
TCA5_I2C_SDA: IC38.12 (SD5), R217.B1 (2); also elsewhere on the board
TCA6_I2C_SCL: IC38.15 (SC6), R35.C1 (3); also elsewhere on the board
TCA6_I2C_SDA: IC38.14 (SD6), R35.D1 (4); also elsewhere on the board
TCA7_I2C_SCL: IC38.17 (SC7), R35.A1 (1); also elsewhere on the board
TCA7_I2C_SDA: IC38.16 (SD7), R35.B1 (2); also elsewhere on the board
USB_RP_DP_N: ESD1.3 (C2), USB9.A7 (D-), USB9.B7 (D-); also elsewhere on the board
USB_RP_DP_P: ESD1.2 (C1), USB9.A6 (D+), USB9.B6 (D+); also elsewhere on the board
VBUS: C66.1, C67.1, C68.1, ESD1.4 (C3), R20.1, R30.1, R31.1, TP2.TP, USB9.VBUS1 (VBUS), USB9.VBUS2 (VBUS)
VUSB: R30.2

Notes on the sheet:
PERIPHERALS
USB-C CONNECTOR
8-Channel I2C Switch
ADDRESS: 0x70
IO DRIVER
BOARD CONNECTOR


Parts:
3V3A1: DNI; TP-ROUND
C95, C96, C97, C98, C121, C122, C123, C124, C125, C126, C127: 100nF 25V; 0201
C128, C129: 6.8nF 50V; 0201
C130: 22nF 50V; 0402
C131: 1nF 2kV; 1206
C132, C133: 18pF 50V; 0201
C134: 4.7uF 25V; 0402
ETH2: J1B1211CCD
IC17: W5500; LQFP48
L5: BLM18EG221TN1D; 0603
R125, R126: 0R 1%; 0201
R127, R128, R129, R130: 49.9R 1%; 0201
R131, R132, R133, R134: 3.3R 1%; 0201
R135, R226, R227: 4.7K 1%; 0201
R136: 12.4K 1%; 0201
R137: 1M 1%; 0201
R138, R139, R140: 470R 1%; 0402
R141: 1M 1%; 1206
X3: 25MHz; WE-XTAL_CFPX-180

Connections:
!ACT: IC17.27 (ACTLED), R138.1
!DUP: IC17.26 (DUPLED), R227.1; also elsewhere on the board
!LINK: IC17.25 (LINKLED), R139.1
!SPD: IC17.24 (SPDLED), R226.1; also elsewhere on the board
!W5500_CS: IC17.32 (!SCSN); also elsewhere on the board
!W5500_INT: IC17.36 (!INTN); also elsewhere on the board
!W5500_RST: IC17.37 (!RSTN), R135.2; also elsewhere on the board
+3V3: C97.1, C98.1, C121.1, ETH2.10 (GREEN+), ETH2.12 (YELLOW+), IC17.28 (VDD), IC17.43 (PMODE2), IC17.44 (PMODE1), IC17.45 (PMODE0), L5.1, R135.1, R226.2, R227.2; also elsewhere on the board
+3V3_A: 3V3A1.TP, C122.1, C123.1, C124.1, C125.1, C126.1, C127.1, IC17.4 (AVDD), IC17.8 (AVDD), IC17.11 (AVDD), IC17.15 (AVDD), IC17.17 (AVDD), IC17.21 (AVDD), L5.2, R129.1, R130.1, R140.1
GND: C95.2, C96.2, C97.2, C98.2, C121.2, C122.2, C123.2, C124.2, C125.2, C126.2, C127.2, C130.2, C131.2, C132.2, C133.2, C134.2, ETH2.8 (GND), IC17.3 (AGND), IC17.9 (AGND), IC17.14 (AGND), IC17.16 (AGND), IC17.19 (AGND), IC17.29 (GND), IC17.48 (AGND), R136.2, R141.1, X3.2 (GND), X3.4 (GND); also elsewhere on the board
unnamed: ETH2.11 (YELLOW-), R139.2
unnamed: ETH2.9 (GREEN-), R138.2
unnamed: IC17.10 (EXRES1), R136.1
unnamed: C96.1, IC17.22 (1V2O)
unnamed: C134.1, IC17.20 (TOCAP)
unnamed: C133.1, IC17.30 (XI), R137.2, X3.3 (2)
RCT: C95.1, ETH2.5 (P5/RCT), R127.2, R128.2
RDC_RD_N: C128.1, R128.1, R133.2
RDC_RD_P: C129.1, R127.1, R134.2
RD_N: C128.2, ETH2.6 (RD-)
RD_P: C129.2, ETH2.4 (RD+)
RX_RD_N: IC17.5 (RXN), R133.1
RX_RD_P: IC17.6 (RXP), R134.1
SHIELD: C131.1, ETH2.13 (SHIELD), ETH2.14 (SHIELD), R141.2; also elsewhere on the board
TCT: C130.1, ETH2.2 (P4/TCT), R140.2
TDR_N: R125.1, R130.2, R131.2
TDR_P: R126.1, R129.2, R132.2
TD_N: ETH2.3 (TD-), R125.2
TD_P: ETH2.1 (TD+), R126.2
TX_TD_N: IC17.1 (TXN), R131.1
TX_TD_P: IC17.2 (TXP), R132.1
W5500_MISO: IC17.34 (MISO); also elsewhere on the board
W5500_MOSI: IC17.35 (MOSI); also elsewhere on the board
W5500_SCK: IC17.33 (SCLK); also elsewhere on the board
XO1: C132.1, IC17.31 (XO), R137.1, X3.1

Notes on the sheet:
W5500 ETHERNET CONTROLLER
ETHERNET CONTROLLER
RJ45-CAT5
DECOUPLING

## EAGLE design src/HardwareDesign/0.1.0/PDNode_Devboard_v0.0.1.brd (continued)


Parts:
3VFB, 5VFB, 24VGND: DNI; TP-ROUND
+3V, +5VA, +24V: DNI; TP-ROUND
C30, C32, C35, C37, C38, C71: 100nF 25V; 0201
C31, C33, C34, C72, C73, C74: 22uF 25V; 1206
C36, C75: 33pF 50V; 0201
C84, C85: 1nF 25V; 0201
C252, C253, C256, C257: 330uF 50V; 10X10.5(DXL)
D9, D11: SMBJ33A; SMB
F1: 2A; FUSE_3544-2
F2: DNI; FUSE_3544-2
F3: 15A; FUSE_3544-2
IC2, IC40: MP2315GJ-Z; SOT65P280X110-8N
J8: 691244510006
L3, L11: 4.7uH 3.5A; SRR5228A
R22: 33K 1%; 0201
R23, R39: 40.2K 1%; 0201
R33: 12.7K 1%; 0201
R34, R41: 10R 1%; 0201
R36, R43: 75K 1%; 0201
R37, R44, R70, R72, R74: 100K 1%; 0201
R38, R45, R71, R73, R75: 10K 1%; 0201
R40: 7.5K 1%; 0201

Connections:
3V3_EN_SYS1: IC40.6 (EN), R37.2
3V3_EN_SYS2: IC2.6 (EN), R44.2
24VINA: F3.1_1 (1), F3.1_2 (1), J8.3
24VINC: F1.1_1 (1), F1.1_2 (1), J8.1
+3V3: +3V.TP, C31.1, C33.1, C36.1, L11.2, R23.1; also elsewhere on the board
+5VA: +5VA.TP, C72.1, C73.1, C75.1, L3.2, R39.1; also elsewhere on the board
+24V_A: C256.1 (+), C257.1 (+), D11.C, F3.2_1 (2), F3.2_2 (2), R70.1; also elsewhere on the board
+24V_B: F2.2_1 (2), F2.2_2 (2), R72.1
+24V_C: +24V.TP, C34.1, C35.1, C71.1, C74.1, C252.1 (+), C253.1 (+), D9.C, F1.2_1 (2), F1.2_2 (2), IC2.2 (IN), IC40.2 (IN), R37.1, R44.1, R74.1
ADC_24VA: R70.2, R71.1; also elsewhere on the board
ADC_24VB: R72.2, R73.1; also elsewhere on the board
ADC_24VC: R74.2, R75.1; also elsewhere on the board
GND: 24VGND.TP, C31.2, C32.2, C33.2, C34.2, C35.2, C38.2, C71.2, C72.2, C73.2, C74.2, C84.2, C85.2, C252.2 (-), C253.2 (-), C256.2 (-), C257.2 (-), D9.A, D11.A, IC2.4 (GND), IC40.4 (GND), J8.4, J8.5, J8.6, R33.2, R36.2, R40.2, R43.2, R71.2, R73.2, R75.2; also elsewhere on the board
unnamed: IC2.5 (BST), R41.1
unnamed: IC2.8 (FB), R38.1
unnamed: C37.1, R41.2
unnamed: 5VFB.TP, C75.2, R39.2, R40.1, R45.2
unnamed: C38.1, IC2.7 (VCC)
unnamed: C85.1, IC2.1 (AAM), R43.1
unnamed: R38.2, R45.1
unnamed: F2.1_1 (1), F2.1_2 (1), J8.2
unnamed: IC40.5 (BST), R34.1
unnamed: IC40.8 (FB), R22.1
unnamed: C30.1, R34.2
unnamed: 3VFB.TP, C36.2, R22.2, R23.2, R33.1
unnamed: C32.1, IC40.7 (VCC)
unnamed: C84.1, IC40.1 (AAM), R36.1
SW1: C37.2, IC2.3 (SW), L3.1
SW3: C30.2, IC40.3 (SW), L11.1

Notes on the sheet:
VOUT (V)
EXT 24VDC INPUT
FUSE BLOCK
LOAD COVERED
MAX CURRENT @24V
FUSE
4x USB-C (TPS552882)
4x USB-A (MP2315S) + 3.3V System
~11.1 A
~1.5 A
15 A slow-blow blade
2 A slow-blow blade
RFB1 (kΩ)
RFB2 (kΩ)
RT (kΩ)
1.05
1.2
1.8
3.3
5.0
20.5
40.2
62.0
39.2
31.6
18.7
12.7
7.5
2.5
100.0
75.0
59.0
33.0
20.0
3.3V DC-DC CONVERTER
Vin = 4.5-24V
5V DC-DC CONVERTER
ETHERNET CONTROLLER


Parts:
C2, C17, C18, C76: 100nF 25V; 0201
C3, C4, C77, C78: 10uF 16V; 0603
C5, C79: 100uF 16V; 5X5.5(DXL)
C11: 1nF 2kV; 1206
D1, D3: Green; LED-0603
D2, D4: Red; LED-0603
H1, H2, H3, H4: MOUNT-PAD-ROUND3.3; 3,3-PAD
IC1, IC8: AP22653W6; SOT23-6
IC4, IC5: SN74LVC1G04DBVR; SOT95P280X145-5N
R1, R3, R4, R13, R16, R56, R66, R67: 10K 1%; 0201
R2: 1M 1%; 1206
R12, R14, R15, R17: 1K 1%; 0402
USBA_1-2: 61400826021
USBA_VB1, USBA_VB2: DNI; TP-ROUND

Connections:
+3V3: C18.1, C76.1, D1.A, D3.A, IC4.5 (V+), IC5.5 (V+), R4.1, R13.1; also elsewhere on the board
+5VA: C2.1, C17.1, IC1.1 (IN), IC8.1 (IN); also elsewhere on the board
GND: C2.2, C3.2, C4.2, C5.2 (-), C11.2, C17.2, C18.2, C76.2, C77.2, C78.2, C79.2 (-), D2.C, D4.C, IC1.2 (GND), IC4.3 (V-), IC5.3 (V-), IC8.2 (GND), R1.2, R2.1, R3.2, R56.2, R67.2, USBA_1-2.4 (GND), USBA_1-2.8 (GND); also elsewhere on the board
unnamed: IC1.5 (ILIM), R66.1
unnamed: D2.A, R12.2
unnamed: IC4.4 (OUT), R12.1, R14.1
unnamed: D1.C, R14.2
unnamed: D4.A, R15.1
unnamed: IC5.4 (OUT), R15.2, R17.1
unnamed: D3.C, R17.2
unnamed: R16.2, R56.1
unnamed: R66.2, R67.1
unnamed: IC8.5 (ILIM), R16.1
OCP1: IC4.2 (IN), IC8.4 (!FAULT), R4.2; also elsewhere on the board
OCP2: IC1.4 (!FAULT), IC5.2 (IN), R13.2; also elsewhere on the board
SHIELD: C11.1, H1.B3,3, H2.B3,3, H3.B3,3, H4.B3,3, R2.2, USBA_1-2.S1 (SHIELD), USBA_1-2.S2 (SHIELD), USBA_1-2.S3 (SHIELD), USBA_1-2.S4 (SHIELD); also elsewhere on the board
USBA1_EN: IC8.3 (EN), R1.1; also elsewhere on the board
USBA2_EN: IC1.3 (EN), R3.1; also elsewhere on the board
VBUS_USBA1: C3.1, C4.1, C5.1 (+), IC8.6 (OUT), USBA_1-2.1 (VBUS), USBA_VB1.TP
VBUS_USBA2: C77.1, C78.1, C79.1 (+), IC1.6 (OUT), USBA_1-2.5 (VBUS), USBA_VB2.TP

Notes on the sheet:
OUTPUT USB-A1
RLIM = 20kΩ = 1.2A
OUTPUT USB-A2
FAULT INDICATORS
USB-A SOURCE PORT1-2
OCP
RED
GREEN
OVC
FAULT


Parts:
C6, C16, C39, C47, C51, C80: 1uF 50V; 0402
C40: 1nF 2kV; 1206
C41: 4.7uF 25V; 0402
C42, C44: 10nF 50V; 0201
C43: 100pF 50V; 0201
C45, C46, C81: 100nF 50V; 0402
C48, C49, C52, C53, C54, C82: 10uF 50V; 0805
C50: 100uF 50V; 6.3X7.7(DXL)
C55: 100nF 25V; 0201
C83: 330uF 50V; 10X10.5(DXL)
C215, C216: 2.2nF 50V; 0402
CC1, CC2: DNI; TP-ROUND
CPDO1, CPDO2: DNI; TP-ROUND
IC9: STUSB4710AQ1TR; QFN50P300X300X55-16N
IC12: TPS552882; RPM0026A-MFG
IC13: INA219BIDCNT; SOT23-8
L2: 4.7uH 11.3A; WE-PDHV_1280
PDO2, PDO3, PDO4, PDO5: DNI; TP-ROUND
PDOFB: DNI; TP-ROUND
PORT1: 632722100213
R5: 200K 1%; 0201
R11: 12.7K 1%; 0201
R46, R47: 4.64K 1%; 0201
R48: 8.87K 1%; 0201
R49: 30.9K 1%; 0201
R50: 1M 1%; 1206
R51: 100K 1%; 0201
R52, R53, R54, R55: 10K 1%; 0402
R57, R63: 0.010R 1%; 2512
R58, R228, R229: 0R 1%; 0201
R59: 49.9K 1%; 0201
R60, R68, R69: 10K 1%; 0201
R61: 150K; R0201
R62: 15K 1%; 0201
R64, R65: 1R 1%; 0402
R231, R232: 1R 1%; 0603
T6, T7, T8: DMP3013SFV; POWERDI3333-8_UX_DIO-L
T9, T10: BSZ065N06; POWERDI3333-8_UX_DIO-L
VOP1: DNI; TP-ROUND
VREL1: DNI; TP-ROUND
VSRC1: DNI; TP-ROUND
VTPS1, VTPS2: DNI; TP-ROUND

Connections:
+3V3: C55.1, IC13.4 (VCC); also elsewhere on the board
+24V_A: C47.1, C48.1, C49.1, C50.1 (+), C80.1, IC12.3 (VIN), T10.5 (D), T10.6 (D), T10.7 (D), T10.8 (D), T10.9 (D); also elsewhere on the board
CC1_PORT1: CC1.TP, IC9.2 (CC1), PORT1.A5 (CC1)
CC2_PORT1: CC2.TP, IC9.3 (CC2), PORT1.B5 (CC2)
DISCHARGE1: R52.1, T6.5 (D), T6.6 (D), T6.7 (D), T6.8 (D), T6.9 (D)
EN_PORT1: IC12.4 (EN), R69.1; also elsewhere on the board
GND: C6.2, C16.2, C39.2, C40.1, C41.2, C42.2, C43.2, C44.2, C47.2, C48.2, C49.2, C50.2 (-), C51.1, C52.1, C53.1, C54.1, C55.2, C80.2, C82.1, C83.2 (-), C215.2, C216.2, IC9.6 (GND), IC12.9 (PGND), IC12.10 (AGND), IC12.24 (PGND), IC13.3 (GND), IC13.7 (A0), IC13.8 (A1), PORT1.A12 (GND1), PORT1.B12 (GND2), R49.2, R50.1, R51.2, R52.2, R58.2, R59.2, R61.2, R68.2, R69.2, T9.1 (S), T9.2 (S), T9.3 (S); also elsewhere on the board
IN1_PORT1: CPDO1.TP, IC9.12 (VBUS_SENSE), IC13.1 (IN+), R57.2, T8.5 (D), T8.6 (D), T8.7 (D), T8.8 (D), T8.9 (D)
IN2_PORT1: CPDO2.TP, IC13.2 (IN-), PORT1.A9 (VBUS1), PORT1.B9 (VBUS2), R57.1
IND1: C45.1, IC12.23 (SW1), L2.1, R231.1, T9.5 (D), T9.6 (D), T9.7 (D), T9.8 (D), T9.9 (D), T10.1 (S), T10.2 (S), T10.3 (S), VTPS1.TP
INDOUT1: C46.1, IC12.21 (SW2), IC12.25 (SW2), L2.2, R232.1, VTPS2.TP
unnamed: R60.2, R68.1
unnamed: IC12.14 (FB), PDOFB.TP, R5.2, R11.1
unnamed: C215.1, R231.2
unnamed: C216.1, R232.2
unnamed: IC9.11 (SEL_PDO5), PDO5.TP, R11.2, R46.1
unnamed: IC9.10 (SEL_PDO4), PDO4.TP, R46.2, R47.1
unnamed: IC9.7 (SEL_PDO3), PDO3.TP, R47.2, R48.1
unnamed: IC9.8 (SEL_PDO2), PDO2.TP, R48.2, R49.1
unnamed: C6.1, IC9.15 (VREG1V2)
unnamed: C16.1, IC9.16 (VREG2V7)
unnamed: IC9.9 (ADDR0), R51.1
unnamed: IC9.13 (VBUS_DISCH), R55.2, T6.4 (G)
unnamed: R53.2, R54.1, T7.4 (G), T8.4 (G)
unnamed: IC9.14 (VBUS_EN_SRC), R54.2
unnamed: C44.1, R62.2
unnamed: IC12.8 (FSW), R59.1
unnamed: C42.1, IC12.7 (DITH_SYNC)
unnamed: IC12.15 (MODE), R58.1
unnamed: IC12.17 (ILIM), R60.1
unnamed: IC12.16 (CDC), R61.1
unnamed: C43.1, IC12.18 (COMP), R62.1
unnamed: C41.1, IC12.19 (VCC)
unnamed: C45.2, IC12.22 (BOOT1)
unnamed: C46.2, IC12.20 (BOOT2)
unnamed: R65.1, T10.4 (G)
unnamed: R64.1, T9.4 (G)
unnamed: IC12.1 (DR1L), R64.2
unnamed: IC12.2 (DR1H), R65.2
P1_IS_N: C81.2, IC12.13 (ISN), R229.1
P1_IS_P: C81.1, IC12.12 (ISP), R228.1
SHIELD: C40.2, PORT1.S1 (SHIELD1), PORT1.S2 (SHIELD1), PORT1.S3 (SHIELD1), PORT1.S4 (SHIELD1), R50.2; also elsewhere on the board
SOURCE1: R53.1, T7.1 (S), T7.2 (S), T7.3 (S), T8.1 (S), T8.2 (S), T8.3 (S), VREL1.TP
TCA0_I2C_SCL: IC9.4 (SCL); also elsewhere on the board
TCA0_I2C_SDA: IC9.5 (SDA); also elsewhere on the board
TCA4_I2C_SCL: IC13.5 (SCL); also elsewhere on the board
TCA4_I2C_SDA: IC13.6 (SDA); also elsewhere on the board
VOUT_PORT1: C51.2, C52.2, C53.2, C54.2, C82.2, C83.1 (+), IC12.11 (VOUT), IC12.26 (VOUT), R63.2, R228.2, VOP1.TP
VSRC1: C39.1, IC9.1 (VDD), R5.1, R55.1, R63.1, R229.2, T6.1 (S), T6.2 (S), T6.3 (S), T7.5 (D), T7.6 (D), T7.7 (D), T7.8 (D), T7.9 (D), VSRC1.TP

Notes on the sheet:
USB-C PD SOURCE PORT1
CURRENT MEASUREMENT
Output voltage: 5 V to 20 V Output current limit: 5 A
PD Ladder - TPS552882 (VREF = 1.20V, Rtop = 200kΩ) R25 = 12.7k → VOUT ≈ 20.10V R26 = 4.64k → VOUT ≈ 15.04V R27 = 4.64k → VOUT ≈ 12.12V R28 = 8.87k → VOUT ≈ 8.98V R29 = 30.9k → VOUT ≈ 5.09V Cumulative Rbottom = 61.75kΩ
Address: 0x40
Address: 0x28
USB-C PD SOURCE PORT 1
PDNODE-600



Board: 6 copper layers, 94.0 x 100.0 mm, 311 parts (23 on the bottom side), 177 nets.

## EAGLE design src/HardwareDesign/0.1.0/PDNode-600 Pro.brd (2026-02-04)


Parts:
AVDD: TESTPOINT; TP
C21, C22, C26: 4.7uF 10V; 0402
C23, C24, C25, C27, C176, C180, C181, C182, C184, C185, C186, C187, C188, C189, C190, C191, C192, C193, C194, C195: 100nF 25V; 0201
C177, C178: 15pF 50V; 0201
C179: 1uF 10V; 0201
IC26: RP2354B; QFN80-10X10
IC27: W25Q128JVPIQ; SON127P600X500X75-8N
IC28: MCP6001RT-I/OT; SOT23-5
L1: 3.3uH; 0805
R24: 10K 1%; 0201
R25, R26: 27R 1%; 0201
R27: 33R 1%; 0402
R28, R29: 0R 1%; 0402
R209: DNI; R0201
R210, R211: 1K 1%; 0201
R212: 4.7K 1%; 0201
REF1: LM4040x30; SOT23
SW1, SW2: B3U-1000P
VREF: TESTPOINT; TP
X1: 12MHz; WE-XTAL_CFPX-180

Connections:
!QSPI_SS: IC26.75 (QSPI_SS), IC27.1 (!CS), R209.1, R210.2
+1V1: C26.1, C27.1, C192.1, C193.1, C194.1, IC26.10 (DVDD1), IC26.32 (DVDD2), IC26.51 (DVDD3), IC26.65 (VREG_FB), IC26.68 (USB_OTP_VDD), IC26.69 (QSPI_IOVDD), L1.2
+3V3: C22.1, C23.1, C24.1, C25.1, C176.1, C182.1, C184.1, C185.1, C186.1, C187.1, C188.1, C189.1, C190.1, C195.1, IC26.5 (IOVDD1), IC26.15 (IOVDD2), IC26.24 (IOVDD3), IC26.29 (IOVDD4), IC26.41 (IOVDD5), IC26.50 (IOVDD6), IC26.60 (IOVDD7), IC26.64 (VREG_IN), IC26.76 (IOVDD8), IC27.8 (VCC), IC28.2 (V+), R24.1, R27.1, R29.1, R209.2, R212.2; also elsewhere on the board
AVDD: AVDD.TP, C181.1, IC28.1 (OUT), IC28.4 (-IN), R28.2
GND: C21.2, C22.2, C23.2, C24.2, C25.2, C26.2, C27.2, C176.2, C177.2, C178.2, C179.2, C180.2, C181.2, C182.2, C184.2, C185.2, C186.2, C187.2, C188.2, C189.2, C190.2, C191.2, C192.2, C193.2, C194.2, C195.2, IC26.62 (VREG_PGND), IC26.81 (GND), IC27.4 (GND), IC27.PAD (GND), IC28.5 (V-), REF1.2 (A), REF1.3 (A), SW1.1, SW2.2, X1.2 (GND), X1.4 (GND); also elsewhere on the board
unnamed: IC26.35 (RUN), R24.2, SW1.2
unnamed: IC26.66 (USB_DM), R25.2
unnamed: IC26.67 (USB_DP), R26.2
unnamed: C191.1, IC26.59 (ADC_AVDD), R28.1, R29.2
unnamed: C21.1, IC26.61 (VREG_AVDD), R27.2
unnamed: IC26.63 (VREG_LX), L1.1
unnamed: C178.1, R211.1, X1.3 (2)
QSPI_SCLK: IC26.71 (QSPI_SCLK), IC27.6 (CLK)
QSPI_SD0: IC26.72 (QSPI_SD0), IC27.5 (DI/IO0)
QSPI_SD1: IC26.74 (QSPI_SD1), IC27.2 (DO/IO1)
QSPI_SD2: IC26.73 (QSPI_SD2), IC27.3 (!WP!/IO2)
QSPI_SD3: IC26.70 (QSPI_SD3), IC27.7 (!HOLD!/IO3)
RP_XI: C177.1, IC26.30 (XIN), X1.1
RP_XO: IC26.31 (XOUT), R211.2
SWCLK: IC26.33 (SWCLK)
SWDIO: IC26.34 (SWDIO)
USB_BOOT: R210.1, SW2.1
USB_RP_DP_N: R25.1
USB_RP_DP_P: R26.1
VREF: C179.1, C180.1, IC28.3 (+IN), R212.1, REF1.1 (C), VREF.TP

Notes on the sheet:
RP2040 MCU
RP2040 FLASH
ADC VREF
MICROCONTROLLER - POWER

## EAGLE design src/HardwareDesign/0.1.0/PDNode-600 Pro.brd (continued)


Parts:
C183: 100nF 25V; 0201
D12: HDMIULC6-4SC6Y; SOT23-6
IC26: RP2354B; QFN80-10X10
IC29: CAT24C256HU4IGT3; SON50P300X200X50-9T130X140N
R207: 3.3K 1%; _0603X4-1206
R213: NC; R0201
R214: 4.7K 1%; 0201

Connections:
!W5500_CS: IC26.17 (GPIO17); also elsewhere on the board
!W5500_INT: IC26.21 (GPIO21); also elsewhere on the board
!W5500_RST: IC26.20 (GPIO20); also elsewhere on the board
+3V3: C183.1, D12.5, IC29.8 (VCC), R207.A2 (8), R207.B2 (7), R207.C2 (6), R207.D2 (5), R213.2; also elsewhere on the board
GND: C183.2, D12.2, IC29.2 (A1), IC29.3 (A2), IC29.4 (GND), IC29.7 (WP), IC29.9 (GND), R214.1; also elsewhere on the board
I2C0_SCL: D12.3, IC26.2 (GPIO5), R207.A1 (1); also elsewhere on the board
I2C0_SDA: D12.1, IC26.1 (GPIO4), R207.B1 (2); also elsewhere on the board
I2C1_SCL: D12.6, IC26.4 (GPIO7), IC29.6 (SCL), R207.C1 (3); also elsewhere on the board
I2C1_SDA: D12.4, IC26.3 (GPIO6), IC29.5 (SDA), R207.D1 (4); also elsewhere on the board
KEY_0: IC26.25 (GPIO24); also elsewhere on the board
KEY_1: IC26.26 (GPIO25); also elsewhere on the board
KEY_2: IC26.27 (GPIO26); also elsewhere on the board
KEY_3: IC26.28 (GPIO27); also elsewhere on the board
unnamed: IC29.1 (A0), R213.1, R214.2
QMI_CS1: IC26.6 (GPIO8)
SPI1_CS: IC26.12 (GPIO13)
SPI1_MISO: IC26.11 (GPIO12)
SPI1_MOSI: IC26.14 (GPIO15)
SPI1_SCLK: IC26.13 (GPIO14)
UART0_RX: IC26.78 (GPIO1)
UART0_TX: IC26.77 (GPIO0)
W5500_MISO: IC26.16 (GPIO16); also elsewhere on the board
W5500_MOSI: IC26.19 (GPIO19); also elsewhere on the board
W5500_SCK: IC26.18 (GPIO18); also elsewhere on the board

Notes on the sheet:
USB-C CONNECTOR
NETWORK SPI
PUSHBUTTONS
MCU I2C0 BUS MAP (via TCA9548A @ 0x70): Port 0: - 2× STUSB4710 @ 0x28, 0x29 Port 1: - 2× STUSB4710 @ 0x28, 0x29 Port 2: - 2× STUSB4710 @ 0x28, 0x29 Port 3: - 2× STUSB4710 @ 0x28, 0x29 Port 4: - 4× INA219 @ 0x40, 0x41, 0x42, 0x43 Port 5: - 4× INA219 @ 0x40, 0x41, 0x42, 0x43 Port 6–7: - UNUSED MCU I2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
USER MEMORY
MICROCONTROLLER - GPIO


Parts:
C28: 1NF-2KV; 1206
C29, C248: 100nF 25V; 0402
C212, C249: 100nF 25V; 0201
C213, C251: 1uF 10V; 0201
C247: 10uF 16V; 0603
D13: HDMIULC6-4SC6Y; SOT23-6
DISP: AFC11-S20ICC-00; FPC20
ESD1: SP0503BAHTG; SOT143
IC38: TCA9548ARGER; QFN50P400X400X100-25T210N
IC42: MCP23017T-E/ML; QFN28[6X6]ML
R30: 0R 1%; 0805
R31, R32, R252: 10K 1%; 0201
R215, R216, R217: 3.3K 1%; _0603X4-1206
R249: 2.2K 1%; 0201
R250, R251: 5.1K 1%; 0201
R255: 1M 1%; 0603
USB9: USB-TYPE-C-018; USB-C

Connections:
!TCA_RST: IC38.24 (RESET)
+3V3: C212.1, C213.1, C249.1, C251.1, D13.5, DISP.1, DISP.2, IC38.21 (VCC), IC42.5 (VDD), R215.A2 (8), R215.B2 (7), R215.C2 (6), R215.D2 (5), R216.A2 (8), R216.B2 (7), R216.C2 (6), R216.D2 (5), R217.A2 (8), R217.B2 (7), R217.C2 (6), R217.D2 (5), R252.2; also elsewhere on the board
+5V: DISP.3, DISP.4
ADC_VUSB: C29.1, R31.2, R32.1
AGND: C28.1, R255.1, USB9.SHLD1 (SHILED), USB9.SHLD2 (SHILED), USB9.SHLD3 (SHILED), USB9.SHLD4 (SHILED); also elsewhere on the board
CC1: R251.1, USB9.A5 (CC1)
CC2: R250.1, USB9.B5 (CC2)
EN_PORT1: IC42.25 (IO2.0); also elsewhere on the board
EN_PORT2: IC42.26 (IO2.1)
EN_PORT3: IC42.27 (IO2.2)
EN_PORT4: IC42.28 (IO2.3)
EN_PORT5: IC42.1 (IO2.4)
EN_PORT6: IC42.2 (IO2.5)
EN_PORT7: IC42.3 (IO2.6)
EN_PORT8: IC42.4 (IO2.7)
GND: C28.2, C29.2, C212.2, C213.2, C247.2, C248.2, C249.2, C251.2, D13.2, DISP.5, DISP.8, DISP.Z0 (Z1), DISP.Z1, DISP.Z2, DISP.Z3, DISP.Z4 (Z3), DISP.Z5 (Z4), ESD1.1 (A), IC38.9 (GND), IC38.18 (A2), IC38.22 (A0), IC38.23 (A1), IC38.25 (GND), IC42.6 (VSS), IC42.11 (A0), IC42.12 (A1), IC42.13 (A2), IC42.PAD (VSS), R32.2, R249.2, R250.2, R251.2, R255.2, USB9.GND, USB9.GND2 (GND); also elsewhere on the board
I2C0_SCL: IC38.19 (SCL); also elsewhere on the board
I2C0_SDA: IC38.20 (SDA); also elsewhere on the board
I2C1_SCL: DISP.7, IC42.8 (SCL); also elsewhere on the board
I2C1_SDA: DISP.6, IC42.9 (SDA); also elsewhere on the board
KEY_0: D13.6, DISP.12; also elsewhere on the board
KEY_1: D13.4, DISP.11; also elsewhere on the board
KEY_2: D13.3, DISP.10; also elsewhere on the board
KEY_3: D13.1, DISP.9; also elsewhere on the board
LCD_BL: DISP.13
LCD_RES: DISP.14
MCP_DSP_RST: DISP.20, R252.1
MCP_REL_RST: IC42.14 (!RESET)
OCP1: IC42.21 (IO1.4); also elsewhere on the board
OCP2: IC42.22 (IO1.5); also elsewhere on the board
OCP3: IC42.23 (IO1.6); also elsewhere on the board
OCP4: IC42.24 (IO1.7); also elsewhere on the board
TCA0_I2C_SCL: IC38.2 (SC0), R215.C1 (3); also elsewhere on the board
TCA0_I2C_SDA: IC38.1 (SD0), R215.D1 (4); also elsewhere on the board
TCA1_I2C_SCL: IC38.4 (SC1), R215.A1 (1)
TCA1_I2C_SDA: IC38.3 (SD1), R215.B1 (2)
TCA2_I2C_SCL: IC38.6 (SC2), R216.C1 (3)
TCA2_I2C_SDA: IC38.5 (SD2), R216.D1 (4)
TCA3_I2C_SCL: IC38.8 (SC3), R216.A1 (1)
TCA3_I2C_SDA: IC38.7 (SD3), R216.B1 (2)
TCA4_I2C_SCL: IC38.11 (SC4), R217.C1 (3); also elsewhere on the board
TCA4_I2C_SDA: IC38.10 (SD4), R217.D1 (4); also elsewhere on the board
TCA5_I2C_SCL: IC38.13 (SC5), R217.A1 (1)
TCA5_I2C_SDA: IC38.12 (SD5), R217.B1 (2)
TCA6_I2C_SCL: IC38.15 (SC6)
TCA6_I2C_SDA: IC38.14 (SD6)
TCA7_I2C_SCL: IC38.17 (SC7)
TCA7_I2C_SDA: IC38.16 (SD7)
USBA1_EN: IC42.17 (IO1.0); also elsewhere on the board
USBA2_EN: IC42.18 (IO1.1); also elsewhere on the board
USBA3_EN: IC42.19 (IO1.2); also elsewhere on the board
USBA4_EN: IC42.20 (IO1.3); also elsewhere on the board
USB_DP_N: ESD1.3 (C2), USB9.A7 (D-), USB9.B7 (D-)
USB_DP_P: ESD1.2 (C1), USB9.A6 (D+), USB9.B6 (D+)
VBUS: C247.1, C248.1, ESD1.4 (C3), R30.1, R31.1, R249.1, USB9.VBUS1 (VBUS), USB9.VBUS2 (VBUS)
VUSB: R30.2

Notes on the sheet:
PERIPHERALS
USB-C CONNECTOR
8-Channel I2C Switch
ADDRESS: 0x70
IO DRIVER
USB-A OUTPUTS
USB-C OUTPUTS
BOARD CONNECTOR


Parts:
C30: 22nF 50V; 0402
C31: C1206C102KGRACTM; C1206
C32: 100nF 25V; 0402
C33, C34: 6.8nF 50V; 0201
C35, C221, C222, C223, C224, C225, C226, C227, C228, C229: 100nF 25V; 0201
C36: 4.7uF 25V; 0402
C37, C38: 18pF 50V; 0201
ETH1: J1B1211CCD
IC31: W5500; LQFP48
L10: BLM18EG221TN1D; 0603
R33, R34, R35: 470R 1%; 0402
R36: 1M 1%; 1206
R37, R38, R39, R40: 3.3R 1%; 0201
R41, R42, R43, R44: 49.9R 1%; 0201
R45: 12.4K 1%; R0201
R205: 1M 1%; 0201
R206, R208, R225, R226, R227: 4.7K 1%; 0201
X2: 25MHz; WE-XTAL_CFPX-180
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

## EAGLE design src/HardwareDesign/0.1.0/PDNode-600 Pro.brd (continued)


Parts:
C1: 1NF-2KV; 1206
C7, C12, C19, C20: 100nF 25V; 0201
C8, C9, C13, C14: 10uF 16V; 0603
C10, C15: 100uF 16V; 5X5.5(DXL)
D5, D7: GREEN; LEDC1608X35N_FLAT-G
D6, D8: RED; LEDC1608X35N_FLAT-R
IC2, IC3: AP22653W6; SOT23-6
IC6, IC7: SN74LVC1G04DBVR; SOT95P280X145-5N
R6, R9: 20K 1%; 0201
R7, R10, R19, R22: 10K 1%; 0402
R8: 1M 1%; 1206
R18, R20, R21, R23: 1K 1%; 0402
USBA_3-4: 61400826021
VUSBA3, VUSBA4: TPB1,27; B1,27

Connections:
+3V3: C19.1, C20.1, D5.A, D7.A, IC6.5 (V+), IC7.5 (V+), R7.1, R10.1, R19.2, R22.2; also elsewhere on the board
+5VB: C7.1, C12.1, IC2.1 (IN), IC3.1 (IN); also elsewhere on the board
AGND: C1.1, R8.2, USBA_3-4.S1 (SHIELD), USBA_3-4.S2 (SHIELD), USBA_3-4.S3 (SHIELD), USBA_3-4.S4 (SHIELD); also elsewhere on the board
GND: C1.2, C7.2, C8.2, C9.2, C10.2 (-), C12.2, C13.2, C14.2, C15.2 (-), C19.2, C20.2, D6.C, D8.C, IC2.2 (GND), IC3.2 (GND), IC6.3 (V-), IC7.3 (V-), R6.2, R8.1, R9.2, USBA_3-4.4 (GND), USBA_3-4.8 (GND); also elsewhere on the board
unnamed: IC2.5 (ILIM), R6.1
unnamed: IC3.5 (ILIM), R9.1
unnamed: D6.A, R18.1
unnamed: IC6.4 (OUT), R18.2, R20.1
unnamed: D5.C, R20.2
unnamed: D8.A, R21.1
unnamed: IC7.4 (OUT), R21.2, R23.1
unnamed: D7.C, R23.2
OCP3: IC2.4 (!FAULT), IC6.2 (IN), R19.1; also elsewhere on the board
OCP4: IC3.4 (!FAULT), IC7.2 (IN), R22.1; also elsewhere on the board
USBA3_EN: IC2.3 (EN), R7.2; also elsewhere on the board
USBA4_EN: IC3.3 (EN), R10.2; also elsewhere on the board
VBUS_USBA3: C8.1, C9.1, C10.1 (+), IC2.6 (OUT), USBA_3-4.1 (VBUS), VUSBA3.TP
VBUS_USBA4: C13.1, C14.1, C15.1 (+), IC3.6 (OUT), USBA_3-4.5 (VBUS), VUSBA4.TP
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

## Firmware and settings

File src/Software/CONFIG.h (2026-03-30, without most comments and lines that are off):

#define CONFIG_H
#include <stdarg.h>
#include <stdbool.h>
#include <stdint.h>
#include <stdio.h>
#include <stdlib.h>
#include <string.h>
#include "hardware/adc.h"
#include "hardware/clocks.h"
#include "hardware/gpio.h"
#include "hardware/i2c.h"
#include "hardware/pwm.h"
#include "hardware/resets.h"
#include "hardware/spi.h"
#include "hardware/timer.h"
#include "hardware/watchdog.h"
#include "pico/stdlib.h"
#include "pico/time.h"
#include "pico/unique_id.h"
#include "FreeRTOS.h"
#include "event_groups.h"
#include "queue.h"
#include "semphr.h"
#include "task.h"
#include "timers.h"
#define HARDWARE_VERSION "1.0.0"
#define HARDWARE_VERSION_LITERAL 100
#define FIRMWARE_VERSION "1.0.0"
#define FIRMWARE_VERSION_LITERAL 100
#define PIN_ETH_MISO 28
#define PIN_ETH_CS 29
#define PIN_ETH_SCK 30
#define PIN_ETH_MOSI 31
#define PIN_I2C0_SDA 32
#define PIN_I2C0_SCL 33
#define PIN_ETH_RST 34
#define PIN_ETH_INT 35
#define PIN_HEARTBEAT 36
#define PIN_ADC_VUSB 46
#define PIN_ADC_VREF 47
#define PD_IRQ_EVENT_A2 0
#define PD_IRQ_EVENT_B2 1
#define PIN_I2C1_SDA 2
#define PIN_I2C1_SCL 3
#define SPI_MISO 4
#define SPI_CS 5
#define SPI_CLK 6
#define SPI_MOSI 7
#define SPI_CS_PORT7 8
#define SPI_CS_PORT6 9
#define SPI_CS_PORT5 10
#define SPI_CS_PORT4 11
#define SPI_CS_PORT3 12
#define SPI_CS_PORT2 13
#define SPI_CS_PORT1 14
#define SPI_CS_PORT0 15
#define PIN_5V_BUCK_EN 16
#define PGOOD_SYSPMIC 17
#define PAC_ALERT_P23 19
#define PAC_ALERT_P01 20
#define PIN_MUX_S3 21
#define PIN_MUX_S2 22
#define PIN_MUX_S1 23
#define PIN_MUX_S0 24
#define PIN_MCP23017_RST 25
#define PD_IRQ_EVENT_A 26
#define PD_IRQ_EVENT_B 27
#ifdef PIN_GPIO37
#error "GPIO37 is not connected on BladeCore-M54E"
#endif
#ifdef PIN_GPIO38
#error "GPIO38 is not connected on BladeCore-M54E"
#endif
#ifdef PIN_GPIO39
#error "GPIO39 is not connected on BladeCore-M54E"
#endif
#define PIN_ADC_24V 40
#define PIN_ADC_5V_SWITCHING 41
#define PIN_ADC_5V_LDO 42
#define PIN_ADC_3V3_SWITCHING 43
#define PIN_ADC_3V3_LDO 44
#define PIN_MUX_OUTPUT 45
#define ETH_SPI_INSTANCE spi1
#define ETH_SPI_BAUDRATE (10 * 1000 * 1000)
#define EEPROM_I2C_INSTANCE i2c0
#define EEPROM_I2C_ADDR 0x50
#define EEPROM_I2C_BAUDRATE (400 * 1000)
#define MCP23017_I2C_INSTANCE i2c1
#define MCP23017_I2C_ADDR 0x23
#define MCP23017_I2C_BAUDRATE (100 * 1000)
#define ENABLE_MCP23017_PORT_0123 1
#define MCP23017_PORT_01 0x20
#define MCP23017_PORT_23 0x21
#define MCP23017_PORT_45 0x22
#define MCP23017_PORT_67 0x23
#define MCP23017_USBA 0x27
#define MCP23017_REG_IODIRA 0x00
#define MCP23017_REG_IODIRB 0x01
#define MCP23017_REG_OLATA 0x14
#define MCP23017_REG_OLATB 0x15
#define HEARTBEAT_PWM_FREQ_HZ 1000
#define HEARTBEAT_FADE_STEP_MS 8
#define TCA9548A_I2C_INSTANCE i2c1
#define TCA9548A_I2C_ADDR 0x70
#define PMIC_VMON_PORT7 0
#define PMIC_VMON_PORT6 1
#define PMIC_VMON_PORT5 2
#define PMIC_VMON_PORT4 3
#define PMIC_VMON_PORT3 4
#define PMIC_VMON_PORT2 5
#define PMIC_VMON_PORT1 6
#define PMIC_VMON_PORT0 7
#define VBUS_VMON_PORT0 8
#define VBUS_VMON_PORT1 9
#define VBUS_VMON_PORT2 10
#define VBUS_VMON_PORT3 11
#define VBUS_VMON_PORT4 12
#define VBUS_VMON_PORT5 13
#define VBUS_VMON_PORT6 14
#define VBUS_VMON_PORT7 15
#define PAC1720_I2C_INSTANCE i2c1
#define PAC1720_1_I2C_ADDR 0x4C
#define PAC1720_2_I2C_ADDR 0x18
#define PAC1720_RSENSE_OHM 0.02f
#define W5500_SPI_INSTANCE ETH_SPI_INSTANCE
#define SPI_SPEED_W5500 ETH_SPI_BAUDRATE
#define W5500_MOSI PIN_ETH_MOSI
#define W5500_MISO PIN_ETH_MISO
#define W5500_SCK PIN_ETH_SCK
#define W5500_CS PIN_ETH_CS
#define W5500_RESET PIN_ETH_RST
#define W5500_INT PIN_ETH_INT
#define I2C0_SDA PIN_I2C0_SDA
#define I2C0_SCL PIN_I2C0_SCL
#define I2C0_SPEED EEPROM_I2C_BAUDRATE
#define I2C1_SDA PIN_I2C1_SDA
#define I2C1_SCL PIN_I2C1_SCL
#define I2C1_SPEED MCP23017_I2C_BAUDRATE
#define EEPROM_I2C EEPROM_I2C_INSTANCE
#define EEPROM_SIZE 32768
#define DEFAULT_IP {192, 168, 0, 42}
#define DEFAULT_SUBNET {255, 255, 255, 0}
#define DEFAULT_GW {192, 168, 0, 1}
#define DEFAULT_DNS {8, 8, 8, 8}
#define DEFAULT_MAC {0x02, 0x00, 0x00, 0x60, 0x04, 0x42}
#define DEFAULT_DHCP 0
#define DEFAULT_DEVICE_NAME "PDNode-600 Pro"
#define DEFAULT_LOCATION    "Rack"
#define DEFAULT_SERIAL      "UNPROVISIONED"
#define PDNODE_MAC_PREFIX0  0x02u
#define PDNODE_MAC_PREFIX1  0x50u
#define PDNODE_MAC_PREFIX2  0x44u
#define PROV_UNLOCK_TOKEN       "61646d696e"
#define PROV_UNLOCK_TIMEOUT_MS  60000u
#define SNMP_PORT_AGENT 161
#define NET_TASK_CYCLE_MS 5
#define LOGGER_MSG_MAX 256
#define LOGGER_QUEUE_LEN 64
#define LOGGER_STACK_SIZE 1024
#define CONSOLE_STACK_SIZE 2048
#define ENABLE_CONSOLE_TASK 1
#define ENABLE_STORAGE_TASK 1
#define ENABLE_NET_TASK 1
#define ENABLE_PDCARD_TASK 1
#define ENABLE_USBA_TASK 1
#define ENABLE_HEARTBEAT_TASK 1
#define ENABLE_HEALTH_TASK 1
static inline void Storage_EnqueueErrorCode(uint16_t code) { (void)code; }
static inline void Storage_EnqueueWarningCode(uint16_t code) { (void)code; }
#define ERROR_PRINT_CODE(code, ...) ERROR_PRINT(__VA_ARGS__)
#define PWR_STATE_STANDBY 0xFF
static inline int Power_GetState(void) { return 0; }
void log_printf(const char *fmt, ...);
void log_printf_force(const char *fmt, ...);
#define DEBUG 1
#define DEBUG_HEALTH 0
#define INFO 1
#define INFO_HEALTH 0
#define PLOT_EN 0
#define NETLOG 0
#define UART_IFACE 1
#define ERROR 1
#define WARNING 1
#if DEBUG
#define DEBUG_PRINT(...) log_printf("\t[DEBUG] " __VA_ARGS__)
#else
#define DEBUG_PRINT(...) ((void)0)
#endif
#if DEBUG_HEALTH
#define DEBUG_PRINT_HEALTH(...) log_printf("\t[HEALTH] " __VA_ARGS__)
#else
#define DEBUG_PRINT_HEALTH(...) ((void)0)
#endif
#if INFO_HEALTH
#define HEALTH_INFO(...) log_printf("[INFO] " __VA_ARGS__)
#else
#define HEALTH_INFO(...) ((void)0)
#endif
#if INFO
#define INFO_PRINT(...) log_printf("[INFO] " __VA_ARGS__)
#else
#define INFO_PRINT(...) ((void)0)
#endif
#if ERROR
#define ERROR_PRINT(...) log_printf_force("[ERROR] " __VA_ARGS__)
#else
#define ERROR_PRINT(...) ((void)0)
#endif
#if ERROR && DEBUG
#define ERROR_PRINT_DEBUG(...) log_printf("[ERROR] " __VA_ARGS__)
#else
#define ERROR_PRINT_DEBUG(...) ((void)0)
#endif
#if WARNING
#define WARNING_PRINT(...) log_printf_force("[WARNING] " __VA_ARGS__)
#else
#define WARNING_PRINT(...) ((void)0)
#endif
#if PLOT_EN
#define PLOT(...) log_printf("\t[PLOT] " __VA_ARGS__)
#else
#define PLOT(...) ((void)0)
#endif
#if NETLOG
#define NETLOG_PRINT(...) log_printf("[NETLOG] " __VA_ARGS__)
#else
#define NETLOG_PRINT(...) ((void)0)
#endif
#if UART_IFACE
#define ECHO(...) log_printf_force(__VA_ARGS__)
#else
#define ECHO(...) ((void)0)
#endif

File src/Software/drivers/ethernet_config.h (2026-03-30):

/**
 * @file drivers/ethernet_config.h
 * @author DvidMakesThings - David Sipos
 *
 * @defgroup config02 2. W5500 Ethernet Configuration
 * @ingroup config
 * @brief Centralized configuration parameters for W5500 Ethernet controller.
 * @{
 *
 * @version 1.0.0
 * @date 2025-11-06
 *
 * @details
 * This file centralizes all configuration for the W5500 Ethernet controller. Configuration
 * includes:
 * - Hardware pin assignments and SPI settings
 * - Socket memory buffer allocation (16KB TX + 16KB RX total)
 * - Network parameters (IP, MAC, gateway, subnet)
 * - Protocol support flags (TCP, UDP, SNMP, ICMP)
 * - RTOS task and synchronization parameters
 * - Advanced TCP/IP tuning parameters
 *
 * Socket Buffer Strategy:
 * The W5500 provides 16KB each for TX and RX buffers, distributed across 8 sockets.
 * Current allocation prioritizes HTTP server (Socket 0) and SNMP (Socket 1).
 *
 * Configuration Philosophy:
 * - All hardware-specific values come from CONFIG.h
 * - Runtime-changeable parameters (IP, MAC) have defaults
 * - Compile-time validation prevents buffer overallocation
 *
 * @project PDNode - The Managed USB-C PDU Project for 10-Inch Rack
 * @github https://github.com/DvidMakesThings/HW_PDNode-600-Pro
 */

#ifndef W5500_CONFIG_H
#define W5500_CONFIG_H

#include "../CONFIG.h"

/**
 * @defgroup W5500_HW Hardware Pin Configuration
 * @brief SPI peripheral and GPIO pin assignments from CONFIG.h
 * @{
 */

/** @name Hardware Pins
 *  Constants for SPI and GPIO assignments.
 *  @{ */

/** SPI peripheral instance used for W5500 communication */
#define W5500_SPI W5500_SPI_INSTANCE

/** SPI clock frequency in Hz (typically 10-33 MHz) */
#define W5500_SPI_CLOCK SPI_SPEED_W5500

/** SPI MOSI (Master Out Slave In) GPIO pin */
#define W5500_PIN_MOSI W5500_MOSI

/** SPI MISO (Master In Slave Out) GPIO pin */
#define W5500_PIN_MISO W5500_MISO

/** SPI SCK (Serial Clock) GPIO pin */
#define W5500_PIN_SCK W5500_SCK

/** SPI CS (Chip Select, active low) GPIO pin */
#define W5500_PIN_CS W5500_CS

/** Hardware reset GPIO pin (active low) */
#define W5500_PIN_RST W5500_RESET

/** Interrupt GPIO pin (active low, optional) */
#define W5500_PIN_INT W5500_INT

/** @} */

/** @} */

/**
 * @defgroup W5500_MEM Socket Memory Allocation
 * @brief TX/RX buffer sizes for each socket (total 16KB per direction)
 * @{
 */

/** @name Socket Memory Sizes
 *  Per-socket TX/RX buffer allocations (KB).
 *  @{ */

/**
 * @brief Number of hardware sockets available
 */
#define W5500_SOCKET_COUNT 8

/** Socket 0 TX buffer size in KB (HTTP server, primary) */
#define W5500_TX_SIZE_S0 8

/** Socket 1 TX buffer size in KB (SNMP) */
#define W5500_TX_SIZE_S1 8

/** Socket 2 TX buffer size in KB (unused) */
#define W5500_TX_SIZE_S2 0

/** Socket 3 TX buffer size in KB (unused) */
#define W5500_TX_SIZE_S3 0

/** Socket 4 TX buffer size in KB (unused) */
#define W5500_TX_SIZE_S4 0

/** Socket 5 TX buffer size in KB (unused) */
#define W5500_TX_SIZE_S5 0

/** Socket 6 TX buffer size in KB (unused) */
#define W5500_TX_SIZE_S6 0

/** Socket 7 TX buffer size in KB (unused) */
#define W5500_TX_SIZE_S7 0

/** Socket 0 RX buffer size in KB (HTTP server, primary) */
#define W5500_RX_SIZE_S0 8

/** Socket 1 RX buffer size in KB (SNMP) */
#define W5500_RX_SIZE_S1 8

/** Socket 2 RX buffer size in KB (unused) */
#define W5500_RX_SIZE_S2 0

/** Socket 3 RX buffer size in KB (unused) */
#define W5500_RX_SIZE_S3 0

/** Socket 4 RX buffer size in KB (unused) */
#define W5500_RX_SIZE_S4 0

/** Socket 5 RX buffer size in KB (unused) */
#define W5500_RX_SIZE_S5 0

/** Socket 6 RX buffer size in KB (unused) */
#define W5500_RX_SIZE_S6 0

/** Socket 7 RX buffer size in KB (unused) */
#define W5500_RX_SIZE_S7 0

/** @} */

/** @} */

/**
 * @defgroup W5500_NET Network Configuration Defaults
 * @brief Default network parameters (overrideable at runtime)
 * @{
 */

/** @name Network Defaults
 *  Default MAC/IP/subnet/gateway/DNS settings.
 *  @{ */

/** Network defaults — sourced from CONFIG.h (single source of truth) */
#define W5500_DEFAULT_MAC     DEFAULT_MAC
#define W5500_DEFAULT_IP      DEFAULT_IP
#define W5500_DEFAULT_SUBNET  DEFAULT_SUBNET
#define W5500_DEFAULT_GATEWAY DEFAULT_GW
#define W5500_DEFAULT_DNS     DEFAULT_DNS
#define W5500_USE_DHCP        DEFAULT_DHCP

/** @} */

/** @} */

/**
 * @defgroup W5500_PROTO Protocol Support Flags
 * @brief Enable/disable protocol features
 * @{
 */

/** @name Protocol Flags
 *  Enable/disable supported protocols.
 *  @{ */

/** Enable TCP protocol support */
#define W5500_ENABLE_TCP 1

/** Enable UDP protocol support */
#define W5500_ENABLE_UDP 1

/** Enable SNMP protocol support */
#define W5500_ENABLE_SNMP 1

/** Enable ICMP (ping) support */
#define W5500_ENABLE_ICMP 1

/** Enable IPv6 support (reserved for future use) */
#define W5500_ENABLE_IPV6 0

/** @} */

/** @} */

/**
 * @defgroup W5500_RTOS RTOS Integration Parameters
 * @brief FreeRTOS task and synchronization settings
 * @{
 */
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

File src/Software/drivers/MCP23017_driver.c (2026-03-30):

/**
 * @file MCP23017_driver.c
 * @author DvidMakesThings - David Sipos
 *
 * @version 2.0.0
 * @date 2025-12-16
 *
 * @details
 * Complete rewrite of MCP23017 driver with simplified, deterministic design.
 *
 * Key Changes from v1.x:
 * - Removed redundant bus mutex (per-device mutex is sufficient)
 * - Simplified I2C operations with clear retry logic
 * - Direct error reporting to caller
 * - Cleaner separation of concerns
 *
 * Thread Safety:
 * - Each device has its own mutex
 * - All public APIs acquire mutex before I2C operations
 * - Shadow registers prevent torn read-modify-write
 *
 * @project PDNode - The Managed USB-C PDU Project for 10-Inch Rack
 * @github https://github.com/DvidMakesThings/HW_PDNode-600-Pro
 */

#include "../CONFIG.h"
#include "MCP23017_driver.h"
#include "i2c_bus.h"

#define MCP_TAG "[MCP]"

/*
 * CRITICAL: Do NOT use ERROR_PRINT or ERROR_PRINT_CODE in this driver!
 *
 * ERROR_PRINT calls Switch_SetFaultLed() which tries to acquire s_switch_mutex.
 * If we're called from SwitchTask (which already holds s_switch_mutex), this
 * causes a self-deadlock because s_switch_mutex is non-recursive.
 *
 * The task blocks for SWITCH_MUTEX_TIMEOUT_MS (1000ms) waiting on itself,
 * which is the root cause of "OLATA write took 1002 ms" during stress test.
 *
 * Use MCP_ERROR_CODE for driver errors - route through ERROR_PRINT_DEBUG to avoid LED.
 */
#define MCP_ERROR_CODE(code, fmt, ...)                                                             \
    do {                                                                                           \
        ERROR_PRINT_DEBUG("0x%04X " fmt, (unsigned)(code), ##__VA_ARGS__);                         \
    } while (0)

#define MCP_WARNING_CODE(code, fmt, ...)                                                           \
    do {                                                                                           \
        WARNING_PRINT("0x%04X " fmt, (unsigned)(code), ##__VA_ARGS__);                             \
    } while (0)

/* ==================== Device Registry ==================== */

/**
 * @brief Static array of registered devices.
 */
static mcp23017_t g_devices[MCP_MAX_DEVICES];

/**
 * @brief Number of registered devices.
 */
static size_t g_device_count = 0;

/**
 * @brief Global device pointers for board-specific MCPs.
 */
static mcp23017_t *g_mcp_relay = NULL;
static mcp23017_t *g_mcp_display = NULL;
static mcp23017_t *g_mcp_selection = NULL;

/* ==================== Internal I2C Operations ==================== */

/* ==================== Internal Helpers ==================== */

/**
 * @brief Find existing device by I2C bus and address.
 *
 * @param i2c I2C bus instance
 * @param addr 7-bit device address
 * @return Pointer to device context, or NULL if not found.
 */
static mcp23017_t *find_device(i2c_inst_t *i2c, uint8_t addr) {
    for (size_t i = 0; i < g_device_count; i++) {
        if (g_devices[i].i2c == i2c && g_devices[i].addr == addr) {
            return &g_devices[i];
        }
    }
    return NULL;
}

/**
 * @brief Pulse reset GPIO if configured.
 *
 * @param gpio Reset GPIO pin number
 */
static void pulse_reset(int8_t gpio) {
    if (gpio >= 0) {
        gpio_put((uint)gpio, 0);
        vTaskDelay(pdMS_TO_TICKS(MCP_RESET_PULSE_MS));
        gpio_put((uint)gpio, 1);
        vTaskDelay(pdMS_TO_TICKS(MCP_POST_RESET_MS));
    }
}

/* Diagnostic function removed: no-op to keep linkage if referenced */
static inline void mcp_diag_display_ping(mcp23017_t *dev, uint8_t reg_failed) {
    (void)dev;
    (void)reg_failed;
}

/* ==================== Public Device Registration ==================== */

mcp23017_t *mcp_register(i2c_inst_t *i2c, uint8_t addr, int8_t rst_gpio) {
    /* Validate parameters */
    if (!i2c || addr < 0x20 || addr > 0x27) {
#if ERRORLOGGER
        uint16_t errorcode = ERR_MAKE_CODE(ERR_MOD_BUTTON, ERR_SEV_ERROR, ERR_FID_MCP23017, 0x0);
        MCP_ERROR_CODE(errorcode, "%s Invalid register params: i2c=%p addr=0x%02X\r\n", MCP_TAG,
                       (void *)i2c, addr);
        // Storage_EnqueueErrorCode(errorcode);
#endif
        return NULL;
    }

    /* Check if already registered */
    mcp23017_t *existing = find_device(i2c, addr);
    if (existing) {
        return existing;
    }

    /* Check for registry space */
    if (g_device_count >= MCP_MAX_DEVICES) {
#if ERRORLOGGER
        uint16_t errorcode = ERR_MAKE_CODE(ERR_MOD_BUTTON, ERR_SEV_ERROR, ERR_FID_MCP23017, 0x1);
        MCP_ERROR_CODE(errorcode, "%s Device registry full\r\n", MCP_TAG);
        // Storage_EnqueueErrorCode(errorcode);
#endif
        return NULL;
    }

    /* Allocate new device slot */
    mcp23017_t *dev = &g_devices[g_device_count];
    memset(dev, 0, sizeof(*dev));

    dev->i2c = i2c;
    dev->addr = addr;
    dev->rst_gpio = rst_gpio;
    dev->olat_a = 0x00;
    dev->olat_b = 0x00;
    dev->inited = false;

    /* Create per-device mutex */
    dev->mutex = xSemaphoreCreateMutex();
    if (!dev->mutex) {
#if ERRORLOGGER
        uint16_t errorcode = ERR_MAKE_CODE(ERR_MOD_BUTTON, ERR_SEV_ERROR, ERR_FID_MCP23017, 0x2);
        MCP_ERROR_CODE(errorcode, "%s Mutex create failed for addr=0x%02X\r\n", MCP_TAG, addr);
        // Storage_EnqueueErrorCode(errorcode);
#endif
        return NULL;
    }

    /* Initialize reset GPIO if used */
    if (rst_gpio >= 0) {
        gpio_init((uint)rst_gpio);
        gpio_set_dir((uint)rst_gpio, GPIO_OUT);
        gpio_put((uint)rst_gpio, 1); /* Active-low reset, keep high */
    }

    g_device_count++;
    /* Debug print removed */

    return dev;
}
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

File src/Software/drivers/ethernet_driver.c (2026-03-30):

/**
 * @file src/drivers/ethernet_driver.c
 * @author DvidMakesThings - David Sipos
 *
 * @version 1.2.0
 * @date 2025-12-10
 * @details
 * Unified RTOS-compatible W5500 driver combining HAL, SPI, and configuration.
 * Thread-safe with FreeRTOS mutex protection for all SPI operations.
 *
 * v1.2.0 Changes:
 * - CRITICAL: Added timeout protection to w5500_get_tx_fsr() and w5500_get_rx_rsr()
 *   to prevent infinite loops during heavy network traffic
 * - PERFORMANCE: Replaced byte-by-byte SPI with bulk transfers using
 *   spi_write_blocking() and spi_read_blocking() for multi-byte operations
 * - Added w5500_read_reg16() for efficient 16-bit register reads
 * - Reduced SPI overhead by ~4x for bulk data transfers
 *
 * @project PDNode - The Managed USB-C PDU Project for 10-Inch Rack
 * @github https://github.com/DvidMakesThings/HW_PDNode-600-Pro
 */

#include "../CONFIG.h"
#include "ethernet_config.h"
#include "ethernet_driver.h"

/******************************************************************************
 *                          PRIVATE DEFINITIONS                               *
 ******************************************************************************/

#define ETH_TASK_TAG "[W5500]"

/* W5500 SPI command prefixes */
#define W5500_SPI_READ 0x00
#define W5500_SPI_WRITE 0x04
#define W5500_SPI_VDM_OP 0x00

/* Maximum retries for FSR/RSR consistency loops (prevents infinite loop) */
#define MAX_FSR_RSR_RETRIES 10

/******************************************************************************
 *                          PRIVATE VARIABLES                                 *
 ******************************************************************************/

/* SPI mutex for thread-safe access */
SemaphoreHandle_t w5500_spi_mutex = NULL;

/* Callback function pointers */
static void (*_cris_enter)(void) = NULL;
static void (*_cris_exit)(void) = NULL;
static void (*_cs_select)(void) = NULL;
static void (*_cs_deselect)(void) = NULL;
static uint8_t (*_spi_read_byte)(void) = NULL;
static void (*_spi_write_byte)(uint8_t) = NULL;

/******************************************************************************
 *                          SPI LOW-LEVEL FUNCTIONS                           *
 ******************************************************************************/

/**
 * @brief CS select (pull CS low)
 */
static inline void _w5500_cs_select(void) { gpio_put(W5500_PIN_CS, 0); }

/**
 * @brief CS deselect (pull CS high)
 */
static inline void _w5500_cs_deselect(void) { gpio_put(W5500_PIN_CS, 1); }

/**
 * @brief SPI read single byte
 */
static uint8_t _w5500_spi_read(void) {
    uint8_t rx_data = 0;
    uint8_t tx_data = 0xFF;
    spi_read_blocking(W5500_SPI, tx_data, &rx_data, 1);
    return rx_data;
}

/**
 * @brief SPI write single byte
 */
static void _w5500_spi_write(uint8_t tx_data) { spi_write_blocking(W5500_SPI, &tx_data, 1); }

/**
 * @brief Critical section enter (acquire mutex)
 */
static void _w5500_cris_enter(void) {
    if (w5500_spi_mutex) {
        xSemaphoreTake(w5500_spi_mutex, portMAX_DELAY);
    }
}

/**
 * @brief Critical section exit (release mutex)
 */
static void _w5500_cris_exit(void) {
    if (w5500_spi_mutex) {
        xSemaphoreGive(w5500_spi_mutex);
    }
}

/******************************************************************************
 *                          W5500 REGISTER ACCESS                             *
 ******************************************************************************/

/**
 * @brief Read single byte from W5500 register (optimized bulk SPI)
 * @param addr_sel Register address with block select
 * @return Register value
 */
uint8_t w5500_read_reg(uint32_t addr_sel) {
    uint8_t spi_data[4];
    uint8_t rx_data[4];

    _cris_enter();
    _cs_select();

    addr_sel |= (W5500_SPI_READ | W5500_SPI_VDM_OP);

    /* Prepare address + control phase */
    spi_data[0] = (addr_sel & 0x00FF0000) >> 16;
    spi_data[1] = (addr_sel & 0x0000FF00) >> 8;
    spi_data[2] = (addr_sel & 0x000000FF) >> 0;
    spi_data[3] = 0xFF; /* Dummy byte for read */

    /* Single bulk transfer: 3 address bytes + 1 read byte */
    spi_write_read_blocking(W5500_SPI, spi_data, rx_data, 4);

    _cs_deselect();
    _cris_exit();

    return rx_data[3];
}

/**
 * @brief Read 16-bit value from W5500 register (optimized for FSR/RSR)
 * @param addr_sel Base register address with block select
 * @return 16-bit register value (big-endian converted)
 * @note Reads two consecutive bytes in a single SPI transaction
 */
static uint16_t w5500_read_reg16(uint32_t addr_sel) {
    uint8_t spi_data[5];
    uint8_t rx_data[5];

    _cris_enter();
    _cs_select();

    addr_sel |= (W5500_SPI_READ | W5500_SPI_VDM_OP);

    /* Prepare address + control phase */
    spi_data[0] = (addr_sel & 0x00FF0000) >> 16;
    spi_data[1] = (addr_sel & 0x0000FF00) >> 8;
    spi_data[2] = (addr_sel & 0x000000FF) >> 0;
    spi_data[3] = 0xFF; /* Dummy for high byte */
    spi_data[4] = 0xFF; /* Dummy for low byte */

    /* Single bulk transfer: 3 address bytes + 2 read bytes */
    spi_write_read_blocking(W5500_SPI, spi_data, rx_data, 5);

    _cs_deselect();
    _cris_exit();

    return ((uint16_t)rx_data[3] << 8) | rx_data[4];
}

/**
 * @brief Write single byte to W5500 register (optimized bulk SPI)
 * @param addr_sel Register address with block select
 * @param wb Byte to write
 */
void w5500_write_reg(uint32_t addr_sel, uint8_t wb) {
    uint8_t spi_data[4];

    _cris_enter();
    _cs_select();

    addr_sel |= (W5500_SPI_WRITE | W5500_SPI_VDM_OP);

    /* Prepare address + control phase + data */
    spi_data[0] = (addr_sel & 0x00FF0000) >> 16;
    spi_data[1] = (addr_sel & 0x0000FF00) >> 8;
    spi_data[2] = (addr_sel & 0x000000FF) >> 0;
    spi_data[3] = wb;

    /* Single bulk transfer: 3 address bytes + 1 data byte */
    spi_write_blocking(W5500_SPI, spi_data, 4);

    _cs_deselect();
    _cris_exit();
}

/**
 * @brief Read multiple bytes from W5500 (optimized bulk transfer)
 * @param addr_sel Base address with block select
 * @param pBuf Destination buffer
 * @param len Number of bytes to read
 */
void w5500_read_buf(uint32_t addr_sel, uint8_t *pBuf, uint16_t len) {
    uint8_t spi_header[3];

    if (!pBuf || len == 0)
        return;

    _cris_enter();
    _cs_select();

    addr_sel |= (W5500_SPI_READ | W5500_SPI_VDM_OP);

    /* Send address + control phase */
    spi_header[0] = (addr_sel & 0x00FF0000) >> 16;
    spi_header[1] = (addr_sel & 0x0000FF00) >> 8;
    spi_header[2] = (addr_sel & 0x000000FF) >> 0;

    spi_write_blocking(W5500_SPI, spi_header, 3);

    /* Bulk read data phase */
    spi_read_blocking(W5500_SPI, 0xFF, pBuf, len);

    _cs_deselect();
    _cris_exit();
}
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

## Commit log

2025-05-02 Start hardware design
    [PDNode-600 Pro.sch]
2025-05-05 Hardware design update
    [PDNode-600 Pro.brd, PDNode-600 Pro.sch]
2025-05-06 Update hardware design files
    [PDNode-600 Pro.brd, PDNode-600 Pro.sch]
2025-05-07 Add BOM
    [PDNode-600 Pro.brd, PDNode-600 Pro.sch, PDNode-600 Pro_top_bom.csv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]
2025-05-22 Update RESET and BOOT part values in hardware design files
    [PDNode-600 Pro.brd, PDNode-600 Pro.sch]
2026-02-04 Project ramp-up: KiCad transition. Board redesign
    [BOM-PDNode-600.csv, Block Diagram.kicad_sch, PDNode-600 Pro.brd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]
2026-02-05 update component lib
    [BOM-PDNode-600.csv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]
2026-02-05 Baseboard design start
    [Block Diagram.kicad_sch, PDNode-PDCard.kicad_pcb, PDNode-PDCard.kicad_sch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]
2026-02-09 Add bladecore to design
    [B84771A3015A000.dxf, B84771A3015A000_2.dxf, BOM-BladeCore-M54.csv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]
2026-02-17 almost finished baseboard
    [B84771A3015A000.dxf, B84771A3015A000_2.dxf, BOM-BladeCore-M54.csv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]
2026-02-17 M54 rework
    [BOM-PDNode_Baseboard.csv, BladeCore-M54.kicad_pcb, BladeCore-M54.kicad_sch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]
2026-02-24 baseboard development
    [Block Diagram.kicad_sch, PDNode_Baseboard.kicad_sch, Power - Sequencing.kicad_sch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]
2026-02-26 add PDCard-4242 with lower profile
    [Block Diagram.kicad_sch, PDNode-PDCard-4242.kicad_pcb, PDNode-PDCard-4242.kicad_sch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]
2026-02-27 hardware design is close to final status
    [B84771A3015A000.dxf, B84771A3015A000_2.dxf, BOM-BladeCore-M54.csv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]
2026-03-01 update readme, add documentation
    [BOM-BladeCore-M54E.csv, BOM-PDNode-PDCard-4242.csv, BOM-PDNode_Baseboard.csv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]
2026-03-06 finalized 1.0.0 revision, PCB, PCBA ordered
    [BOM-PDNode-PDCard-4242.csv, BOM-PDNode_Baseboard.csv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]
2026-03-30 minor fixes, start with software
    [BOM-BladeCore-M54E.csv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]
2026-03-30 fix current reading bug
    [ConsoleTask.c, PAC1720_driver.c, USBATask.c]

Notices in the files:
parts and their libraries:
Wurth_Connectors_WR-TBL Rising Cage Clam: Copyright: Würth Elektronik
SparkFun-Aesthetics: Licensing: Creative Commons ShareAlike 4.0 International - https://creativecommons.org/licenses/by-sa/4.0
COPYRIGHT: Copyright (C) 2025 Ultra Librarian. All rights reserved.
